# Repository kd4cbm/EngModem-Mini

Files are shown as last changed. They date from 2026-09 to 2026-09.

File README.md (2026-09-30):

# EngModem Mini

A retro dial-up-modem-styled ESP32-S3 board: RS-232 (true DCE levels via
MAX3237), a 24x2 character VFD status display, a microSD card slot, 8
status LEDs, and USB-C, built around the ESP32-S3-WROOM-1U module. Runs
[Zimodem](https://github.com/BoZimmerman/Zimodem) - Bo Zimmerman's Hayes
AT-command modem emulator/internet gateway - via the
[Zimodem-VFD](https://github.com/kd4cbm/Zimodem-VFD) fork, which adds the
VFD status display this board uses. The firmware qualified on this exact
hardware, further specialised for it, is included in [`firmware/`](firmware/).

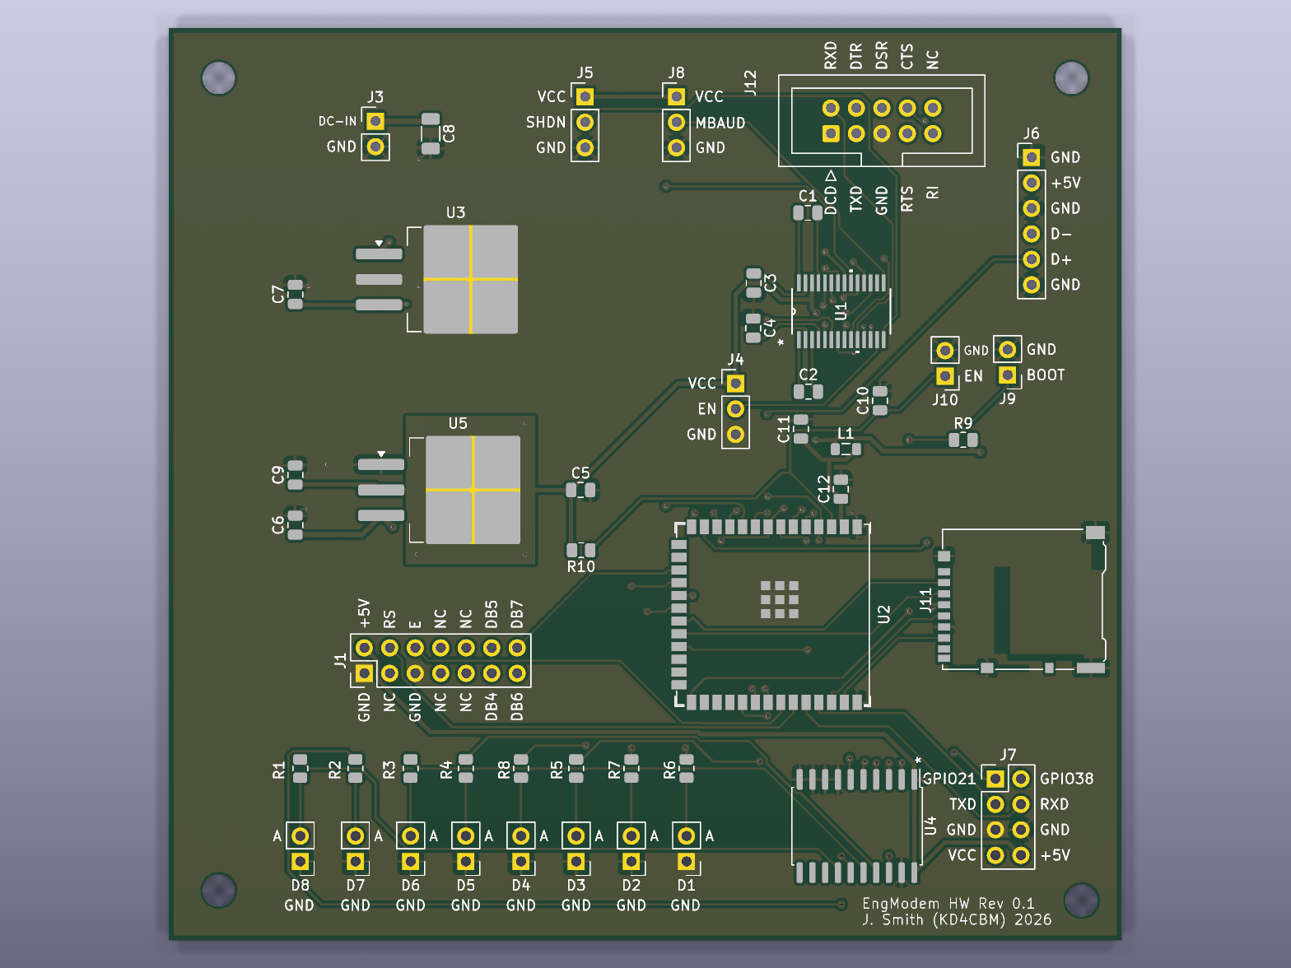
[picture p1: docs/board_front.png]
Front

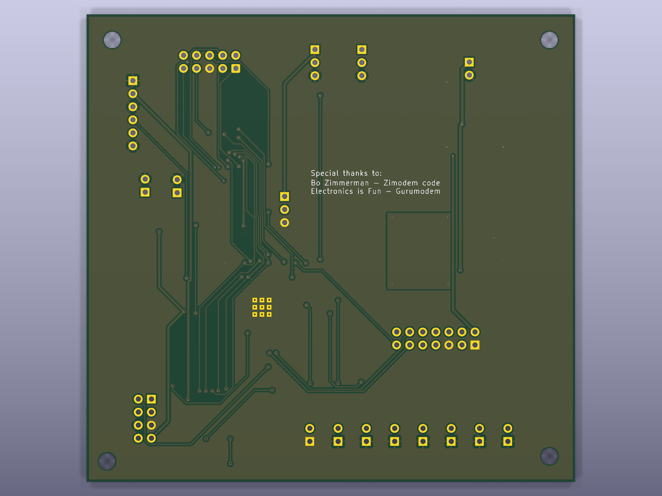
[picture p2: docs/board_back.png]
Back


## Status: Rev5 built and functionally qualified

One Rev5 board has been built, brought up and bench-qualified with the firmware
in [`firmware/`](firmware/) (revision `firmware-v7-rev1`), September 2026:
programming over USB, boot and debug UART, WiFi, microSD, the VFD, the status
LEDs, RS-232 at every rate from 300 to 921600 baud, RTS/CTS flow control, DTR,
DCD and RI, and byte-exact data integrity through TCP connections. The full
results - and, just as importantly, **what was not tested** (no rail-voltage or
signal-level measurements, single unit, no long soak, no ESD/EMC) - are in
[`docs/QUALIFICATION.md`](docs/QUALIFICATION.md).

Bring-up turned up a few things worth knowing **before you build one**:

- **J12's pin order does not match most ready-made header-to-DE-9 cables** and
  the board will appear dead with one - see [`docs/J12_CABLE_GUIDE.md`](docs/J12_CABLE_GUIDE.md).
- **Three MAX3237 jumpers (J4/J5/J8) must be fitted** - see the jumper table in
  [`docs/BRING_UP.md`](docs/BRING_UP.md#3-set-the-jumpers).
- U3/U5 are hand-soldered and U5 was substituted - see [`docs/ERRATA.md`](docs/ERRATA.md).
- **Most front-panel LEDs read inverted on boards with the original U4.** MR, TR, SD, RD and CD go
  through U4, originally a non-inverting buffer, from active-low signals, so they were lit when they
  should be dark. The firmware corrects OH, AA and HS; replacing U4 with a pin-compatible inverting
  part (a TI CD74HCT640M) fixes the rest and has been **built and verified on hardware** -
  see [`docs/ERRATA.md`](docs/ERRATA.md#e11-most-front-panel-leds-read-inverted).
  Also **check the LED order at assembly** (two LEDs were swapped on the tested unit).
- The design-stage "all pins match the firmware" check missed signal direction and LED
  polarity; nine firmware and design issues were found and eight fixed in firmware during
  qualification (the LED inversion of five LEDs needs a hardware change) - see
  [`docs/ERRATA.md`](docs/ERRATA.md#e3-earlier-pin-cross-check-missed-signal-direction) and
  [`docs/QUALIFICATION.md`](docs/QUALIFICATION.md).
- **Use RTS/CTS for long transfers.** With flow control off, a long full-speed two-way stream
  can still lose data (the receive-buffer bug behind most of that is fixed in firmware v6b) -
  see [`docs/ERRATA.md`](docs/ERRATA.md#e12-serial-receive-buffer-was-256-bytes-not-4096-fixed-in-firmware-v6b).

This is a functional qualification of a single unit, not a compliance test.
Expect further revisions.

## Special thanks

This board exists to run [Bo Zimmerman](http://www.zimmers.net)'s
[Zimodem](https://github.com/BoZimmerman/Zimodem) - the Hayes AT-command
modem emulator this whole project is built around. None of this would
have a reason to exist without that project. Thank you, Bo.

## Board overview

- ESP32-S3-WROOM-1U (external U.FL antenna), 16MB flash / 8MB octal PSRAM
- MAX3237-based RS-232 level shifting, wired as **DCE** (straight-through
  DE-9 cable to a PC/terminal) - full modem control set: TXD, RXD, RTS,
  CTS, DTR, DSR, DCD, RI
- Noritake CU24025ECPB-W1J 24x2 character VFD, direct 4-bit parallel
  drive (no I2C bridge)
- microSD card slot (Hirose DM3AT-SF-PEJM5), dedicated SPI pins
- 8 status LEDs, including 3 direct-GPIO-driven (AA/HS/OH)
- USB-C (native USB-Serial-JTAG)
- 2-layer PCB, routed with [Freerouting](https://github.com/freerouting/freerouting) 2.3.0

## Verification

**Design checks** - every revision was checked with KiCad's own tools before
being carried forward:

- **ERC**: 32/32 clean (no unsuppressed errors/warnings)
- **DRC**: 1 finding, a pre-existing benign silkscreen-overlap warning on
  U1; 0 unconnected nets
- **Footprint/schematic sync**: clean
- **Firmware/hardware cross-check (design stage)**: every GPIO the firmware
  references was traced against the schematic netlist pin-by-pin - 18/18
  matched **by GPIO number and net name**. That check did not compare signal
  *direction* and so missed a reversed RTS/CTS assignment, found later on the
  real board and fixed in the firmware; see
  [`docs/ERRATA.md`](docs/ERRATA.md#e3-earlier-pin-cross-check-missed-signal-direction).

**Hardware qualification** - a real Rev5 board, tested on the bench with the
included firmware: [`docs/QUALIFICATION.md`](docs/QUALIFICATION.md).

## Prerequisite libraries

This project uses two public third-party KiCad libraries that aren't
bundled here - install both via KiCad's **Plugin and Content Manager**
before opening the project:

- **Espressif KiCad libraries** (`com_github_espressif_kicad-libraries`) -
  ESP32-S3-WROOM-1U symbol/footprint
- **MAX3237** - U1's symbol/footprint

The project's one genuinely custom dependency, a small `RetroWiFiModem`
library providing the SOIC-20W bus-transceiver symbol/footprint used at U4
(both the original 74HCT245 and the CD74HCT640M it was replaced with share
the symbol's underlying pinout), is bundled under
[`hardware/kicad/libraries/`](hardware/kicad/libraries/) and wired up via
the project-local `sym-lib-table`/`fp-lib-table`, so it
resolves automatically - no separate install needed for that one.

## RS-232 (J12) - DE-9 female, DCE pinout

DCE pinout in the **AT/Everex header order** (header pin *n* = DE-9 pin *n*) -
wire straight-through to a DTE (PC/terminal). **Many ready-made header-to-DE-9
cables use a different (DTK/Intel) order and will not work** - read
[`docs/J12_CABLE_GUIDE.md`](docs/J12_CABLE_GUIDE.md):

| Pin | 1 | 2 | 3 | 4 | 5 | 6 | 7 | 8 | 9 |
|---|---|---|---|---|---|---|---|---|---|
| Signal | DCD | RXD | TXD | DTR | GND | DSR | RTS | CTS | RI |

Full connector/power-regulation detail (including the U3/U5 substitution
below) is in [`PIN_MAP.md`](PIN_MAP.md); a running changelog is in
[`CHANGES.md`](CHANGES.md).

## Files

- [`firmware/`](firmware/) - the qualified firmware: source, prebuilt
  binaries with checksums, and the hardware QA test scripts (start with its
  [README](firmware/README.md))
- [`docs/`](docs/) - [`BRING_UP.md`](docs/BRING_UP.md) (builder's guide:
  jumpers, first power, flashing, troubleshooting),
  [`QUALIFICATION.md`](docs/QUALIFICATION.md) (test report),
  [`ERRATA.md`](docs/ERRATA.md) (known issues),
  [`J12_CABLE_GUIDE.md`](docs/J12_CABLE_GUIDE.md) (cabling)
- [`hardware/kicad/`](hardware/kicad/) - full KiCad 10 project (schematic
  + PCB), current as of **Rev5**
- [`hardware/kicad/libraries/`](hardware/kicad/libraries/) - bundled
  custom library (see [Prerequisite libraries](#prerequisite-libraries))
- [`enclosure/`](enclosure/) - Hammond 1455U2201BK panel drill/router jigs
  (front: VFD window, LEDs, mounting holes; rear: DB9, USB-C, power
  jack/switch, boot/reset, external antenna) - see its own
  [README](enclosure/README.md) for the preliminary-hardware disclaimer
  and usage instructions
- [`manufacturing/Gerbers_EngModem-Mini_Rev5.zip`](manufacturing/Gerbers_EngModem-Mini_Rev5.zip) -
  Gerber + Excellon drill files, ready to upload to a fab
- [`manufacturing/BOM_PCBA_JLCPCB.csv`](manufacturing/BOM_PCBA_JLCPCB.csv) -
  bill of materials for the SMD parts JLCPCB will assemble, with LCSC part
  numbers verified against LCSC's own listings where a specific
  manufacturer part is called for. Common passives (resistors, most
  capacitors) intentionally list full specs with no pinned LCSC number -
  JLCPCB's basic-parts catalog is a live, dynamic search that isn't
  reliably scriptable, and these are common enough values that matching
  one at checkout takes seconds. **U3, U4 and U5 are intentionally excluded**
  - see below.
- [`manufacturing/BOM_full.csv`](manufacturing/BOM_full.csv) - every part
  on the board, including the through-hole connectors, headers, LED
  positions, and U3/U5, for your own hand-assembly shopping list
- [`manufacturing/CPL_SMD.csv`](manufacturing/CPL_SMD.csv) - placement
  (component position) file for the JLCPCB-assembled SMD parts, in
  JLCPCB's expected column format (`Designator, Mid X, Mid Y, Layer,
  Rotation`), generated directly from the PCB's real component
  coordinates. U3, U4 and U5 excluded, same as the PCBA BOM.

Gerbers + BOM_PCBA_JLCPCB + CPL_SMD together are what JLCPCB's PCBA
(assembly) order flow asks for. **Before ordering, check every SMD part's
orientation and position in JLCPCB's assembly preview tool** - their
preview renders whichever specific LCSC library part it matched to each
BOM row, using that part's own reference point, which doesn't always
agree with KiCad's footprint origin (for angle *or* position). Their
preview UI lets you nudge/rotate a part and save the correction directly,
no file regeneration needed - do that check first, especially for U1
(MAX3237EIPWR) and U2 (the ESP32 module).

### U3 and U5 - excluded from PCBA, hand-solder these

JLCPCB's placement preview surfaced a real footprint mismatch on both
regulators: the originally spec'd parts (HGSEMI LM7805S2/TR for U3, ST
LD1086D2T33TR for U5) don't reliably match this board's 3-lead D2PAK/
TO-263-3 footprint - LCSC's own listings show both as 2-lead packages
(and JLCPCB's 3D model for U3 shows "TO263-5" case marking), while ST's
LD1086 datasheet itself defines two different D²PAK mechanical variants
under one ambiguous order code. Rather than risk a bad PCBA placement,
both are DNP for JLCPCB assembly - `BOM_full.csv` lists verified
replacement parts to hand-solder instead, sourced from Mouser/DigiKey:

- **U3**: onsemi **MC7805CD2TR4G** (D2PAK-3, CASE 936) - confirmed via
  onsemi's own MC7800 datasheet: Pin 1=Input, Pin 2=Ground=Tab, Pin
  3=Output, an exact match to this footprint and the schematic.
- **U5**: TI **LM1086CSX-3.3/NOPB** (DDPAK/TO-263, package KTT; the
  qualified board uses the in-stock **LM1086IS-3.3/NOPB**, same package and
  pinout, industrial temp grade) -
  confirmed via TI's own datasheet: Pin 1=ADJ/GND, Pin 2+Tab=Output, Pin
  3=Input, an exact match to this footprint and the schematic (tab wired
  to Output by design).

### U4 - excluded from PCBA, hand-solder this

Unlike U3/U5, this wasn't a footprint mismatch - the schematic's generic 74HCT245 (non-inverting)
placed and worked fine, but reads five front-panel LEDs inverted (see
[`docs/ERRATA.md`](docs/ERRATA.md#e11-most-front-panel-leds-read-inverted)). The fix is a
pin/package-compatible **inverting** part, TI **CD74HCT640M** (SOIC-20-300mil, same footprint) - hand-swapped
on the qualified unit and verified correct (2026-09-29; a pad was pulled during desoldering and needed a
trace/pad-level repair, worth planning for). LCSC **C1548168** - 0 units in LCSC's own direct stock at
last check, ~3,000 available through LCSC's Other Suppliers channel at a 9-18 business day lead time
(checked 2026-09-29, re-verify before ordering) - excluded here pending confirmed assembly-line stock.
Must be the **HCT** variant, not HC (HC doesn't meet the 3.3V input threshold at 5V).

## Revision history

| Rev | Notes |
|---|---|
| 0-1 | Original modular layout and placement baseline |
| 2 | SD card socket swapped from a pin header to the real microSD socket (Hirose DM3AT-SF-PEJM5); full reroute |
| 3 | Second SD placement experiment; full reroute; 69 net-derived pin-function silkscreen labels added across every header/LED footprint |
| 4 | Dedicated 0.5mm net class for `/DC-IN`; solid (non-thermal-relief) zone connections on regulator/shield GND tabs; local `/VCC` copper pour + thermal vias around U5; ESP32 power-filter components (L1/C11/C12) relocated for shorter real routed-copper paths to U2 |
| 5 | **Current** - via stitching added under U2's ground-pad cluster (9 vias, exposed copper + matching pads mirrored onto the bottom layer) for bottom-side hand-soldering access; keepout zone added around that cluster, full rip/reroute; U3/U5 excluded from PCBA per the footprint mismatch below |

## License

Hardware design files (schematic, PCB) are released under
[CERN-OHL-S v2](https://cern-ohl.web.cern.ch/) - a strongly-reciprocal
open hardware license: modifications to these design files must be
released under the same license if you distribute hardware built from
them. See [LICENSE](LICENSE).

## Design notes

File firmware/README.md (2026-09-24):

# EngModem Mini firmware (Zimodem-VFD, `ENGMODEM_MINI_BOARD`)

This folder is the firmware that was qualified on the real EngModem Mini
hardware - see [`../docs/QUALIFICATION.md`](../docs/QUALIFICATION.md) for what
was tested and how. It is a fork of Bo Zimmerman's
[Zimodem](https://github.com/BoZimmerman/Zimodem) (Hayes AT-command modem
emulator / internet gateway), via the
[Zimodem-VFD](https://github.com/kd4cbm/Zimodem-VFD) fork that adds the 24x2 VFD
status display, further specialised for this board with the
`ENGMODEM_MINI_BOARD` build flag (already `#define`d near the top of
`zimodem/zimodem.ino`).

**Revision:** `firmware-v7-rev1` - Zimodem 4.0.3 base, sdk v5.5.5,
ESP32 Arduino core 3.3.11. Every change from upstream is listed in
[`CHANGES.md`](CHANGES.md); the numbered fix rounds (v1 to v7) are listed
there too. Apache-2.0, see [`LICENSE`](LICENSE) and [`NOTICE`](NOTICE) (the
*hardware* in the rest of this repo is CERN-OHL-S v2).

| Folder / file | What it is |
|---|---|
| [`zimodem/`](zimodem/) | Arduino sketch source (`zimodem.ino` + tabs, bundled `src/libssh2`) |
| [`bin/`](bin/) | The exact binaries flashed and qualified on the board (v7-rev1), with `SHA256SUMS.txt` |
| [`tests/`](tests/) | The Python hardware QA scripts used for qualification |
| [`PIN_MAP.md`](PIN_MAP.md) | ESP32-S3 GPIO to signal mapping this firmware expects |
| [`CHANGES.md`](CHANGES.md) | Full change list vs. upstream, with the reason for each |

## Quick start: flash the prebuilt firmware

You need Python and [esptool](https://github.com/espressif/esptool)
(`pip install esptool`; the commands below are esptool 5.x syntax - with 4.x
use `write_flash` instead of `write-flash`).

1. **Jumpers first** - the board will not talk RS-232 without them. See
   [`../docs/BRING_UP.md`](../docs/BRING_UP.md#3-set-the-jumpers). In short:
   **J9 (BOOT) must be OFF** to run the firmware, J4 = 2-3, J5 = 1-2,
   J8 = 1-2.
2. Connect USB (header **J6**) and find the port (Windows: Device Manager >
   Ports; Linux: `/dev/ttyACM0`).
3. Flash the four images. Run from inside `firmware/bin/`:

```bash
python -m esptool --chip esp32s3 -p COM7 -b 460800 \
  --before default-reset --after hard-reset \
  write-flash --flash-mode dio --flash-freq 80m --flash-size 16MB \
  0x0     zimodem.ino.bootloader.bin \
  0x8000  zimodem.ino.partitions.bin \
  0xe000  boot_app0.bin \
  0x10000 zimodem.ino.bin
```

Replace `COM7` with your port. The chip resets itself into the bootloader over
native USB, so no button presses were needed on the tested board. If it does
not enter the bootloader, fit the **J9 BOOT** jumper, briefly short **J10 (EN)**
or power-cycle, flash, then **remove J9 again** and reset.

A single merged 16 MB image (`zimodem.ino.merged.bin`, flash at `0x0`) is
attached to the matching GitHub Release. Its layout was checked byte-for-byte
against the four images above; the four-image command is what was run on the
tested hardware.

Verify what you flashed against [`bin/SHA256SUMS.txt`](bin/SHA256SUMS.txt)
(`sha256sum -c SHA256SUMS.txt` in `bin/`).

## Debug output (important)

Boot messages, the `AT&O88` signal log and the
`Flow control pins: CTS(in)=17 RTS(out)=18` line are printed on the
**debug UART - header J7** (pin 3 = board TX, pin 4 = board RX, pins 5/6 =
GND; 3.3 V logic, 115200 8N1), **not** over USB. A 3.3 V USB-serial adapter
on J7 is all you need. (Earlier text in the upstream fork's README, saying
USB-CDC is the debug path, is wrong for this code.)

A healthy boot on the QA'd board shows, among other lines:
`External SD card initialized.`, `Connected to <ssid> with IP <ip>.` and
`Flow control pins: CTS(in)=17 RTS(out)=18`.

## First use

- Factory default is **1200 baud, 8N1, flow control off**. The unit that was
  qualified was configured to 115200 (`ATB115200`, reconnect the terminal at
  115200, then `AT&W` to save).
- `AT+CONFIG` walks you through WiFi (2.4 GHz only) and other settings.
- `ATI` shows version, chip and current IP.
- `AT&K3` enables RTS/CTS flow control, `AT&K0` disables it. Flow control was
  **left off** in qualification except during the flow-control tests.
- `ATS63=2` makes the modem hang up when the host drops DTR (verified on this
  board with firmware v3 and later; not possible before).
- The VFD shows WiFi/IP, TX/RX activity, baud rate and flow-control mode.
  `AT$VFDB=0..4` sets brightness (0 = off, 4 = 100 %).
- Full command reference: upstream Zimodem's documentation, plus the
  `AT+SHELL` SD-card shell (`?` lists its commands).

## Building from source

Tested with `arduino-cli` 1.5.2 and the `esp32:esp32` core **3.3.11**. No extra
libraries are needed (libssh2 is bundled under `zimodem/src`).

```bash
arduino-cli compile \
  --fqbn esp32:esp32:esp32s3:FlashSize=16M,PSRAM=opi,PartitionScheme=default_8MB,CDCOnBoot=cdc \
  --build-path build zimodem
```

That produces the four images above under `build/` (39 % of program storage,
17 % of RAM). A different core version may change behaviour: the v4 serial-to-TCP
fix exists because of how core 3.x's socket write retries behave, and the v6b
receive-buffer fix because core 3.x only accepts `setRxBufferSize()` before
`begin()` (see [`CHANGES.md`](CHANGES.md)). Rebuilding will not reproduce the released
binaries bit-for-bit (timestamps are embedded), which is why the exact
released binaries and their checksums are included.

## Known limits of this revision

- **Recommended baud rate: 230400 if your UART can do it, otherwise 115200.** 115200 is the rate any
  UART supports, including plain onboard PC ports (the native 16550 COM port used in qualification
  topped out there). 230400 is the fastest rate we can guarantee, and only on UARTs that accept custom
  rates above 115200 (typically USB-serial adapters); not every such adapter supports 460800 or
  921600. Going faster buys little: connected-mode throughput is flat at ~17.3-17.9 KB/s from 230400
  through 921600 (WiFi/CPU-bound, not line-bound), and one-way transfers plateau near 30.8 KB/s from
  460800 up. If your UART accepts custom rates you can likely exceed 230400 by a decent margin, but
  that is not guaranteed on all hardware. The modem itself ran byte-exact at 460800 and 921600 on the
  USB-FTDI adapter used in qualification.
- **Flow control off has a ceiling.** With RTS/CTS off and data flowing in *both* directions
  at full 115200 line rate for a long time (tested with a PC echo server), the modem forwards slightly
  slower than a full-speed sender can push, so a very long stream can still lose data. Measured on the
  qualified unit: echo streams up to 40 KB were clean in all 20 runs, sustained ~60 KB lost data in one
  of two runs; one-way transfers (PC sending, network receiving) were lossless up to 100 KB. **Use
  RTS/CTS (`AT&K3`) for long transfers** - it was byte-exact in every test, including 100 KB streams at
  230400, 460800 and 921600 baud. An occasional "1 byte short on the echo return" seen in flow-off echo
  runs also appears in earlier revisions; its cause is unknown.
- Serial-to-TCP data is buffered for up to 10 ms (2 ms after the last byte) to avoid the stall
  described in `CHANGES.md`. Keystroke round-trip through a TCP echo on a home network measured a median
  of 45-61 ms; the 365-430 ms worst-case tail is ESP32 WiFi power-save.
- In *command mode* the modem processes roughly 4.6 KB/s regardless of line speed; flow control keeps
  data intact above that, but it is a ceiling. In connected (stream) mode throughput measured
  ~11 KB/s at 115200 and ~17.5 KB/s at 230400-921600 (WiFi/CPU-bound, not line-bound).
- The VFD init is now self-repairing (resync at boot, re-sent about once a second during the 7 s
  splash window). If the display is blank, check the J1 wiring first, then reset.
- **LED behaviour:** AA, HS and OH are corrected in firmware (they light when active). MR, TR, SD, RD
  and CD are driven through U4 in hardware and read *inverted* on Rev5 as built - see
  [`../docs/ERRATA.md`](../docs/ERRATA.md#e11-most-front-panel-leds-read-inverted).
- The `tests/` scripts have bench-specific COM ports and IP addresses hard-coded at the top (or take
  `QA_PORT`); edit them before use (see [`tests/README.md`](tests/README.md)).

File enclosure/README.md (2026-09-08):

# Enclosure Panel Jigs

## ⚠️ Preliminary - not yet used on real hardware

**These jigs have not been printed, fitted, or test-drilled on a real
Hammond enclosure panel yet.** All positions are derived from real
sourced data (the actual Noritake VFD mechanical drawing, the real
Hammond 1455U2201BK STEP-derived geometry, a standard reference
drawing for the DB9 cutout), not guesses - but "derived from real
data" is not the same as "verified against physical hardware." In
particular, **the DB9 cutout profile involved one genuine interpretive
call** reconciling two sub-dimensions on the reference drawing that
didn't cleanly agree pixel-for-pixel (see below) - test-fit it against
the actual motherboard DB9 shell before committing to final material.
Treat everything here as a first-pass draft.

## Enclosure

**Hammond 1455U2201BK** - extruded aluminum, card-slot mount, black
finish. 220 x 191 x 66mm overall, max PC board size 220 x 186.48mm.
Real geometry (`1455U2201_REAL_end_panel.stl`, `1455U2201_REAL_bezel.stl`,
included here) was extracted directly from Hammond's own factory STEP
file, not estimated from the dimensioned PDF drawing alone.

## Tool spec

**1/8" (3.175mm) bit for both drilling and routing** - the same
physical bit does both jobs. The router bit has **no bearing**: the
non-cutting shaft rides the template edge directly, shaft diameter
equals cutting diameter, so template openings are cut to the *exact*
final dimensions with no offset compensation.

**Workflow, in order:**
1. Register the jig on the panel using the wrap-around registration
   pocket (sized to the panel's real outer edge, ~0.15mm clearance for
   a snug slip-fit).
2. Drill all guide holes in "jig 1" (main pass).
3. Swap to "jig 2" (same registration, offset holes) and drill those
   too - the two passes interleave to roughly half the effective hole
   spacing, so adjacent holes overlap and the perimeter should
   mostly punch free by hand with minimal filing.
4. Punch/break out the remaining thin webs between holes by hand.
5. Swap to the router template jig. With the panel still registered
   in the same pocket, run the router bit's shaft along the template's
   inner edge to smooth the already-open edge to the final line.
   **This is a light finishing pass on already-open material, not a
   through-cut** - the two-step drill-then-route sequence exists
   specifically so the router bit is never cutting through solid
   material while its shaft rides directly against the printed jig,
   which could otherwise generate enough friction heat to soften the
   jig itself.

## Print settings

Geometry settings below apply regardless of material. Material-specific
temperature/cooling/retraction profiles for PrusaSlicer follow after.

- **40-50% infill**, gyroid or cubic pattern.
- **4+ perimeter walls, 3+ solid top/bottom layers** - more important
  than infill % here. The thin webs between adjacent drill-guide holes
  (as tight as ~1.5-2mm at this spacing) are almost entirely perimeter
  shell, not infill lattice, and the top plate needs to stay flat and
  accurate under repeated drill pressure.
- **Material**: PLA (or PLA Pro+/PLA+) is fine for the drill guides -
  no heat exposure there. **Use PETG for the router template
  specifically** - cheap insurance given the tool-shaft friction-heat
  concern above; PETG's heat-deflection temp (~70-80°C) is meaningfully
  higher than standard PLA's (~50-55°C) or PLA Pro+/PLA+'s (~55-60°C).
  A single PLA Pro+ spool for all six jigs is a reasonable simplification
  if you'd rather not swap filament, given its HDT edge over plain PLA -
  PETG is still the safer choice for the router template alone.

### Dimensional accuracy - read this before printing either material

The offset drill guides have very little built-in clearance between the
guide hole and the actual bit/hardware (down to ~0.05mm radial on some
holes), and FDM printers reliably print round holes **undersized** -
typically 0.1-0.3mm on a 0.4mm nozzle, from melt-flow rounding at the
perimeter/infill transition. Left uncorrected, the bit may not seat in
the guide holes at all.

- **PrusaSlicer -> Print Settings -> Advanced -> Slicing -> XY size
  compensation**: leave *Contour* at 0 (don't touch it, or the
  registration-pocket fit against the panel edge gets loose); set
  **Hole compensation to +0.10 to +0.15mm** for PETG, **+0.08 to
  +0.12mm** for PLA/PLA Pro+ (PLA holds circular holes slightly truer
  than PETG at the same nozzle temp).
- **Elephant's foot compensation**: 0.15-0.2mm for PETG, 0.10-0.15mm
  for PLA Pro+ - PETG's first layer squishes more, which shows up as
  undersized short features like the LED pilot holes.
- **Print a small test coupon first** - a plate with a few holes at the
  actual nominal diameters used here (2.50mm, 3.175mm, 3.275mm) -
  before committing to a full jig print. Test-fit the real bit/hardware
  and adjust the hole-compensation number from that measurement rather
  than trusting the figures above blindly; every printer/filament
  combo shifts this slightly.

### PETG (PrusaSlicer)

- **Nozzle**: 235°C first layer, 230°C other layers (typical generic
  PETG range 230-245°C - start at 230 and only raise it if layers
  aren't bonding; higher temps string more).
- **Bed**: 80-85°C first layer, 80°C other layers.
- **Cooling**: 0% fan for layers 1-2, ramp to 30-40% by layer 4-5, cap
  around 40-50% max - PETG wants less aggressive cooling than PLA.
  Min layer time 15-20s.
- **Retraction**: direct drive 0.8-1.2mm @ 25-35mm/s; Bowden 4-6.5mm @
  25-40mm/s. Enable "wipe while retracting" if available - PETG
  strings badly if this is loose.
- **Speed**: perimeters 40mm/s, external perimeters 25-30mm/s, infill
  50-60mm/s, first layer 20mm/s.
- **Bed adhesion**: PETG bonds aggressively to bare PEI - use a thin
  glue-stick layer or you risk peeling the sheet coating on removal.
  5mm brim recommended on the router template and larger drill guides.
- **Dry the filament first** if it's been open/humid - 55-65°C for
  4-6 hrs. PETG is hygroscopic; moisture shows up as weak layers,
  worst place to have it is the router template.

### PLA Pro+ / PLA+ (PrusaSlicer)

- **Nozzle**: 215-220°C first layer, 210-215°C other layers (generic
  "Pro"/"+" PLA blends run ~10-15°C hotter than plain PLA for their
  improved toughness/HDT - check your specific spool's TDS if you have
  one, but this range covers most eSUN PLA+/Polymaker PolyLite PLA
  Pro/Overture PLA+ style filaments).
- **Bed**: 60°C first layer, 55-60°C other layers.
- **Cooling**: 100% fan from layer 2 onward (drop to ~60% only if you
  see poor interlayer bonding) - PLA-family filaments want aggressive
  cooling, the opposite of PETG.
- **Retraction**: direct drive 0.6-0.8mm @ 35-45mm/s; Bowden 3-5mm @
  40-60mm/s - PLA strings much less than PETG, so this is more
  forgiving to tune.
- **Speed**: perimeters 45-55mm/s, external perimeters 30-35mm/s,
  infill 60-80mm/s, first layer 20mm/s.
- **Bed adhesion**: less aggressive to PEI than PETG - plain glue
  stick or even bare textured PEI is usually fine. 5mm brim still
  recommended on the larger flat jigs for warp resistance.
- **Note**: PLA Pro+'s ~55-60°C HDT is still well below PETG's
  ~70-80°C - fine for the drill guides (no heat exposure), but PETG
  remains the better choice specifically for the router template given
  the friction-heat concern in the workflow above.

## Jigs

### Front panel (VFD + LEDs + mounting holes)
- `jigs/front_panel_drill_guide.stl` - 46 holes: 34 around the VFD
  viewing window perimeter, 8 LED center-pilots, 4 VFD mounting-hole
  pilots.
- `jigs/front_panel_drill_guide_2_offset.stl` - 34 offset holes,
  VFD window perimeter only (no LEDs), for the interleave pass.
- `jigs/front_panel_router_template_vfd.stl` - exact 82.80 x 11.50mm
  window opening (verified against Noritake's real CU24025ECPB-W1J
  mechanical drawing, DOC NO. 37813 - not the datasheet text, the
  actual dimensioned drawing).

VFD mounting holes: 4x ⌀2.50mm, 113.00mm horizontal x 31.00mm vertical
spacing (center-to-center), each hole 2.50mm inset from its nearest
edge of the VFD's 125x36mm envelope. Cross-checked against a direct
caliper measurement on the physical unit during development - vertical
spacing matched exactly; horizontal spacing required correcting an
initial misreading of the drawing (see PROJECT_HANDOFF.md in the main
repo for the full trace of that correction) before it matched too.

**Mounting hole diameter - unresolved discrepancy, verify before ordering
hardware**: three different figures have turned up across sources - 2.50mm
(the doc-37813 mechanical drawing used for the jig above), "3.5mm dia"
(a text note on an older Noritake datasheet PDF for the same part), and
2.25mm (an earlier direct caliper measurement on the physical unit).
Re-check with calipers on the real hole before buying standoffs/screws.

**Standoff length: 7.74mm.** Found on that same older datasheet (not on
the doc-37813 drawing, which doesn't dimension module depth at all) - a
side cross-section shows 1.6mm PCB thickness, then 7.74mm from the PCB's
top surface up to the bottom of the display housing's own internal
support legs, then the housing block itself above that (13.0mm total,
PCB back to housing front face). The 7.74mm figure is the one that
matters for an external standoff: since the front-view drawing shows the
4 corner mounting holes on the same outline as the housing/bezel frame
(not a separate smaller PCB shape), the screw most likely runs through
the PCB from behind with the housing's front bezel referencing the panel
directly - meaning the standoff just needs to reproduce the gap the
module's own legs already dictate. 7.74mm isn't a stock standoff length
(common metric standoffs run 5/6/8/10mm) - either use an 8mm standoff
plus a ~0.25mm shim, or 3D-print a custom 7.74mm spacer.

LEDs: pilot-center only (not full perimeter) - 3mm THT LEDs with 5mm
panel-mount snap-in clips, drilled to full size afterward at the
marked centers. See [`LED_LABELS.md`](LED_LABELS.md) for the 8 LED
functions, their real left-to-right order, and the CNC-engraving plan
(F-Engrave settings, V-bit choice, per-label coordinates) for the 2-letter
labels under each one.

### Rear panel (DB9, USB-C, power, switches, antenna)
- `jigs/rear_panel_drill_guide.stl` - DB9 + USB-C perimeters, plus
  pilot-center holes for boot, reset, power switch, power jack, and the
  external antenna connector.
- `jigs/rear_panel_drill_guide_2_offset.stl` - offset interleave pass
  for the DB9/USB-C perimeters.
- `jigs/rear_panel_router_template.stl` - both non-round openings (DB9
  window, USB-C window) in one template, single registration.

Layout (see `renders/rear_panel_layout.png` for the full dimensioned
diagram), left to right:

| Feature | Size | X position (mm, panel-local) |
|---|---|---|
| USB-C (TC005 panel-mount jack) | 10.5 x 5.2mm opening, 2x⌀2.0mm mount holes @14.5mm spacing | 30.0 |
| Reset | pilot, finish to ⌀7mm | 52.0 |
| Boot | pilot, finish to ⌀7mm | 68.0 |
| DB9 | standard DE-9 cutout | 95.5 (centered) |
| Power switch | pilot, finish to ⌀6mm | 134.0 |
| Power jack | pilot, finish to ⌀11mm | 155.0 |
| SMA/RP-SMA antenna | pilot, finish to ⌀9.5mm (3/8") | 175.0 |

All items sit on the panel's shared Y=33mm centerline. Checked against
the enclosure's real internal floor rail (a 152.4 x 4.29mm structural
rail extracted from Hammond's own STEP file, sitting along the very
bottom edge of the panel) - everything above is 27mm+ clear of it
vertically, which is what actually matters here (the rail only occupies
the bottom 4.29mm of the panel's 66mm height, so X-position relative to
it is not the real constraint). Corner mounting-screw-boss positions
were not independently extracted from the STEP file - generous edge
margins (9mm+ between adjacent features, 20mm+ at the outer edges) are
used as a conservative stand-in.

**USB-C, Boot, and Power switch/jack are grouped deliberately, not just
for space**: USB-C sits with Reset/Boot as a "programming cluster" since
flashing an ESP32 means holding BOOT, tapping RESET, and having USB
connected all at once - keeping them adjacent mirrors common dev-board
layout. The power switch/jack form their own cluster on the opposite
side. SMA sits outboard of the power cluster, isolated with its own
clearance - **U2 (the ESP32-S3 module, carrying the U.FL antenna feed)
sits ~48mm away on the opposite, front-panel-facing edge of the PCB**,
confirmed via a direct pcbnew position query - so the U.FL pigtail runs
most of the board's length regardless of exactly where on the rear panel
the antenna connector sits; this board's linear (not switching)
regulators mean there's no significant local EMI source near the power
jack to steer away from either.

DB9 cutout profile sourced from Winford Engineering's "Recommended D-Sub
Connector Panel Cutouts" reference drawing (standard generic DE-9,
matching a standard motherboard DB9 connector) - a compound shape, not
a plain rectangle: a rounded-rect main body (20.574 x 11.43mm, corner
radius 3.81mm) with two small jackscrew-clearance lobes (3.175mm dia)
merged onto its sides, positioned so their outer edge reaches the
drawing's explicit 24.892mm mounting-hole span.

**The interpretive call**: two of the reference drawing's sub-dimensions
(0.81in body width, 0.51in a secondary width) didn't cleanly reconcile
with the visible lobe geometry when read pixel-for-pixel off the
rendered PDF. The lobe placement used here reconciles them by anchoring
the lobes' *outer* edge to the drawing's unambiguous 0.98in mounting-hole
span - a reasonable, documented reconstruction, but not verified against
a real DB9 shell the way the VFD dimensions were against the real
Noritake drawing and a physical caliper check. **Test-fit before
cutting final material.**

**Also flagged**: the same reference notes 0.062in (1.57mm) max panel
thickness for standard-length jackscrews. This panel (~1.7mm) is at or
slightly past that - extra-long jackscrews (the reference calls out
Winford's own DJSK-35.0-A) may be needed instead of whatever ships
with the connector.

**USB-C is a TC005**, a generic panel-mount USB-C connector
("TYPE-C-16P" marking, 16-pin/full-data variant of this shell; the same
TC005 body is also sold with 2-pin power-only and 5-pin data-only
contact boards, panel footprint identical across all of them). Confirmed
via two independent images - an initial low-resolution supplier photo,
then a full multi-view dimensioned factory drawing (portrait-oriented,
same numbers, axes swapped) that matched every number exactly. The
opening's corner radius (flat sides, eased corners only - not the oval
shape of a bare USB-C connector tongue) is a visual estimate, not an
explicit drawing dimension - verify against the real part before
routing final material.

**SMA/RP-SMA note**: RP-SMA (reverse-polarity, the far more common type
on consumer WiFi antennas/pigtails due to FCC Part 15 rules) uses the
identical mechanical bulkhead shell and 3/8"-32 UNEF thread as standard
SMA - the "reverse polarity" only swaps which side carries the male/
female center pin. Same 9.5mm panel hole either way; just confirm the
pigtail you order is genuinely RP-SMA to mate with your antenna.

## Renders

- `renders/rear_panel_layout.png` / `renders/front_panel_layout.png` -
  dimensioned 2D layout diagrams for each panel, used to verify hole
  positions and clearances before generating the jig STLs above.
- `renders/led_label_layout.png` - placement check for the 8 two-letter
  LED labels (see [`LED_LABELS.md`](LED_LABELS.md)) - centered under
  each LED hole, ready to reference in F-Engrave.
- `renders/vfd_jig1_layout.png` / `renders/vfd_interleave.png` /
  `renders/db9_shape.png` / `renders/db9_layout.png` - earlier
  schematic hole-position layouts from initial jig development.

None of the above are photos of a printed/fitted jig.

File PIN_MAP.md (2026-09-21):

# EngModem Mini - Hardware Pin Map

This file covers the board's **external connectors** - what plugs into it
and how those pins map to real-world signals. For the internal ESP32-S3
GPIO-to-signal mapping (which pin drives what inside the firmware), see
the firmware's own
[`PIN_MAP.md`](firmware/PIN_MAP.md) -
duplicating that table here would just drift out of sync over time, so
this file stays scoped to the board's edge connectors and power system.

## RS-232 (J12) - DE-9 female, DCE pinout

Verified pin-by-pin against the schematic netlist, not assumed from
convention. The header pin number equals the DE-9 pin number (the
**AT/Everex** header order), so wiring J12 1:1 to a DE-9 gives the standard
DCE pinout and a normal straight-through PC serial cable works (no null-modem).
**But many ready-made 2x5-header-to-DE-9 cables use a different (DTK/Intel)
order and will not work** - see [`docs/J12_CABLE_GUIDE.md`](docs/J12_CABLE_GUIDE.md).

| Pin | Signal | Full name | Direction (modem/DCE POV) |
|---|---|---|---|
| 1 | DCD | Data Carrier Detect | Output (modem asserts) |
| 2 | RXD | Received Data | Output (modem transmits here - host receives) |
| 3 | TXD | Transmitted Data | Input (host transmits here - modem receives) |
| 4 | DTR | Data Terminal Ready | Input (host asserts) |
| 5 | GND | Signal Ground | - |
| 6 | DSR | Data Set Ready | Output (modem asserts) |
| 7 | RTS | Request To Send | Input (host asserts) |
| 8 | CTS | Clear To Send | Output (modem asserts) |
| 9 | RI | Ring Indicator | Output (modem asserts) |

Pins 2/3 are named from the DTE's (host's) point of view, so the modem's
own UART TX actually drives pin 2 and its RX reads pin 3 - the opposite
of what the names alone suggest.

**RTS/CTS direction (verified on hardware):** on this board the PC's RTS
arrives on ESP32 GPIO17 (an *input*, the firmware's CTS) and the ESP32 drives
the PC's CTS from GPIO18 (an *output*, the firmware's RTS) - the reverse of
the DevKitC-1 assignment. `firmware-v2` and later handle this.

The connector's footprint (`IDC-Header_2x05_P2.54mm_Vertical`) has a 10th
pad beyond the standard 9 signal pins (`unconnected-(J12-Pin_10-Pad10)`
in the netlist) - a mechanical/shield tab on the specific part, not a
signal. Nothing to wire there.

## Jumpers, USB and debug headers

| Ref | Function | Tested setting |
|---|---|---|
| J4 | MAX3237 `EN` (pin 1 VCC, 2 signal, 3 GND) | 2-3 |
| J5 | MAX3237 `SHDN` | 1-2 |
| J8 | MAX3237 `MBAUD` (1-2 = MegaBaud up to ~1 Mbps) | 1-2 |
| J9 | ESP32 `BOOT` (GPIO0 to GND) | **off** to run the firmware |
| J10 | ESP32 `EN` (short to GND to reset) | open |
| J3 | DC in: 1 = `/DC-IN`, 2 = GND | - |
| J6 | USB-C signal breakout: 1 GND, 2 +5 V net, 3 GND, 4 D-, 5 D+, 6 GND | - |
| J7 | 2x4 expansion + **debug UART**: 1 GPIO21, 2 GPIO38, **3 TX (GPIO43)**, **4 RX (GPIO44)**, 5-6 GND, 7 3.3 V, 8 +5 V | - |

Details, and why J4/J5/J8 must be fitted, are in
[`docs/BRING_UP.md`](docs/BRING_UP.md#3-set-the-jumpers).

## VFD (J1) - 14-pin header

Drives a Noritake CU24025ECPB-W1J 24x2 character VFD directly over its
4-bit parallel bus (RS, E, DB4-7) - no I2C bridge, no second
microcontroller. R/W is hardwired to GND on the VFD module itself. See
the firmware repo's `PIN_MAP.md` for which GPIO drives which line.

## microSD (J11)

Hirose DM3AT-SF-PEJM5 push-push socket, fully SMD, on the ESP32-S3's
non-default SPI pins (CS/MOSI/MISO/SCK) - requires an explicit `SPIClass`
instance in firmware rather than the default `SD.begin(cs)`. See the
firmware repo's `PIN_MAP.md` for the exact GPIO assignment.

## Power regulation - U3, U5

Two D2PAK/TO-263-3 linear regulators supply the board's rails: **U3**
(5V) and **U5** (3.3V). Neither is GPIO-mapped.

**Both originally spec'd parts don't reliably match this board's 3-lead
footprint** - a real, datasheet-confirmed mismatch, not a JLCPCB-preview
quirk. Verified replacements (pin/tab-matched to the existing footprint,
confirmed against each manufacturer's own datasheet):

| Ref | Rail | Originally spec'd | Verified replacement | Package |
|---|---|---|---|---|
| U3 | 5V | HGSEMI LM7805S2/TR | onsemi **MC7805CD2TR4G** | D2PAK-3, CASE 936 |
| U5 | 3.3V | ST LD1086D2T33TR | TI **LM1086CSX-3.3/NOPB** (qualified board: **LM1086IS-3.3/NOPB**, same package/pinout, in stock when CSX was not) | DDPAK/TO-263, package KTT |

- **U3** (onsemi MC7800 datasheet): Pin 1=Input, Pin 2=Ground=Tab, Pin
  3=Output.
- **U5** (TI LM1086 datasheet): Pin 1=ADJ/GND, Pin 2+Tab=Output, Pin
  3=Input - matches this board's design intent, which wires the tab pad
  to Output rather than the more common Ground.

Full sourcing detail (why the originals were excluded, JLCPCB PCBA
status) is in [`manufacturing/BOM_full.csv`](manufacturing/BOM_full.csv)
and the README's [manufacturing section](README.md#files).

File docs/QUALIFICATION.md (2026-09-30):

# EngModem Mini Rev5 - hardware qualification report

**Status: one Rev5 board was built, brought up and functionally qualified,
19-22 September 2026.** Sections 1-3 record the first pass (firmware v1 to v4,
`firmware-v4-rev1`); firmware-v6b-rev1 re-qualification is in
[section 5](#5-re-qualification-on-firmware-v6b-rev1); the firmware in this
repository, `firmware-v7-rev1`, is in [section 6](#6-re-qualification-on-firmware-v7-rev1).
Everything here was run on real hardware. This is a *functional bench qualification of a single
unit*, not a compliance or environmental test - see
[What was not tested](#what-was-not-tested) before relying on the board for
anything beyond that.

Related documents: [`BRING_UP.md`](BRING_UP.md) (how to build one),
[`ERRATA.md`](ERRATA.md) (known issues), [`J12_CABLE_GUIDE.md`](J12_CABLE_GUIDE.md),
[`../firmware/`](../firmware/) (firmware, binaries and the test scripts).

## 1. Unit and setup

| Item | Detail |
|---|---|
| Design tested | Rev5. The PCB, schematic and Gerbers in this repo are byte-identical to the project owner's local Rev5 files that the board was ordered from. |
| Assembly | SMD parts as per the JLCPCB PCBA files in `manufacturing/`; **U3 and U5 and the through-hole parts hand-soldered.** U3 = onsemi MC7805CD2TR4G, U5 = TI LM1086IS-3.3/NOPB. |
| Module | ESP32-S3-WROOM-1U, identified over USB as ESP32-S3 (QFN56), 8 MB PSRAM, 16 MB flash. |
| Jumpers | J4 = 2-3, J5 = 1-2, J8 = 1-2 (MegaBaud), J9 (BOOT) off. |
| Firmware | Zimodem 4.0.3 fork, sdk v5.5.5, ESP32 Arduino core 3.3.11; final = `firmware-v4-rev1` (SHA-256s in [`../firmware/bin/SHA256SUMS.txt`](../firmware/bin/SHA256SUMS.txt)). |
| Host | Windows 11 PC, Python 3 + pyserial; modem port = J12 wired 1:1 to a DE-9 breakout ([cable guide](J12_CABLE_GUIDE.md)); separate 3.3 V USB-serial adapter on J7 for the debug UART; USB (J6) for flashing. |
| Network | Board on a home 2.4 GHz WiFi network; PC on the same LAN subnet running a TCP echo/sink server for the connection tests. |
| Modem settings | 115200 8N1 (saved configuration). Flow control **off** except where a test says otherwise. Nothing changed by the tests was saved. |

## 2. Results

"Fw" is the firmware revision the test was passed on (the fix history is in
section 3). Counts are the automated checks in `firmware/tests/`.

### Board functions

| Function | Result | Fw | Basis |
|---|---|---|---|
| Programming over USB | Pass | v1-v4 | esptool over native USB, auto-reset, each image hash-verified after write |
| Boots, debug UART | Pass | v1-v4 | Boot log on J7 at 115200 (SD init, WiFi join, pin assignment line); nothing on USB (by design) |
| WiFi | Pass | v1-v4 | Joined the network, got an IP address |
| microSD | Pass | v1-v4 | "External SD card initialized." at boot; SD shell worked (owner-verified) |
| 24x2 VFD | Pass | v1-v4 | Working after a loose wire was corrected (owner-verified); J1 verified pin-for-pin against the VFD datasheet |
| Status LEDs | Working, but **most read inverted** (see [ERRATA E11](ERRATA.md#e11-most-front-panel-leds-read-inverted)) | v1-v6b | Owner-reported working at first; polarity was checked later. Physical left-to-right order verified with a blink test on the unit |
| Regulators U3 / U5 | Functional | - | Board runs with both fitted; **voltages were not recorded** (see below) |

### RS-232 and modem-control lines

| Test | Result | Fw |
|---|---|---|
| Serial through J12/DE-9 (AT/OK, banner) | Pass, **only with 1:1 wiring** - a DTK/Intel cable failed (see [errata E1](ERRATA.md#e1-j12-pin-order-differs-from-common-bracket-cables)) | v1-v4 |
| Baud sweep 300, 1200, 2400, 9600, 19200, 38400, 57600, 115200, 230400, 460800, 921600 (AT answers, RTS holds/releases output at each rate) | **50/50** | v3, v4 |
| Hardware RTS/CTS suite (idle levels; output held while PC RTS low, released when high; modem drops CTS when its RX buffer fills; recovers) | **14/14** | v2, v3, v4 (v1: **fail** - CTS did not respond) |
| PC-side CTS stays asserted across `AT&K3`/`AT&K0` cycles | **13/13** | v3, v4 (v2: fail) |
| DTR read path (firmware sees PC DTR drop/return, 3 cycles) | Pass | v3, v4 (v2: fail) |
| Hang up on DTR drop (`ATS63=2`), twice, plus `ATS63=0` control | **18/18** | v4 |
| DCD: asserted on connect, released on hang-up (PC line on v3 and v4; the firmware's own signal log was also checked, on v3) | Pass | v3, v4 |
| RI / incoming call: RING text, RI pulsing on the ~3 s ring cadence, `ATA` answer, DCD on, data both ways, RI clears, hang-up | **20/20** | v4 |
| Command-mode echo integrity under RTS/CTS: 12.6 KB at 9600, 157.5 KB at 115200, 378 KB at 921600 | Byte-exact, all three | v3, v4 |
| TCP connection stream (PC echo server, RTS/CTS on): 3 KB at 9600, 30 KB at 57600, **200 KB at 115200** (~10.5 KB/s), 100 KB at 921600; also 3.6 KB with flow control off | Byte-exact, all | v4 (v3: **fail** - stalls, see below) |
| `+++` escape and `ATH` from a connection | Pass | v4 |
| Keystroke round-trip via TCP echo | median 45.7 / 61.3 ms; worst ~430-460 ms (WiFi power-save) | v3, v4 |

### Modem-control signal map, as verified

PC RTS -> ESP32 GPIO17 (input) and ESP32 GPIO18 (output) -> PC CTS; PC DTR ->
GPIO4 (input); GPIO5 -> DCD, GPIO6 -> RI, GPIO7 -> DSR. The firmware reports
these levels itself (`AT&O88`, prints `DCRSTOI` bits on the debug UART) and the
PC-side line states were compared against it.

## 3. Defects found during qualification (all firmware; no board change needed)

Full detail and code references are in [`../firmware/CHANGES.md`](../firmware/CHANGES.md).

| # | Defect | Effect | Fixed in |
|---|---|---|---|
| 1 | RTS/CTS pin roles were backwards for this PCB's DCE wiring | Hardware flow control (`AT&K3`) could not work | v2 |
| 2 | A saved (`AT&W`) config from older firmware restored the wrong RTS/CTS pins and survives reflashing | Stale config silently re-broke flow control | v2 |
| 3 | DTR input (GPIO4) never configured on this board | PC DTR invisible to the firmware; `ATS63=2` hang-up-on-DTR impossible | v3 |
| 4 | RTS pin left deasserted after switching flow control off | PC's CTS line stuck low after `AT&K3` -> `AT&K0` | v3 |
| 5 | Serial-to-TCP data sent one byte per TCP segment | Bursts (3.6 KB at 115200) delivered ~500 B, then one byte per 10 s; only < ~300 B/s was clean. Inherited from upstream Zimodem, not a hardware issue | v4 |

Found later (details in section 5 and the errata):

| # | Defect | Effect | Fixed in |
|---|---|---|---|
| 6 | VFD init sent once and fragile across ESP32 resets | Display scrambled or blank after about half of warm resets ([E8](ERRATA.md#e8-vfd-could-come-up-scrambled-after-a-reset-fixed-in-firmware-v5)) | v5 |
| 7 | AA / HS / OH LEDs driven active-low, but wired to light when high | Those three LEDs inverted | v5 (firmware) |
| 8 | MR / TR / SD / RD / CD read inverted through U4 (non-inverting buffer, active-low signals) | Five LEDs inverted | **fixed** - U4 hand-swapped to an inverting CD74HCT640M, verified 2026-09-29 ([E11](ERRATA.md#e11-most-front-panel-leds-read-inverted)) |
| 9 | Modem UART receive buffer never applied (set after `begin()`), so 256 bytes | Flow-off two-way traffic lost data from about 8 KB ([E12](ERRATA.md#e12-serial-receive-buffer-was-256-bytes-not-4096-fixed-in-firmware-v6b)) | v6b |

Defect 1 also exposed a **gap in the earlier design verification** (the "18/18
GPIO cross-check" compared GPIO numbers and net names, not signal direction) -
see [ERRATA E3](ERRATA.md#e3-earlier-pin-cross-check-missed-signal-direction).

## What was not tested

Be aware of these before treating the board as a finished product:

- **No instrument measurements.** RS-232 output levels at the DE-9, the 5 V and
  3.3 V rail voltages, ripple, and the regulators' temperature under load were
  **not measured or recorded**. Everything was judged through the PC's UART
  status lines and the firmware's own pin readings. Measure the rails when you
  first power a new board.
- **Supply input range** at J3 (only that a working supply was used).
- **MBAUD low (J8 2-3, 250 kbps mode)** and other jumper combinations. The
  board was qualified only in the J4 2-3 / J5 1-2 / J8 1-2 configuration.
- **Long-duration soak.** The longest single transfer was 200 KB (about 19 s)
  and the longest bulk run about 83 s. No multi-hour or thermal soak.
- **ESD/EMC, environmental, and mains/power-fault behaviour.**
- **More than one unit**, more than one host PC/USB-serial adapter, and real
  terminal programs (the tests drive the port from Python). Real-world use
  with a retro computer was not part of this report.
- **Firmware features other than those listed**: SSH/FTP/IRC/printing, XON/XOFF
  flow control, PPP/SLIP, the factory-reset button behaviour.
- **The enclosure and panel jigs** (see `enclosure/`, which keeps its own
  disclaimer).

## 4. Reproducing the tests

The scripts, their bench-specific settings, and what each one covers are in
[`../firmware/tests/README.md`](../firmware/tests/README.md). They need Python 3
and pyserial, a serial adapter on J12 (modem port), and for the signal-log
and TCP tests a debug-UART adapter on J7 and a PC on the modem's LAN.

## 5. Re-qualification on firmware v6b-rev1

`firmware-v6b-rev1` (the firmware in [`../firmware/`](../firmware/)) adds to v4: the VFD init fix, the
AA/HS/OH LED polarity, and the receive-buffer fix (E8, E11, E12). It was flashed to the same unit and the
whole suite re-run; the modem cable was on the USB adapter (COM15) unless noted, at 115200 baud unless noted.

| Test | Result |
|---|---|
| RTS/CTS suite | **14/14** |
| Baud sweep 300 to 921600 (USB adapter) | **50/50** |
| PC-side CTS across `AT&K3`/`AT&K0` | **13/13** |
| Hang up on DTR drop | **18/18** |
| Incoming call and RI | **20/20** |
| DTR/RTS signal log | tracks correctly |
| Flow-controlled streams: 3 KB at 9600, 30 KB at 57600, 200 KB at 115200, 100 KB at 230400 / 460800 / 921600 | byte-exact; 115200 at ~11 KB/s (17.6 to 19.4 s for 200 KB), 230400-921600 at ~17.3 to 17.8 KB/s |
| Bulk command-mode integrity 9600 / 115200 / 921600 | byte-exact |
| VFD across warm resets (a temporary build restarting the ESP32 every ~9 s) | **0 scrambled in about 40 resets** (v4-style init: roughly half) |
| Flow **off**, two-way (echo) streams 3.6 KB to 40 KB | **clean in all 20 runs** (v5-rev1: lost data from 8 KB; 30 and 40 KB clean 0 of 6) |
| Flow **off**, sustained ~60 KB two-way | one of two runs clean; the other lost 2,709 bytes - a real limit, **use RTS/CTS for long transfers** |
| Flow off, one-way (PC sends, network receives) 20 KB and 100 KB | lossless |
| Front-panel LEDs | idle panel as predicted after the firmware fix: OH off, AA off, HS on; a dynamic pass (TR dark with DTR asserted, OH on during a connection, HS off at 9600 baud, AA on with a listener) looked right but was many changes at once and is not a rigorous check |

### Native serial port versus the USB adapter
The same firmware was also tested with the modem on the PC's motherboard serial port (a standard 16550 UART,
`COM1`) and on the USB adapter (an FTDI FT232R). Every functional test was identical, and throughput and
keystroke latency (median about 51 to 61 ms, WiFi dominated) were the same within run-to-run variation.
The only difference is that the native port accepts nothing above 115200 baud, so 230400 to 921600 could be
tested only through the adapter.

### Still not verified
- The v6b test run on the native port was cut short when the cable was moved; the same tests were run in full
  on the USB adapter.
- All items in "What was not tested" above still apply (no voltage or signal-level measurements, single unit,
  no long soak, no ESD/EMC).

## 6. Re-qualification on firmware v7-rev1

`firmware-v7-rev1` adds one fix to v6b-rev1: SSH sessions now send the configured `AT&S41` term type
to the host instead of always sending the literal string `"vanilla"` (see `CHANGES.md`). Confirmed
with a local test SSH server logging the pty-req TERM value it received: before the fix, always
`vanilla`; after, matches `AT&S41` (tested with `vt100`). Telnet's own TERMTYPE negotiation was
already correct and unaffected.

The full `firmware/tests/` suite was re-run on the same unit; every check passed.

| Test | Result |
|---|---|
| RTS/CTS suite, baud sweep, PC-side CTS across `AT&K3`/`AT&K0`, hang up on DTR, incoming call/RI, flow-controlled streams, bulk command-mode integrity | Same results as [section 5](#5-re-qualification-on-firmware-v6b-rev1) |
| SSH pty-req TERM value matches `AT&S41` | Pass (new test this round) |

### Still not verified (v7-rev1, in addition to section 5's list)
- All items in section 5's "Still not verified" list still apply.

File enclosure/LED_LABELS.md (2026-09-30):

# Front panel LED labels - CNC engraving plan (draft)

> **Note on what the labels mean electrically (added after bring-up):** every LED lights when its drive
> signal is HIGH, and five of them (MR, TR, SD, RD, CD) go through a buffer (U4) from active-low signals.
> On boards with the originally-fitted non-inverting 74HCT245 these five read inverted (for example CD lit
> when there is *no* carrier); with U4 hand-swapped to the inverting TI CD74HCT640M (verified 2026-09-29,
> see [`../docs/ERRATA.md`](../docs/ERRATA.md#e11-most-front-panel-leds-read-inverted)), they read
> correctly. The labels below name the *function*, which is unaffected either way. The left-to-right
> order was confirmed on the built unit.

**Preliminary - not yet cut.** Positions are derived directly from the
front panel drill guide's own geometry (`build_jig1_vfd_drill.py`), not
re-estimated separately. Text height/V-bit choice are sizing/tooling
recommendations, not yet verified by a physical test cut.

## The 8 labels

The 3mm THT LEDs sit at a fixed 15.625mm pitch (125mm VFD width / 8),
evenly spaced under the VFD window. Only 3 of the 8 LEDs had a documented
function before this (`LED-AA`, `LED-HS`, `LED-OH` net labels in the
schematic) - the other 5 route through U4 (a bus buffer/transceiver) from real
RS-232/TTL signals with no descriptive net name of their own. Traced via
`pcbnew` (each LED's anode -> series resistor -> either a named net or a
U4 output pin -> matched to U4's real input pin on the same physical
channel) rather than assumed from the generic historical Hayes-modem LED
set - it happens to match that set exactly, which is a good independent
confirmation the trace is right, not the reason it was chosen.

| Position (L->R) | Label | Real signal | Driven via |
|---|---|---|---|
| 1 | **MR** | DSR (Modem Ready) | U4 (CD74HCT640M) |
| 2 | **TR** | DTR (Terminal Ready) | U4 (CD74HCT640M) |
| 3 | **SD** | TXD (Send Data) | U4 (CD74HCT640M) |
| 4 | **RD** | RXD (Receive Data) | U4 (CD74HCT640M) |
| 5 | **OH** | Off-Hook | direct GPIO (GPIO12) |
| 6 | **CD** | DCD (Carrier Detect) | U4 (CD74HCT640M) |
| 7 | **AA** | Auto-Answer | direct GPIO (GPIO10) |
| 8 | **HS** | High-Speed | direct GPIO (GPIO11) |

## Text sizing

LED pitch is 15.625mm center-to-center. Reserving a 3mm gutter between
adjacent labels leaves ~12.6mm usable width per 2-character label.
For a monospace single-stroke engraving font, 2-character width is
roughly 1.5x the text height (0.6-0.7x height per character + inter-
character gap) - so ~8.4mm is the geometric ceiling at full width.

**Recommended: 5-6mm text height** - well inside that ceiling, leaves
real margin between labels, reads as a properly proportioned indicator
label rather than one straining to fill its slot. Verify the actual
character width for your specific .cxf font in F-Engrave's own live
preview before cutting - exact metrics vary by font file.

## Per-label placement (F-Engrave)

Coordinates below use the same design convention as the drill-guide jig
scripts: **X=0 at the panel's left edge, Y=0 at the panel's TOP edge,
increasing downward.** Most CNC controllers zero at the bottom-left with
Y increasing upward instead - flip with `Y_machine = 66 - Y_design` if
that's your setup, or you'll get the label row mirrored top-to-bottom.

In F-Engrave, set the **Justify/origin anchor** to a **center column**
(Top-Center, Middle-Center, or Bottom-Center) before entering X - by
default the anchor is left-aligned, so the X value means "left edge of
text" instead of "center," which is the main way this goes wrong.

| Label | X-Origin (mm) | Y-Origin, design conv. (mm) | Y-Origin, machine conv. (mm) |
|---|---|---|---|
| MR | 40.8125 | 56.75 | 9.25 |
| TR | 56.4375 | 56.75 | 9.25 |
| SD | 72.0625 | 56.75 | 9.25 |
| RD | 87.6875 | 56.75 | 9.25 |
| OH | 103.3125 | 56.75 | 9.25 |
| CD | 118.9375 | 56.75 | 9.25 |
| AA | 134.5625 | 56.75 | 9.25 |
| HS | 150.1875 | 56.75 | 9.25 |

(Y-Origin above assumes a center-anchor and 6mm text height, labels sitting
below the LED row with a 1mm gap off the hole edge - recompute if you pick
a different text height or anchor point.)

F-Engrave generates one G-code file per text block - run this once per
label (8 times total), then queue/concatenate the resulting files. Use
the same CNC work-zero (registered to the same panel reference the
drill/router jigs use) for all 8 so these coordinates line up physically.

See `renders/led_label_layout.png` for a visual placement check of all
8 labels under their LEDs before cutting.

## V-bit

Panel is anodized aluminum, not wood/acrylic - filter for bits explicitly
rated for metal. **Recommended: 20-30 degree carbide V-bit, 0.1-0.2mm tip,
shank to match your CNC's collet (1/8"/3.175mm or 1/4"):**

- EnPoint 20 deg, 0.2mm tip, 1/8" shank - aluminum-rated, pack of 5. One
  real reported data point: successfully engraved anodized aluminum at
  16,000 RPM / 25 in/min / 0.003" depth of cut per pass.
- EnPoint 30 deg, 0.1mm tip, 1/8" shank - finer tip, more fragile in metal;
  use the 20 deg/0.2mm option if this is a first aluminum-engraving run.
- SpeTool 20 deg, ~0.13mm tip, 1/4" shank, TAC-coated - more durable for
  repeated small-batch jobs if your collet takes 1/4" shanks.

A narrower angle (20-30 deg vs the common 60-90 deg signmaking bits) is
the right call at this text height - it reaches the fine stroke widths
2-letter labels at 5-6mm need without requiring near-impossible depth
precision. Enter the *exact* angle and tip diameter of whichever bit you
actually buy into F-Engrave's tool settings - it uses those two numbers
directly to compute plunge depth for the target line width.

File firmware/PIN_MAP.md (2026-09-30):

# ESP32-S3-16R8 Pin Map (DevKitC-1 v1.1 / EngModem Mini)

Target board: originally ESP32-S3-DevKitC-1 v1.1 (ESP32-S3-WROOM-1-N16R8 module,
16MB flash, 8MB octal PSRAM) for breadboard prototyping. Verified against
Espressif's official J1/J3 header tables and GPIO reference docs. This firmware
fork (`ENGMODEM_MINI_BOARD` in `zimodem.ino`) targets the EngModem Mini custom
PCB, which deliberately reuses this exact GPIO layout - so the table below still
applies pin-for-pin - but is a different physical board: no onboard RGB LED (see
GPIO38 below), and it adds 3 direct-drive status LEDs the dev board never had
(see GPIO10/11/12 below).

**A note on the `J1-N`/`J3-N` notation below:** that's the row-position number from
Espressif's own header table (1-22 per header, matching their schematic) - it is
**not** what's printed on the physical board. The silkscreen next to each pin shows
the bare GPIO number only. So `J1-12` in this doc means "GPIO8, the 12th row down on
the left header" - when wiring, go by the GPIO number, not the position count.
Orientation: with both USB connectors facing you at the bottom and the WROOM module
at the top, **J1 is the left-side header, J3 is the right-side header**.

## Hard constraints (confirmed from Espressif documentation)

| Pins | Reason | Treatment |
|---|---|---|
| GPIO0, 3, 45, 46 | Strapping pins (boot mode, JTAG source, VDD_SPI voltage) | Never used |
| GPIO26-37 | Flash + octal PSRAM (26-32 shared flash/PSRAM, 33-37 octal-PSRAM-specific data/DQS lines) | Never used, even where physically broken out on the header |
| GPIO43, 44 | Fixed UART0 (TX/RX) - used by the onboard USB-serial bridge for flashing/monitor on the dev board. **On the EngModem Mini** they are the firmware's debug UART, brought out on header J7 (pin 3 = TXD, pin 4 = RXD, pins 5/6 = GND), 115200 8N1 | Reserved, not used for peripherals |
| GPIO19, 20 | USB D-/D+ | Reserved, not used for peripherals |
| GPIO47, 48 | SUBSPI differential clock pair (SPICLK_P/SPICLK_N) used to reach the in-package flash/octal PSRAM at its 1.8V domain on N16R8 modules. Espressif docs say "strongly not recommended to reconfigure." | Never used |
| GPIO38 | On the DevKitC-1 dev board: onboard addressable RGB LED (Espressif J3 header docs), cleared to off at boot. **On EngModem Mini: no RGB LED exists here** - `ENGMODEM_MINI_BOARD` skips that boot-time write (see `CHANGES.md`), and this pin is instead broken out as a general-purpose expansion header pin. | Dev board: never used for peripherals. Mini board: available (wired to the expansion header) |

## Pin assignments

| J-header position | GPIO | Signal | Notes |
|---|---|---|---|
| J1-4 | GPIO4 | DTR | |
| J1-5 | GPIO5 | DCD | |
| J1-6 | GPIO6 | RI | |
| J1-7 | GPIO7 | DSR | |
| J1-8 | GPIO15 | RXD | |
| J1-9 | GPIO16 | TXD | |
| J1-10 | GPIO17 | **CTS (firmware input)** | On the EngModem Mini this net (`/TTL-RTS`) is the MAX3237 ROUT2 output carrying the *PC's* RTS. Firmware v2 uses it as the UART CTS input. |
| J1-11 | GPIO18 | **RTS (firmware output)** | On the EngModem Mini this net (`/TTL-CTS`) drives MAX3237 DIN3, out to the *PC's* CTS. Firmware v2 uses it as the UART RTS output. |
| J1-12 | GPIO8 | VFD DB6 | |
| *(J1-13/14 = GPIO3, 46 - strapping pins, skipped)* | | | |
| J1-15 | GPIO9 | VFD DB7 | |
| J1-16 | GPIO10 | LED AA (auto-answer) | direct-drive, EngModem Mini only; spare on the bare dev board |
| J1-17 | GPIO11 | LED HS (high-speed) | direct-drive, EngModem Mini only; spare on the bare dev board |
| J1-18 | GPIO12 | LED OH (off-hook) | direct-drive, EngModem Mini only - lit while any connection (telnet/SSH/FTP/IRC/print) is open, driven from `checkOpenConnections()`, protocol-agnostic - see `CHANGES.md` |
| J1-19 | GPIO13 | SD CS | |
| J1-20 | GPIO14 | SD MOSI | |
| J3-4 | GPIO1 | SD MISO | spillover onto J3 |
| J3-5 | GPIO2 | SD SCK | spillover onto J3 |
| J3-6 | GPIO42 | VFD RS | direct parallel drive |
| J3-7 | GPIO41 | VFD E | |
| J3-8 | GPIO40 | VFD DB4 | |
| J3-9 | GPIO39 | VFD DB5 | |
| J3-18 | GPIO21 | *(spare)* | last spare GPIO on the board |

## Front-panel LEDs (order and polarity)

Left to right: **MR, TR, SD, RD, OH, CD, AA, HS** (PCB designators D8 to D1; confirmed by a blink test on the
built unit). Every LED is wired anode -> resistor -> drive signal, cathode -> GND, so it **lights when its
drive signal is HIGH**.

| LED | Signal | How driven | Note |
|---|---|---|---|
| MR | `/TTL-DSR` (GPIO7, output) | via U4 (CD74HCT640M, inverting) | DSR is asserted LOW; U4 inverts, so MR is lit when ready |
| TR | `/TTL-DTR` (GPIO4, **input** from the MAX3237) | via U4 | never drive this pin |
| SD | `/TTL-TXD` (GPIO16) | via U4 | UART idles HIGH; U4 inverts, so SD is dark at idle |
| RD | `/TTL-RXD` (GPIO15, **input** from the MAX3237) | via U4 | never drive this pin |
| OH | GPIO12 | direct | firmware drives it active-HIGH (v5+) |
| CD | `/TTL-DCD` (GPIO5) | via U4 | DCD is asserted LOW; U4 inverts, so CD is dark when there is no carrier |
| AA | GPIO10 | direct | firmware drives it active-HIGH (v5+) |
| HS | GPIO11 | direct | firmware drives it active-HIGH (v5+) |

The five LEDs through U4 now read correctly (U4 was hand-swapped from the originally-fitted
non-inverting 74HCT245 to a pin-compatible inverting CD74HCT640M, verified on hardware 2026-09-29).
See [`../docs/ERRATA.md`](../docs/ERRATA.md#e11-most-front-panel-leds-read-inverted).

## Power regulation - not GPIO-mapped

The board's 5V and 3.3V rails come from two D2PAK/TO-263-3 linear
regulators (U3, U5) - neither is wired to any ESP32-S3 GPIO, so they
don't appear in the pin table above. Worth flagging here anyway since a
builder sourcing parts from this doc should know: the originally spec'd
parts for both don't reliably match the board's 3-lead footprint (a real
footprint mismatch, confirmed against the manufacturers' own datasheets,
not just a JLCPCB-preview quirk). Verified replacements: onsemi
**MC7805CD2TR4G** (U3, 5V) and TI **LM1086CSX-3.3/NOPB** (U5, 3.3V) - see
`CHANGES.md` and the hardware repo's `manufacturing/BOM_full.csv` for the
full pin/tab verification.

## VFD - direct parallel drive, no I2C bridge

The ESP32-S3 drives the VFD's 4-bit parallel bus directly (RS, E, DB4-7). R/W is
hardwired to GND on the VFD board itself, so it's not an MCU pin. This avoids needing
a separate bridge microcontroller, its own firmware/power/wiring, and a failure point.

## SD card - non-default SPI pins, requires an explicit SPIClass

The SD card's MOSI/MISO/SCK are **not** on the ESP32-S3 Arduino core's default SPI
bus pins, so `SD.begin(cs)` alone is not sufficient - it needs an explicitly
configured `SPIClass` instance:

```cpp
SPIClass sdSPI(FSPI);
sdSPI.begin(SD_SCK, SD_MISO, SD_MOSI, SD_CS);
SD.begin(SD_CS, sdSPI);
```

This is already handled in `zbrowser.ino`'s `initSDShell()`.

## Why SD and VFD both spill onto J3

Modem control (8 signals) + SD (4: CS/MOSI/MISO/SCK) + VFD (6: RS/E/DB4-7) = 18
signals. The two clean contiguous safe runs on J1 (positions 4-12 and 15-20) hold 15.
SD's MISO and SCK land on J3's first two safe pins (GPIO1/2), physically the very top
of that header, right next to TX/RX. VFD's RS/E/DB4/DB5 land on J3's next free run
(positions 6-9, four consecutive pins).

VFD's other two lines, DB6/DB7, do **not** follow onto J3 - the two pins that would
have continued that run (GPIO47/48) are the module's reserved SUBSPI clock pair (see
Hard constraints above). They land instead on J1-12/J1-15 (GPIO8/9). This splits the
VFD's six signal lines across two headers (RS/E/DB4/DB5 on J3, DB6/DB7 on J1).

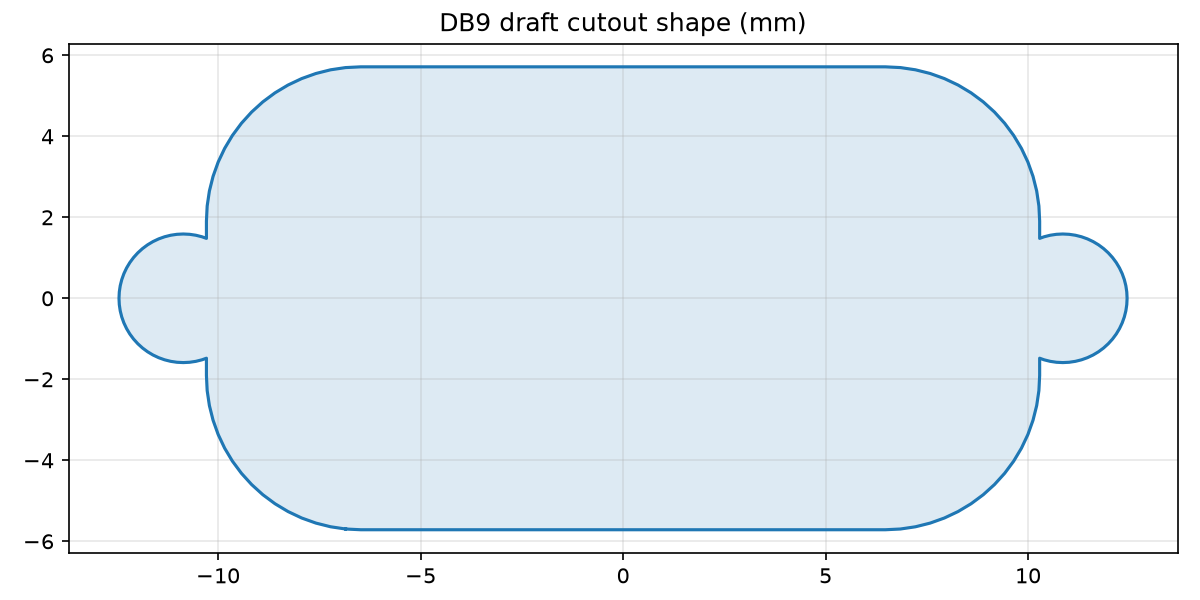
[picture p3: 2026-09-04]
enclosure/renders/db9_shape.png

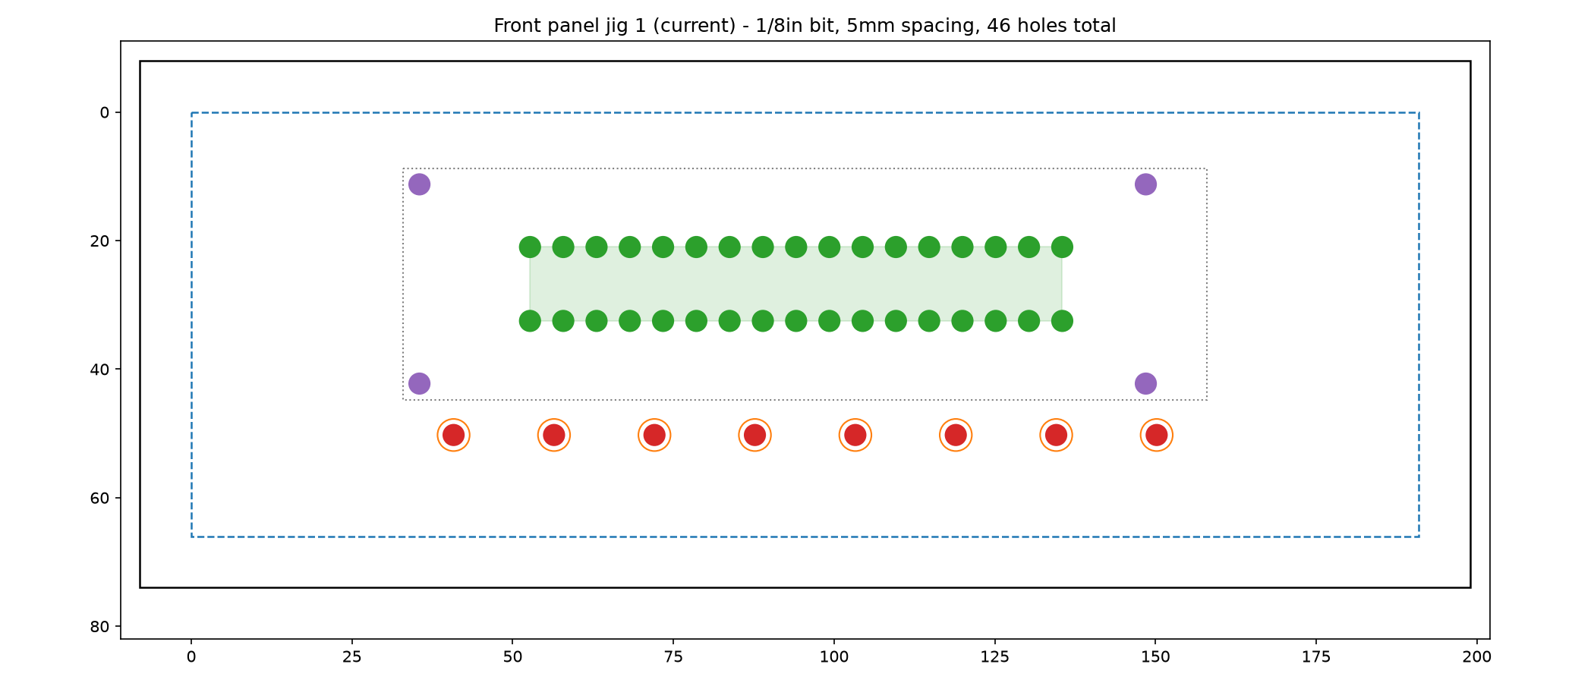
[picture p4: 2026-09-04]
enclosure/renders/vfd_jig1_layout.png

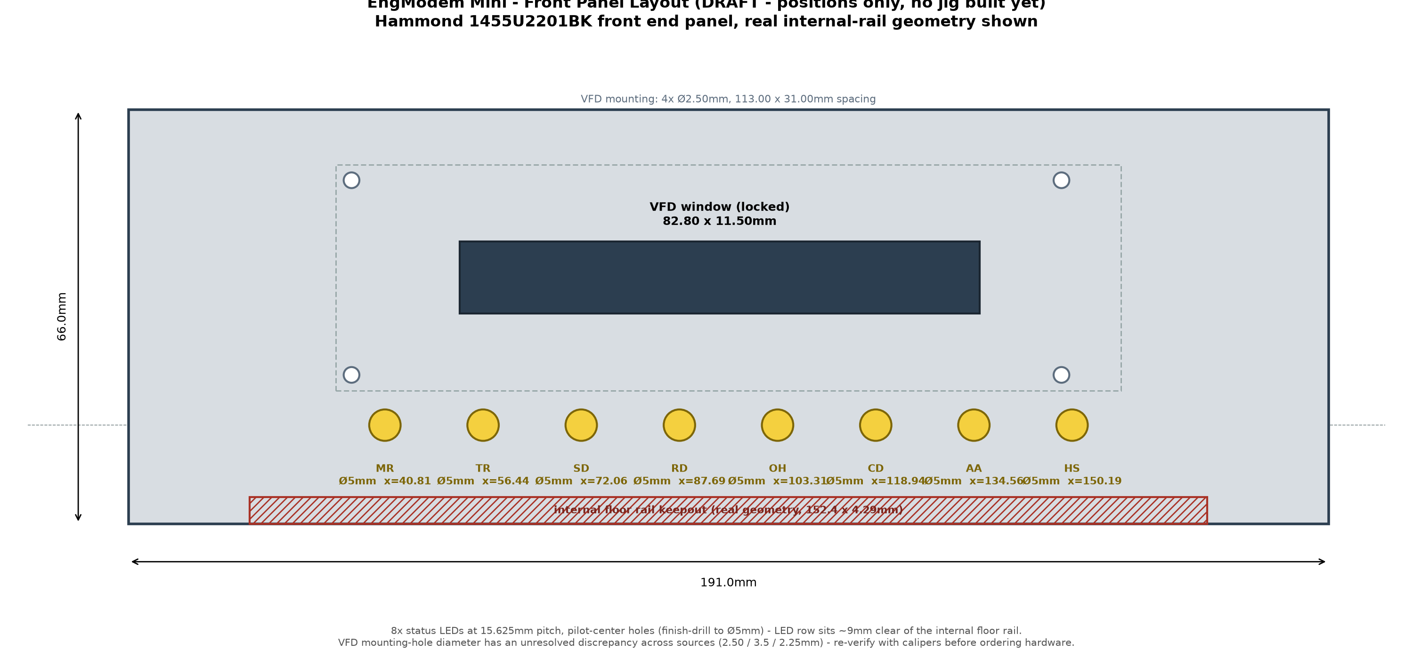
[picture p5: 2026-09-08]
enclosure/renders/front_panel_layout.png

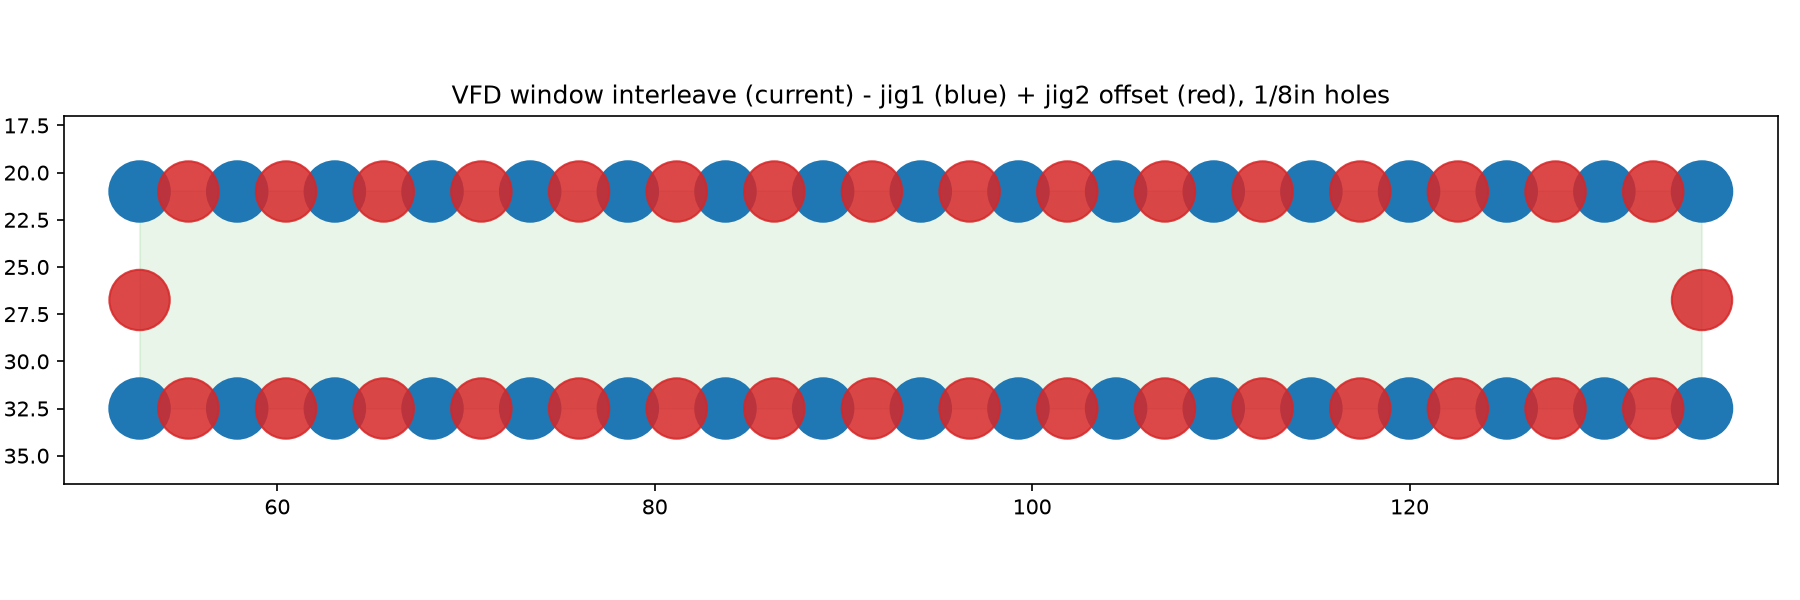
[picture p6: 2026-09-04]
enclosure/renders/vfd_interleave.png

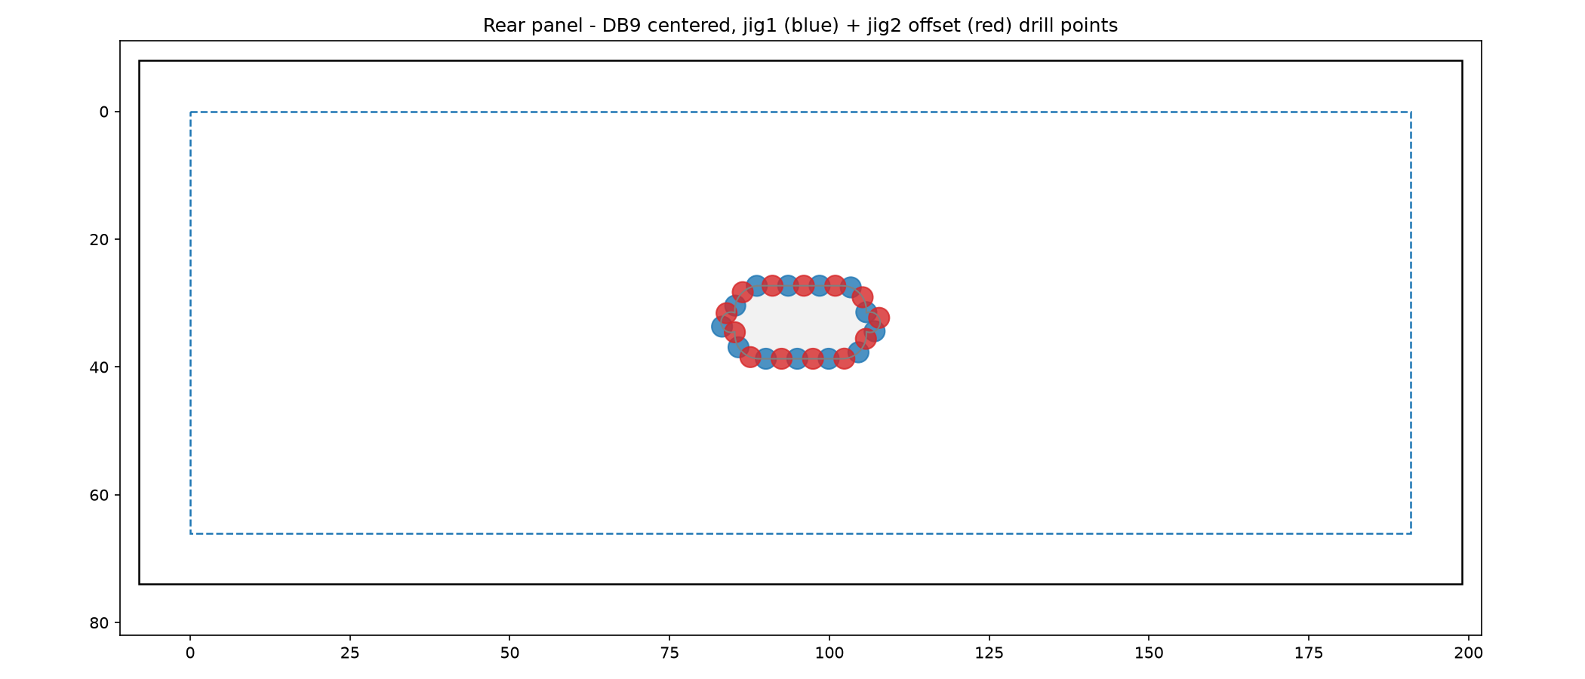
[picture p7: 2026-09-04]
enclosure/renders/db9_layout.png

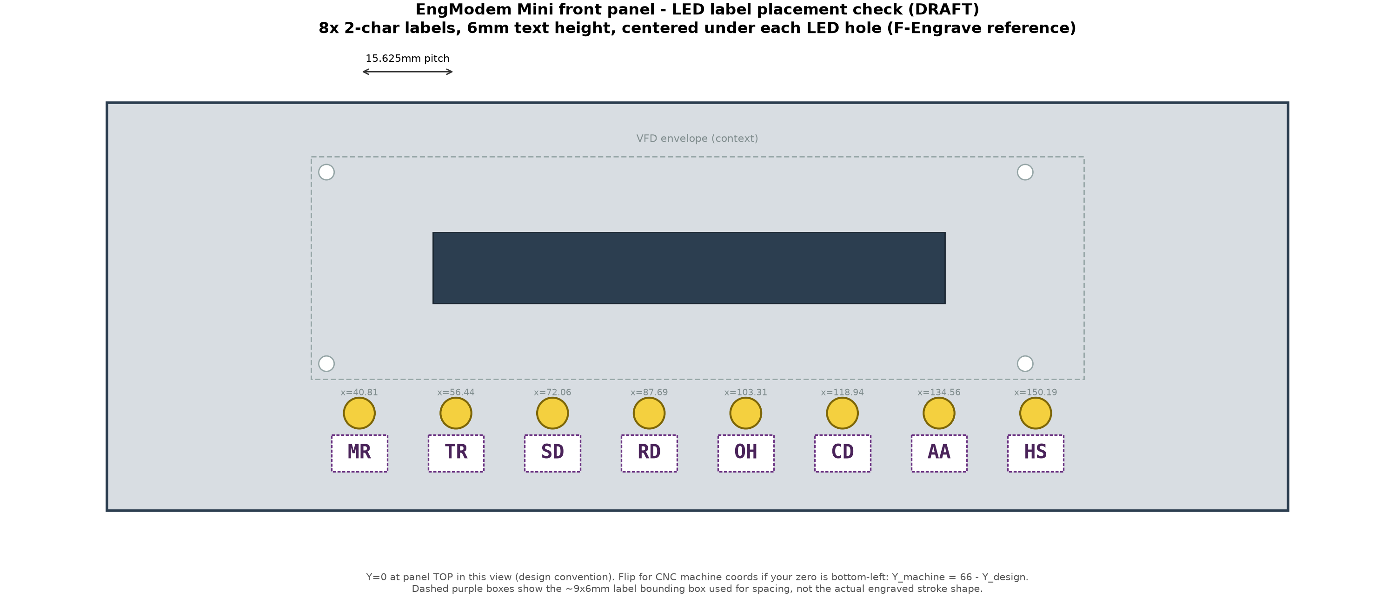
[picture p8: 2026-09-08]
enclosure/renders/led_label_layout.png

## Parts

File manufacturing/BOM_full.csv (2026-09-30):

Designator | Value | Footprint | Assembly | Notes
C1 | 0.22uF | C_0805_2012Metric | PCBA (SMD) | See BOM_PCBA_JLCPCB.csv
C2 | 0.22uF | C_0805_2012Metric | PCBA (SMD) | See BOM_PCBA_JLCPCB.csv
C3 | 0.22uF | C_0805_2012Metric | PCBA (SMD) | See BOM_PCBA_JLCPCB.csv
C4 | 0.22uF | C_0805_2012Metric | PCBA (SMD) | See BOM_PCBA_JLCPCB.csv
C5 | 0.1uF | C_0805_2012Metric | PCBA (SMD) | See BOM_PCBA_JLCPCB.csv
C6 | 0.33uF | C_0805_2012Metric | PCBA (SMD) | See BOM_PCBA_JLCPCB.csv
C7 | 0.1uF | C_0805_2012Metric | PCBA (SMD) | See BOM_PCBA_JLCPCB.csv
C8 | 10uF | C_1206_3216Metric | PCBA (SMD) | See BOM_PCBA_JLCPCB.csv
C9 | 10uF | C_0805_2012Metric | PCBA (SMD) | See BOM_PCBA_JLCPCB.csv
C10 | 1uF | C_0805_2012Metric | PCBA (SMD) | See BOM_PCBA_JLCPCB.csv
C12 | 1uF | C_0805_2012Metric | PCBA (SMD) | See BOM_PCBA_JLCPCB.csv
C11 | 10uF | C_0805_2012Metric | PCBA (SMD) | See BOM_PCBA_JLCPCB.csv
D1 | LED | PinHeader_1x02_P2.54mm_Vertical | Hand-solder (THT) | 3mm THT LED with a 5mm panel-mount snap-in clip/bezel (front-panel mounted, wired back to this 2-pin header - see the front-panel drill guide jigs, Enclosure_Prototype/front_panel_drill_guide.stl, for the 5mm hole positions). Series resistors already sized for AA/HS/OH (R6-R8, 330R) and the other 5 (R1-R5, 750R) - factor your chosen LED color/forward voltage in if you deviate from a typical red/green/yellow LED.
D2 | LED | PinHeader_1x02_P2.54mm_Vertical | Hand-solder (THT) | 3mm THT LED with a 5mm panel-mount snap-in clip/bezel (front-panel mounted, wired back to this 2-pin header - see the front-panel drill guide jigs, Enclosure_Prototype/front_panel_drill_guide.stl, for the 5mm hole positions). Series resistors already sized for AA/HS/OH (R6-R8, 330R) and the other 5 (R1-R5, 750R) - factor your chosen LED color/forward voltage in if you deviate from a typical red/green/yellow LED.
D3 | LED | PinHeader_1x02_P2.54mm_Vertical | Hand-solder (THT) | 3mm THT LED with a 5mm panel-mount snap-in clip/bezel (front-panel mounted, wired back to this 2-pin header - see the front-panel drill guide jigs, Enclosure_Prototype/front_panel_drill_guide.stl, for the 5mm hole positions). Series resistors already sized for AA/HS/OH (R6-R8, 330R) and the other 5 (R1-R5, 750R) - factor your chosen LED color/forward voltage in if you deviate from a typical red/green/yellow LED.
D4 | LED | PinHeader_1x02_P2.54mm_Vertical | Hand-solder (THT) | 3mm THT LED with a 5mm panel-mount snap-in clip/bezel (front-panel mounted, wired back to this 2-pin header - see the front-panel drill guide jigs, Enclosure_Prototype/front_panel_drill_guide.stl, for the 5mm hole positions). Series resistors already sized for AA/HS/OH (R6-R8, 330R) and the other 5 (R1-R5, 750R) - factor your chosen LED color/forward voltage in if you deviate from a typical red/green/yellow LED.
D5 | LED | PinHeader_1x02_P2.54mm_Vertical | Hand-solder (THT) | 3mm THT LED with a 5mm panel-mount snap-in clip/bezel (front-panel mounted, wired back to this 2-pin header - see the front-panel drill guide jigs, Enclosure_Prototype/front_panel_drill_guide.stl, for the 5mm hole positions). Series resistors already sized for AA/HS/OH (R6-R8, 330R) and the other 5 (R1-R5, 750R) - factor your chosen LED color/forward voltage in if you deviate from a typical red/green/yellow LED.
D6 | LED | PinHeader_1x02_P2.54mm_Vertical | Hand-solder (THT) | 3mm THT LED with a 5mm panel-mount snap-in clip/bezel (front-panel mounted, wired back to this 2-pin header - see the front-panel drill guide jigs, Enclosure_Prototype/front_panel_drill_guide.stl, for the 5mm hole positions). Series resistors already sized for AA/HS/OH (R6-R8, 330R) and the other 5 (R1-R5, 750R) - factor your chosen LED color/forward voltage in if you deviate from a typical red/green/yellow LED.
D7 | LED | PinHeader_1x02_P2.54mm_Vertical | Hand-solder (THT) | 3mm THT LED with a 5mm panel-mount snap-in clip/bezel (front-panel mounted, wired back to this 2-pin header - see the front-panel drill guide jigs, Enclosure_Prototype/front_panel_drill_guide.stl, for the 5mm hole positions). Series resistors already sized for AA/HS/OH (R6-R8, 330R) and the other 5 (R1-R5, 750R) - factor your chosen LED color/forward voltage in if you deviate from a typical red/green/yellow LED.
D8 | LED | PinHeader_1x02_P2.54mm_Vertical | Hand-solder (THT) | 3mm THT LED with a 5mm panel-mount snap-in clip/bezel (front-panel mounted, wired back to this 2-pin header - see the front-panel drill guide jigs, Enclosure_Prototype/front_panel_drill_guide.stl, for the 5mm hole positions). Series resistors already sized for AA/HS/OH (R6-R8, 330R) and the other 5 (R1-R5, 750R) - factor your chosen LED color/forward voltage in if you deviate from a typical red/green/yellow LED.
J1 | VFD | PinHeader_2x07_P2.54mm_Vertical | Hand-solder (THT) | 14-pin header to the Noritake CU24025ECPB-W1J VFD module
J3 | DC_PWR_HEADER | PinHeader_1x02_P2.54mm_Vertical | Hand-solder (THT) | DC input
J4 | MAX-ENCFG | PinHeader_1x03_P2.54mm_Vertical | Hand-solder (THT) | MAX3237 receiver-enable jumper
J5 | MAX-SHDN | PinHeader_1x03_P2.54mm_Vertical | Hand-solder (THT) | MAX3237 shutdown jumper
J6 | USB | PinHeader_1x06_P2.54mm_Vertical | Hand-solder (THT) | USB-C signal breakout header
J7 | EXP | PinHeader_2x04_P2.54mm_Vertical | Hand-solder (THT) | Expansion header (GPIO21/38/TXD/RXD)
J8 | MAX-MBAUD | PinHeader_1x03_P2.54mm_Vertical | Hand-solder (THT) | MAX3237 megabaud-select jumper
J9 | ESP-BOOT | PinHeader_1x02_P2.54mm_Vertical | Hand-solder (THT) | ESP32-S3 BOOT jumper
J10 | ESP-ENABLE | PinHeader_1x02_P2.54mm_Vertical | Hand-solder (THT) | ESP32-S3 EN jumper
J11 | Micro_SD_Card | microSD_HC_Hirose_DM3AT-SF-PEJM5 | PCBA (SMD) | See BOM_PCBA_JLCPCB.csv
J12 | DB9 | IDC-Header_2x05_P2.54mm_Vertical | Hand-solder (THT) | RS-232 DE-9 (DCE pinout) - 2x5 0.1in IDC-style header. Pin order is the AT/Everex flavor: header pins 1-10 = DCD, RXD, TXD, DTR, GND, DSR, RTS, CTS, RI, NC (header pin n = DE-9 pin n). It is NOT the DTK/Intel flavor that many header-to-DB9 bracket cables use (DCD, DSR, RXD, RTS, TXD, CTS, DTR, RI, GND): one of those on this header swaps RXD/TXD/GND and nothing connects. Confirmed on hardware 2026-09-19 - a DTK/Intel cable (IDC pin 3 -> DB9 pin 2) gave no serial; wiring J12 pin n straight to DB9 pin n gave the Zimodem banner. Use an AT/Everex-wired cable or 1:1 wiring. Not sourced against a specific manufacturer part.
L1 | DFE201210U-2R2M=P2 (2.2uH, 1.2A, 228mOhm) | L_0805_2012Metric | PCBA (SMD) | See BOM_PCBA_JLCPCB.csv
R1 | 750R | R_0805_2012Metric | PCBA (SMD) | See BOM_PCBA_JLCPCB.csv
R2 | 750R | R_0805_2012Metric | PCBA (SMD) | See BOM_PCBA_JLCPCB.csv
R3 | 750R | R_0805_2012Metric | PCBA (SMD) | See BOM_PCBA_JLCPCB.csv
R4 | 750R | R_0805_2012Metric | PCBA (SMD) | See BOM_PCBA_JLCPCB.csv
R5 | 750R | R_0805_2012Metric | PCBA (SMD) | See BOM_PCBA_JLCPCB.csv
R6 | 330R | R_0805_2012Metric | PCBA (SMD) | See BOM_PCBA_JLCPCB.csv
R7 | 330R | R_0805_2012Metric | PCBA (SMD) | See BOM_PCBA_JLCPCB.csv
R8 | 330R | R_0805_2012Metric | PCBA (SMD) | See BOM_PCBA_JLCPCB.csv
R9 | 10K | R_0805_2012Metric | PCBA (SMD) | See BOM_PCBA_JLCPCB.csv
R10 | 10K | R_0805_2012Metric | PCBA (SMD) | See BOM_PCBA_JLCPCB.csv
U1 | MAX3237EIPWR | MAX3237:PW28 | PCBA (SMD) | See BOM_PCBA_JLCPCB.csv
U2 | ESP32-S3-WROOM-1U | PCM_Espressif:ESP32-S3-WROOM-1U | PCBA (SMD) | See BOM_PCBA_JLCPCB.csv
U3 | MC7805CD2TR4G | TO-263-3_TabPin2 | Hand-solder (SMD, excluded from PCBA) | Originally spec'd as HGSEMI LM7805S2/TR (C2902505); excluded from PCBA after JLCPCB's placement preview showed a footprint mismatch (LCSC lists that part as TO-263-2, JLCPCB's 3D model shows TO263-5 case marking - neither is the 3-lead D2PAK this footprint expects). Replaced with onsemi MC7805CD2TR4G (D2PAK-3, CASE 936, Tape&Reel), verified against onsemi's own MC7800 datasheet: Pin1=Input, Pin2=Ground=Tab, Pin3=Output - exact match to this footprint and the schematic's pin assignment. Order from Mouser/DigiKey.
U4 | CD74HCT640M | RetroWiFiModem:SOIC-20W_7.5x12.8mm_P1.27mm | Hand-solder (SMD, excluded from PCBA) | Originally spec'd/placed via PCBA as a generic 74HCT245 (non-inverting); found post-fab that this reads five front-panel LEDs inverted (ERRATA E11). Hand-swapped on the qualified unit to TI CD74HCT640M (inverting, pin/package-compatible - same SOIC-20-300mil footprint) and verified correct on hardware (2026-09-29); a pad was pulled during desoldering and needed a trace/pad-level repair. LCSC C1548168 - 0 units in LCSC's own direct stock at last check, ~3,000 available via LCSC's Other Suppliers channel at a 9-18 business day lead time (checked 2026-09-29, re-verify before ordering); excluded from PCBA here pending confirmed assembly-line stock. Must be the HCT variant, not HC (HC does not meet the 3.3V input threshold at 5V).
U5 | LM1086IS-3.3/NOPB | TO-263-3_TabPin2 | Hand-solder (SMD, excluded from PCBA) | Originally spec'd as STMicroelectronics LD1086D2T33TR (C7915); excluded from PCBA after JLCPCB's placement preview showed a footprint mismatch (ST's own datasheet defines two different D2PAK mechanical variants - 2-lead and 3-lead - under one ambiguous order code, and LCSC/JLCPCB list this exact part as TO-263-2). Replaced with TI LM1086CSX-3.3/NOPB (DDPAK/TO-263, package KTT, Tape&Reel), verified against TI's own datasheet: Pin1=ADJ/GND, Pin2+Tab=Output, Pin3=Input - exact match to this footprint and the schematic's pin assignment (tab wired to Output). CSX variant went out of stock at Mouser (2026-09-16); substituted LM1086IS-3.3/NOPB - confirmed via TI's own Package Option Addendum to be the identical DDPAK/TO-263 (KTT), 3-pin package and pinout, differing only in temp grade (I: -40 to 125C vs C: 0 to 125C, a strict superset) and ship format (45-unit tube vs 500-unit reel). Order from Mouser/DigiKey.

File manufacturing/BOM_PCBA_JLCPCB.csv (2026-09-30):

Designator | Value | Package | Manufacturer | MPN | LCSC Part # | Notes
C1 | 0.22uF | 0805 |  |  |  | X7R ceramic, >=16V. Common value - match at JLCPCB checkout against their basic-parts catalog.
C2 | 0.22uF | 0805 |  |  |  | X7R ceramic, >=16V. Common value - match at JLCPCB checkout against their basic-parts catalog.
C3 | 0.22uF | 0805 |  |  |  | X7R ceramic, >=16V. Common value - match at JLCPCB checkout against their basic-parts catalog.
C4 | 0.22uF | 0805 |  |  |  | X7R ceramic, >=16V. Common value - match at JLCPCB checkout against their basic-parts catalog.
C5 | 0.1uF | 0805 |  |  |  | X7R ceramic, >=16V. VCC bypass. Common value - match at checkout.
C6 | 0.33uF | 0805 |  |  |  | X7R ceramic, >=16V. Common value - match at checkout.
C7 | 0.1uF | 0805 |  |  |  | X7R ceramic, >=16V. Common value - match at checkout.
C8 | 10uF | 1206 |  |  |  | X5R/X7R ceramic, >=16V. Common value - match at checkout.
C9 | 10uF | 0805 |  |  |  | X5R/X7R ceramic, >=16V. Common value - match at checkout.
C10 | 1uF | 0805 |  |  |  | X7R ceramic, >=16V. Common value - match at checkout.
C12 | 1uF | 0805 |  |  |  | X7R ceramic, >=16V. Common value - match at checkout.
C11 | 10uF | 0805 |  |  |  | X5R/X7R ceramic, >=16V. Common value - match at checkout.
L1 | 2.2uH, 1.2A, 228mOhm, shielded | 0805 | Murata | DFE201210U-2R2M=P2 | C2049745 | Verified exact MPN match, in stock (checked 2026-09-03).
R1 | 750R | 0805 |  |  |  | 1%. Common value - match at checkout.
R2 | 750R | 0805 |  |  |  | 1%. Common value - match at checkout.
R3 | 750R | 0805 |  |  |  | 1%. Common value - match at checkout.
R4 | 750R | 0805 |  |  |  | 1%. Common value - match at checkout.
R5 | 750R | 0805 |  |  |  | 1%. Common value - match at checkout.
R6 | 330R | 0805 |  |  |  | 1%. Common value - match at checkout.
R7 | 330R | 0805 |  |  |  | 1%. Common value - match at checkout.
R8 | 330R | 0805 |  |  |  | 1%. Common value - match at checkout.
R9 | 10K | 0805 |  |  |  | 1%. Common value - match at checkout.
R10 | 10K | 0805 |  |  |  | 1%. Common value - match at checkout.
U1 | MAX3237EIPWR | TSSOP-28 | Texas Instruments | MAX3237EIPWR | C2671155 | Verified exact MPN match, in stock (checked 2026-09-03).
U2 | ESP32-S3-WROOM-1U-N16R8 | SMD 18x19.2mm module | Espressif | ESP32-S3-WROOM-1U-N16R8 | C3013946 | Verified exact MPN match, in stock (checked 2026-09-03).
J11 | Micro SD card socket | SMD push-push | Hirose | DM3AT-SF-PEJM5 | C114218 | Verified exact MPN match, in stock (checked 2026-09-03). Suffix-specific reel variants also exist on LCSC (e.g. (11)/(21)/(40)/(41)) - electrically identical, differ only in packaging/reel.

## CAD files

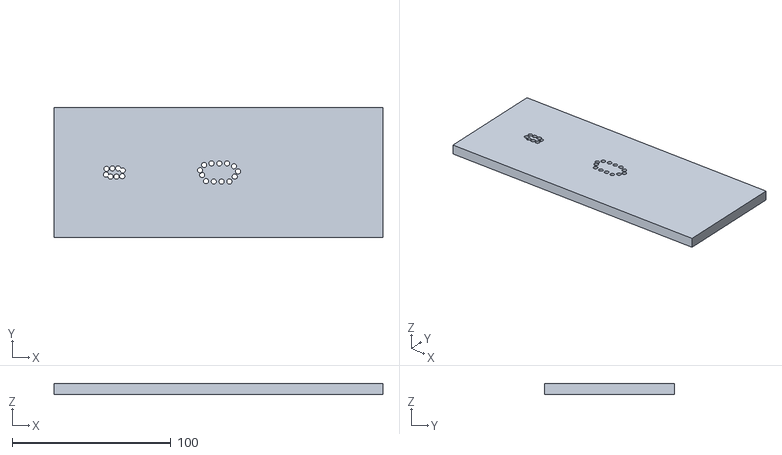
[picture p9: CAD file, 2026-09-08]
enclosure/jigs/rear_panel_drill_guide_2_offset.stl
207.0 x 82.0 x 7.00

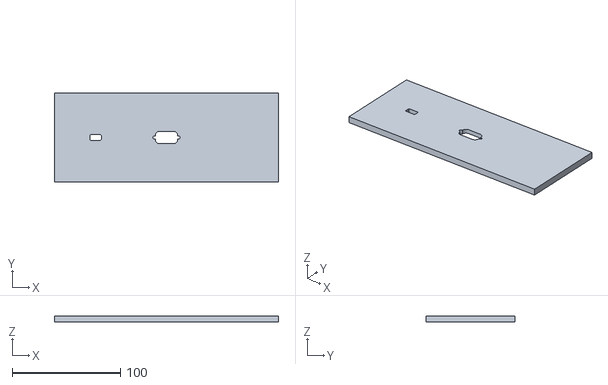
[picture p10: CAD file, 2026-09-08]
enclosure/jigs/rear_panel_router_template.stl
207.0 x 82.0 x 6.00

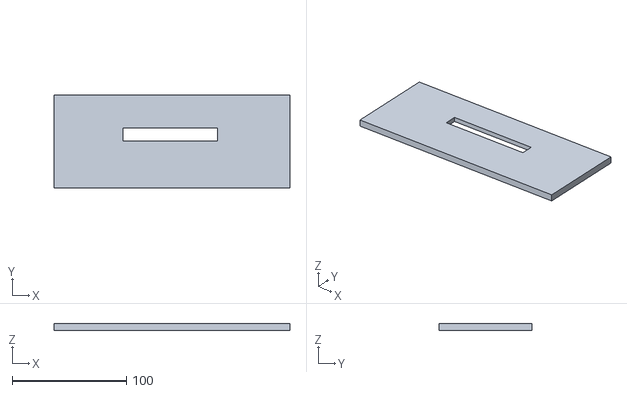
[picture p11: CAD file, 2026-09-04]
enclosure/jigs/front_panel_router_template_vfd.stl
207.0 x 82.0 x 6.00

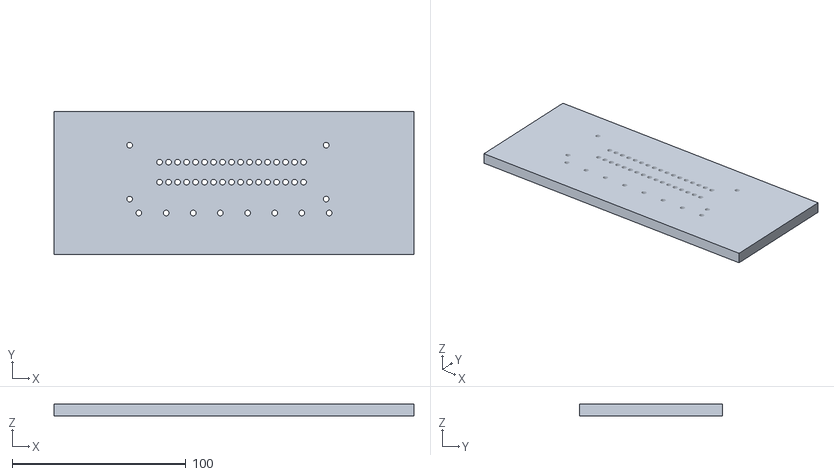
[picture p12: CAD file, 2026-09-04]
enclosure/jigs/front_panel_drill_guide.stl
207.0 x 82.0 x 7.00

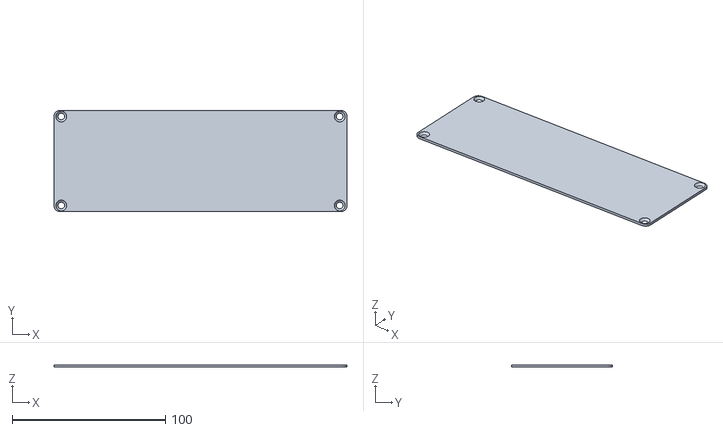
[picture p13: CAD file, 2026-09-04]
enclosure/1455U2201_REAL_end_panel.stl
191.0 x 66.0 x 1.63

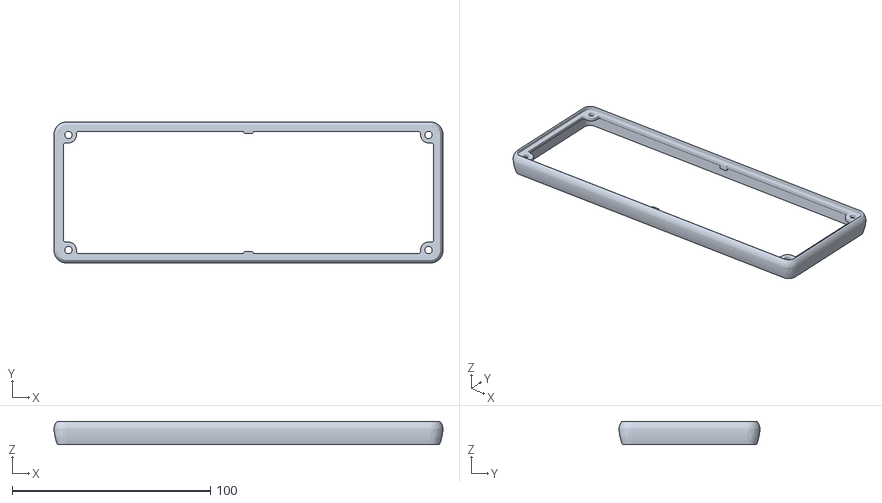
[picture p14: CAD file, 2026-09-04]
enclosure/1455U2201_REAL_bezel.stl
196.1 x 71.1 x 11.6

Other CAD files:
enclosure/jigs/rear_panel_drill_guide.stl
enclosure/jigs/front_panel_drill_guide_2_offset.stl

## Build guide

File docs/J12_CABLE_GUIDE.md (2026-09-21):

# J12 to DE-9: getting the cable right

**Short version: most ready-made "2x5 header to DE-9" cables will NOT work on
J12.** They use a different pin order. On the tested board a common
header-to-DE-9 bracket cable gave *no serial output at all* - it looked
exactly like dead firmware until the cable was ruled out.

J12 is a 2x5, 0.1" (2.54 mm) header. The board is wired as a **DCE** (a
modem), so a straight-through cable to a PC's COM port is correct - no
null-modem.

## The two header pin orders in the wild

Serial-port bracket cables for PC motherboards come in two flavours. J12 uses
the first.

| Header pin | **AT / Everex order - J12 (this board)** | DTK / Intel order (very common cable) |
|---|---|---|
| 1 | DCD | DCD |
| 2 | RXD | DSR |
| 3 | TXD | RXD |
| 4 | DTR | RTS |
| 5 | GND | TXD |
| 6 | DSR | CTS |
| 7 | RTS | DTR |
| 8 | CTS | RI |
| 9 | RI | GND |
| 10 | NC | NC |

On J12 the header pin number equals the DE-9 pin number for pins 1-9. That is
why the design *looks* standard - but a DTK/Intel cable plugged onto it swaps
RXD, TXD and GND and nothing connects.

The J12 silkscreen labels were checked pad-by-pad against the PCB and are
correct. This is a property of the design (a mismatch with the cable you own),
not a board defect. A future revision could adopt whichever order the cables in
common use have; it is listed in [`ERRATA.md`](ERRATA.md#e1-j12-pin-order-differs-from-common-bracket-cables).

## Which cable do I have?

With the cable unplugged, use a multimeter in continuity mode between the
**header socket** pin positions and the **DE-9 plug** pins:

| Header position 3 reaches DE-9 pin... | Cable type | Works on J12? |
|---|---|---|
| **3** | AT / Everex | Yes |
| **2** | DTK / Intel | **No** |

(Find header position 1 by continuity or by the marked/square end of the
connector; pins 1,3,5,7,9 are one row and 2,4,6,8,10 the other.)

## Option A (tested): wire J12 1:1 to a DE-9 yourself

Connect each J12 pin to the same-numbered DE-9 pin using a female DE-9
(so a normal straight cable runs to the PC). This is what was used to qualify
the board - first with a DE-9 breakout board fed from Dupont leads, then with
the wiring confirmed by continuity checks.

| J12 pin | Signal | DE-9 pin | Direction (modem is DCE) |
|---|---|---|---|
| 1 | DCD | 1 | modem out |
| 2 | RXD | 2 | modem out (PC receives) |
| 3 | TXD | 3 | modem in (PC transmits) |
| 4 | DTR | 4 | modem in |
| 5 | GND | 5 | - |
| 6 | DSR | 6 | modem out |
| 7 | RTS | 7 | modem in |
| 8 | CTS | 8 | modem out |
| 9 | RI | 9 | modem out |
| 10 | NC | - | leave unconnected |

For a plain terminal without flow control you only need **RXD (2), TXD (3) and
GND (5)**; the others are for DCD/DTR/DSR/RI signalling and RTS/CTS flow
control.

## Option B (derived, NOT tested): adapt a DTK/Intel cable

If you already own a DTK/Intel cable, put a small remapping adapter between
J12 and the cable's header socket. For each cable-socket pin (left) take the
signal from the J12 pin (right):

| DTK/Intel cable socket pin | carries | connect to J12 pin |
|---|---|---|
| 1 | DCD | 1 |
| 2 | DSR | 6 |
| 3 | RXD | 2 |
| 4 | RTS | 7 |
| 5 | TXD | 3 |
| 6 | CTS | 8 |
| 7 | DTR | 4 |
| 8 | RI | 9 |
| 9 | GND | 5 |

This table is derived from the two published pin orders above; it has **not**
been built or tested. It is not a simple reversal, so re-crimping a DTK/Intel
cable's connector "the other way round" does not fix it - the pins must be
individually remapped.

## Check it works

1. Terminal at 1200 baud 8N1 (factory default), no flow control.
2. Power the board, wait for the VFD to show it is ready, type `AT` + Enter.
3. `OK` = cable good. Nothing = check jumpers J4/J5/J8
   ([`BRING_UP.md`](BRING_UP.md#3-set-the-jumpers)) *and* this cable.

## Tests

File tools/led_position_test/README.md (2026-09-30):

# LED polarity/position test

A small sketch that lights each front-panel LED in turn, steadily, for 3 seconds while the VFD names it
and shows its position and PCB designator, so you can confirm the LEDs sit in the right order (left to
right: **MR, TR, SD, RD, OH, CD, AA, HS** / designators **D8** to **D1**) and light with the correct
polarity after the U4 replacement (see [`../../docs/ERRATA.md`](../../docs/ERRATA.md#e11-most-front-panel-leds-read-inverted)).

**It replaces the modem firmware while it runs.** When you are done, re-flash the firmware from
[`../../firmware/bin/`](../../firmware/bin/). If you compile it with the same board options as the
firmware, the partition table is identical, so the modem's saved settings (baud rate, WiFi) survive.

```bash
arduino-cli compile --fqbn esp32:esp32:esp32s3:FlashSize=16M,PSRAM=opi,PartitionScheme=default_8MB,CDCOnBoot=cdc led_position_test
```

Flash the resulting application image at `0x10000` (see the firmware README for the esptool command).

## What you will see
Each slot shows `Pos N/8 D<n>` and ON/OFF (or the live pin level, for the two slots below) on the top
row, and the LED's label and function on the bottom row.

- **MR, SD, OH, CD, AA, HS** are driven by the ESP32, so exactly one of them lights in its slot, steadily,
  for 3 seconds. If the wrong LED lights, the LEDs are in the wrong physical order.
- **TR (position 2, D7) and RD (position 4, D5)** are driven by the MAX3237, not the ESP32 - forcing them
  would fight the transceiver - so they are **not driven**. They just stay lit or dark during the test and
  the display shows the live pin level. To identify them: open a terminal on the modem serial port
  (your PC asserts DTR - **TR goes dark**) and hold a break on the transmit line (**RD goes dark**).

## Polarity

`U4_INVERTING` (near the top of the sketch) is set to `1`: U4 has been replaced with an inverting
CD74HCT640, so MR, SD and CD light when the ESP32 pin is driven LOW, and the sketch accounts for that.
This is the first hardware confirmation run of that swap - if MR/SD/CD light in the wrong sense here (or
stay dark when the position is "ON"), the swap did not behave as predicted from the datasheet alone (see
ERRATA E11) and needs a closer look before trusting the front panel.

The sketch touches only GPIO and the VFD: no WiFi, no saved settings.

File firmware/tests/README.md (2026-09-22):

# Hardware QA scripts

These are the scripts used to qualify the EngModem Mini Rev5 board
([`../../docs/QUALIFICATION.md`](../../docs/QUALIFICATION.md)). They drive the
board from a PC over its real serial port; there is no mocking. They are
shipped as they were run, so **bench-specific values are hard-coded** and you
must edit them for your setup:

| What | Where | As run |
|---|---|---|
| Modem serial port (J12 / DE-9) | `QA_PORT` environment variable (default in `qa_common.py`) | `COM15` (also run on the motherboard's native `COM1`) |
| Debug UART port (J7) | `serial.Serial("COM5", ...)` in `qa_dtr2.py`, `qa_dcd.py` | `COM5` |
| PC's LAN address (TCP tests, modem dials the PC) | `PC_IP` in `qa_dcd.py`, `qa_dtrhangup.py`, `qa_latency.py`, `qa_pace_noecho.py`, `qa_stream2.py` (`qa_losscurve.py` runs `qa_stream2.py`) | `192.168.1.140` |
| Modem's LAN address (incoming-call test) | `MODEM_IP` in `qa_ri.py` | `192.168.1.149` |
| TCP test port | `PORT_TCP` | `2323` |

Requirements: Python 3, `pip install pyserial`. The modem must be configured
for **115200 baud** at the DE-9 (the scripts start there and put it back), be
on the same LAN as the PC for the TCP tests, and have flow control **off**
(`AT&K0`) at the start. Tests that need a listening PC socket open one
themselves; allow it through the PC's firewall if the modem cannot connect.
Close any terminal program first - the scripts need exclusive use of the port.

| Script | Covers | Checks |
|---|---|---|
| `rtscts_verify.py` | Idle line levels; modem holds output while PC RTS is low and releases it; modem drops CTS when its RX buffer fills and recovers | 14 |
| `qa_sweep.py` | Baud sweep 300-921600: AT answers, RTS holds/releases output at each rate. Rates the PC port rejects (a native 16550 tops out at 115200) are skipped and listed, so the modem is never switched to a speed the PC cannot follow | 50 (38 on a 115200-limited port) |
| `qa_ctsoff.py` | PC-side CTS stays asserted across `AT&K3`/`AT&K0` cycles | 13 |
| `qa_dtr2.py` | DTR and RTS input paths, read from the firmware's own `AT&O88` signal log on the debug UART | prints the `DCRSTOI` bits |
| `qa_dtrhangup.py` | `ATS63=2` hang-up on DTR drop, twice, with an `ATS63=0` control | 18 |
| `qa_bulk.py` | Command-mode echo integrity under RTS/CTS at 9600/115200/921600. Its DTR/RTS section at the top reads the signal log from the *modem* port, but the log is printed on the *debug* port, so those 3 checks always fail - use `qa_dtr2.py` for them | 12 (+3 known-bad) |
| `qa_dcd.py` | Outbound call: DCD at the PC and in the firmware log, data, `+++`, `ATH`. Run on v3, where its 3600-byte stream section failed because of the serial-to-TCP stall that v4 fixes (that section also leaves the signal log running and flow control off, so it is a harsh test); use `qa_stream2.py` for stream integrity | - |
| `qa_stream2.py` | TCP stream integrity: `python qa_stream2.py flow` or `noflow`, then `BYTES` and optional `BAUD`, byte-exact echo, `+++`, `ATH`, DCD | ~10 |
| `qa_ri.py` | Incoming call: RING text, RI pulsing, `ATA`, DCD, data, hang-up. Uses runtime-only `ATS0=0` and `ATA2323`, reverted with `ATN` / `ATS0=1` | 20 |
| `qa_latency.py` | Keystroke round-trip time through a TCP echo | prints statistics |
| `qa_losscurve.py` | Data loss vs stream size with flow control OFF, full-duplex through a PC echo server: `python qa_losscurve.py LABEL 8000:4 20000:3 ...` (size:repeats). This is the test that exposed the receive-buffer bug fixed in v6b | prints lost bytes per run |
| `qa_pace_noecho.py` | One-way upload: PC sends, the PC-side server only counts: `python qa_pace_noecho.py CHUNK GAP_S TOTAL` | prints bytes received |
| `qa_common.py` | Shared helpers (`M` class: open the modem port, `send`, `sync`, `modem_baud`, `check`, `summary`) | - |

Notes:

- If a TCP test stalls the modem (the firmware v3 behaviour that v4 fixes), the
  modem can be left holding a dead connection with a large input backlog;
  reset the board (`J10` EN, or `esptool ... run`) rather than waiting.
- None of the scripts run `AT&W`; settings they change are runtime-only. Each
  script tries to leave the modem at 115200 with flow control off.

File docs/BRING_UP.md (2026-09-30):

# EngModem Mini - builder's bring-up guide (Rev5)

Everything here was learned bringing up a real, assembled Rev5 board in
September 2026. Where something was *measured or observed* it says so; where
it is inferred from the schematic/datasheets it says that instead. The test
evidence is in [`QUALIFICATION.md`](QUALIFICATION.md); known problems are in
[`ERRATA.md`](ERRATA.md).

**Read section 3 (jumpers) before applying power.** Three of the boards'
jumpers have no pull resistors behind them; leaving them off gives a board
that boots but has dead RS-232, which looks exactly like a software problem.

## 1. What you need

| Item | Notes |
|---|---|
| Assembled Rev5 board | [`manufacturing/`](../manufacturing/) has Gerbers, BOM, CPL. SMD parts were JLCPCB-assembled on the tested board. |
| **U3 and U5 hand-soldered** | Excluded from PCBA on purpose - see [ERRATA](ERRATA.md#e2-u3-and-u5-are-hand-soldered-and-u5-was-substituted). Tested: U3 onsemi MC7805CD2TR4G, U5 TI LM1086IS-3.3/NOPB. |
| DC supply | Into **J3** (pin 1 = DC-IN, pin 2 = GND). U3 is a 7805-type linear regulator, so it needs enough headroom above 5 V (see its datasheet). The qualification did **not** characterise the supply range or record rail voltages. |
| USB-C via header **J6** (the USB-C signal breakout header - wire a USB-C breakout or panel jack to it) | For flashing. Pin 4 = D-, pin 5 = D+, pins 1/3/6 = GND. Pin 2 is the board's +5 V rail net (`/VFD-+5V`): **check the schematic before connecting a host's VBUS to it** while the board is powered from J3. |
| 3.3 V USB-serial adapter | For the debug UART on **J7** (see 5). Optional but very useful. |
| Serial cable / adapter from **J12** to a DE-9 | **Read [`J12_CABLE_GUIDE.md`](J12_CABLE_GUIDE.md) first** - most off-the-shelf header-to-DE-9 cables will not work. |
| 24x2 Noritake CU24025ECPB-W1J VFD | On header **J1** (14-pin). |
| microSD card | Optional; enables the `AT+SHELL` SD shell. |
| PC with a terminal program | ZOC, Tera Term, PuTTY, minicom... |

## 2. Inspect before power

1. Check for solder bridges on U1 (MAX3237, TSSOP) and the U2 module pads.
2. Confirm U3 and U5 orientation and that the **tabs are soldered**. On this
   board the U5 tab is wired to the *output* (3.3 V), not ground; U3's tab is
   ground. Mixing the two regulators up shorts a rail.
3. Fit the VFD only after the rails check out (see section 4).

## 3. Set the jumpers

Pin 1 is the pin marked/square on each header; on the three MAX3237 jumpers
**pin 1 = VCC (3.3 V), pin 2 = the signal, pin 3 = GND**.

| Ref | Function | Set to | Why |
|---|---|---|---|
| **J4** | MAX3237 `EN` (receiver enable, active low) | **2-3** (to GND) | Receivers on. Not fitted = floating input, RS-232 receive is unreliable/dead. |
| **J5** | MAX3237 `SHDN` (active low) | **1-2** (to VCC) | Device on. Not fitted or 2-3 = MAX3237 shut down. |
| **J8** | MAX3237 `MBAUD` | **1-2** (to VCC) | MegaBaud mode, up to ~1 Mbps. 2-3 = normal mode (250 kbps max). |
| **J9** | ESP32 `BOOT` (GPIO0) | **OFF** to run | GPIO0 low at reset = ROM download mode (the board will not run the firmware). Fit it only to force flashing. Held for >5 s *while running* it triggers a factory reset that **erases saved settings** (see [ERRATA E10](ERRATA.md#e10-saved-configuration-survives-reflashing)). |
| **J10** | ESP32 `EN` | open | Short briefly to GND to reset the module. |

The tested configuration was **J4 2-3, J5 1-2, J8 1-2**. J8 in 2-3
(normal mode) was **not** tested, so the 115200-and-below behaviour there is
inferred from the MAX3237 datasheet, not measured. The three MAX3237 lines
have no pull resistors on the board - they must be fitted.

Other headers, for reference (from the Rev5 netlist):

| Ref | Pins |
|---|---|
| **J3** DC in | 1 = `/DC-IN`, 2 = GND |
| **J6** USB | 1 GND, 2 +5 V net, 3 GND, 4 D-, 5 D+, 6 GND |
| **J7** expansion + debug UART (2x4) | 1 GPIO21, 2 GPIO38, **3 DEBUG-TXD (GPIO43)**, **4 DEBUG-RXD (GPIO44)**, 5 GND, 6 GND, 7 3.3 V, 8 +5 V |
| **J12** RS-232 (2x5) | 1 DCD, 2 RXD, 3 TXD, 4 DTR, 5 GND, 6 DSR, 7 RTS, 8 CTS, 9 RI, 10 NC |

## 4. First power (no VFD, no cables)

With J9 **off**, apply power to J3 and measure:

- 5 V at U3's output and 3.3 V at U5's output, before plugging in anything
  else. (The qualification did not record these voltages - measuring them is
  the first thing a new builder should do.)
- Supply current with only the ESP32 running should be modest; the VFD adds a
  noticeable load (its supply current increase is how the tested unit's
  builder first confirmed the VFD had power).

## 5. Flash the firmware

Follow [`../firmware/README.md`](../firmware/README.md#quick-start-flash-the-prebuilt-firmware).
Chip identified on the tested board: ESP32-S3 (QFN56), 8 MB PSRAM, 16 MB flash.

Connect the 3.3 V USB-serial adapter to **J7** (adapter RX to J7 pin 3, adapter
TX to J7 pin 4, GND to pin 5 or 6), 115200 8N1, to watch boot. Boot output is
**not** on USB.

Expected boot lines on the tested board:

```
External SD card initialized.
Connected to <your ssid> with IP <address>.
Flow control pins: CTS(in)=17 RTS(out)=18
```

(the last one confirms you are running v2-or-later firmware with the correct
RTS/CTS pin roles for this board).

## 6. Connect the VFD, LEDs, SD

- **VFD (J1)**: check every wire before power - the one failure seen during
  bring-up was a **loose VFD wire**: the display stayed blank although the
  supply current showed it had power. J1 was verified pin-for-pin against the
  VFD datasheet. The firmware sends the display's init sequence once, ~0.25 s
  after boot; if it is ever missed the display stays blank until the next reset.
- **LEDs**: left to right on the front panel MR, TR, SD, RD, OH, CD, AA, HS -
  see [`enclosure/LED_LABELS.md`](../enclosure/LED_LABELS.md) for what each
  one is wired to. Five are driven by RS-232/TTL signals through U4 (a
  CD74HCT640M as of 2026-09-29; originally a 74HCT245 - see ERRATA E11);
  OH, AA and HS are direct GPIOs (12, 10, 11). **Check the order at
  assembly** with [`tools/led_position_test/`](../tools/led_position_test/): on the
  tested unit two LEDs had been fitted swapped. **Expect an inverted-looking panel
  on Rev5 as built** - MR, TR, SD, RD and CD go through U4 from active-low signals
  and read inverted; OH, AA and HS are corrected in firmware v5+. At idle you should
  see MR off, TR on, SD on, RD on, OH off, CD on, AA off, HS on. Details and the
  planned fix (an inverting U4) are in [ERRATA E11](ERRATA.md#e11-most-front-panel-leds-read-inverted).
- **SD**: any microSD card in the Hirose socket; the tested board initialised
  it at boot and the SD shell worked.

## 7. Connect the serial cable and talk to it

1. Wire J12 to a DE-9 as described in [`J12_CABLE_GUIDE.md`](J12_CABLE_GUIDE.md).
   The board is wired as a **DCE** (a modem), so use a straight-through cable
   to a PC's COM port - not a null-modem.
2. Terminal at **1200 baud 8N1, no flow control** (the factory default).
3. Type `AT` then Enter: you should see `OK`. `ATI` prints version and
   network status. `AT+CONFIG` sets up WiFi (2.4 GHz only).
4. To run faster: `ATB115200`, reconnect the terminal at 115200, then `AT&W`
   to save. The board was qualified at every rate from 300 to 921600 baud.
   For rates above 250 kbps, **J8 must be 1-2** (MegaBaud).
5. Optional: `AT&K3` enables RTS/CTS flow control - both the terminal and the
   cable (DE-9 pins 7 and 8) must support it.

## 8. Quick checks that cover the whole board

| Check | How | Pass if |
|---|---|---|
| Serial | `AT` | `OK` |
| WiFi | `ATI` after `AT+CONFIG` | shows an IP address |
| VFD | look at it | shows WiFi/IP status, baud, flow mode |
| SD | `AT+SHELL`, then `?` | shell prompt / command list |
| LEDs | idle, then make a connection (`ATD<host>:<port>`) and watch them | Rev5 as built: idle panel MR off, TR on, SD on, RD on, OH off, CD on, AA off, HS on. During a connection expect **OH to turn on and CD to go dark** (CD reads inverted); TR goes dark when a terminal asserts DTR (seen on the tested unit); HS is expected to be dark below 38400 baud. See [ERRATA E11](ERRATA.md#e11-most-front-panel-leds-read-inverted). |
| Modem lines | terminal's status display, or the [QA scripts](../firmware/tests/README.md) | DSR/CTS asserted at idle; DCD asserts on connect; RI pulses on an incoming call |

## 9. Troubleshooting

| Symptom | Likely cause |
|---|---|
| Nothing on the serial port at all | Jumpers **J4/J5/J8** not fitted as in section 3, or a **DTK/Intel-wired** header cable (see the cable guide), or terminal at the wrong baud (default 1200). |
| Garbage characters | Baud mismatch - the board defaults to 1200 unless you saved another rate. |
| Board seems dead, no boot log, USB shows a download-mode device | **J9 (BOOT) still fitted.** Remove it and reset. |
| No boot messages on USB | By design - they are on the **J7** debug UART, not USB. |
| VFD blank | Loose/incorrect J1 wire (the one real case seen); then power-cycle so the init sequence is re-sent. |
| Terminal hangs after enabling `AT&K3` | The PC/cable is not driving RTS or honouring CTS; use `AT&K0`, or check DE-9 pins 7/8. |
| No serial after `ATB<rate>` | The terminal must be changed to the new rate too (the `OK` is already sent at the new rate). |
| Cannot flash | Use a data-capable USB cable; fit J9, pulse J10 or power-cycle, flash, then remove J9. |
| Unexpected/inconsistent serial port behaviour that doesn't match any symptom above | Try a full device wipe (`esptool erase-flash`) and reflash before assuming a hardware fault - this has resolved otherwise-unexplained cases. |

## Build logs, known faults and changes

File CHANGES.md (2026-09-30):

# Changes

Hardware-side changelog for EngModem Mini. For firmware changes, see
[`firmware/CHANGES.md`](firmware/CHANGES.md).

## U4 hardware fix: inverting buffer confirmed (2026-09-29)

No PCB/schematic change (the fab files are unchanged; this is a field swap on the built unit). U4
(74HCT245, non-inverting) was replaced by hand with a TI **CD74HCT640M** (inverting, pin-compatible,
same SOIC-20-300mil footprint) on the qualified Rev5 unit. A pad was pulled during desoldering and
needed a trace/pad-level repair - worth planning for if you attempt this yourself. Verified afterward
with [`tools/led_position_test/`](tools/led_position_test/) (updated to drive TR/RD for real from the
PC side and confirm the corrected polarity): MR, SD and CD now light correctly. See
[`docs/ERRATA.md`](docs/ERRATA.md#e11-most-front-panel-leds-read-inverted) (now marked fixed) and
[`manufacturing/BOM_full.csv`](manufacturing/BOM_full.csv) (U4 updated to the new part).

## Firmware v6b-rev1 and LED documentation (2026-09)

No design change. Further bring-up on the same Rev5 unit found that most front-panel LEDs read inverted
and that the VFD and the serial receive path had firmware problems; see
[`docs/ERRATA.md`](docs/ERRATA.md) (E8, E11, E12) and [`docs/QUALIFICATION.md`](docs/QUALIFICATION.md#5-re-qualification-on-firmware-v6b-rev1).

- **Firmware updated to `firmware-v6b-rev1`:** VFD init that survives ESP32 resets, AA/HS/OH LED polarity
  corrected, modem UART receive buffer actually applied (it was always 256 bytes, in v4-rev1 too), and a
  per-pass cap in the stream loop. Binaries and checksums under [`firmware/bin/`](firmware/bin/).
- **Docs:** new errata E8 (rewritten), E11 (LED inversion, planned U4 fix - not yet built or verified), E12
  (receive buffer); qualification re-run on v6b-rev1; corrected LED guidance in the bring-up guide.
- **Added** [`tools/led_position_test/`](tools/led_position_test/): blink each LED in turn to confirm the
  front-panel order.
- **Firmware tests:** the QA scripts take a `QA_PORT` setting and gained loss-versus-size and one-way tools.
- **Hardware change proposed, not made:** replace U4 (74HCT245) with a pin-compatible inverting buffer
  (candidate 74HCT640) so all eight LEDs read correctly.

## Rev5 qualification and firmware (2026-09)

No design change - the Rev5 PCB, schematic and Gerbers are unchanged. A Rev5
board was built and qualified on the bench; see
[`docs/QUALIFICATION.md`](docs/QUALIFICATION.md).

- **Added** [`firmware/`](firmware/): the qualified firmware (first `firmware-v4-rev1`, now `firmware-v6b-rev1`) with
  source, binaries, checksums and the hardware QA scripts.
- **Added** [`docs/`](docs/): builder's bring-up guide, qualification report,
  errata, and a J12 cable guide.
- **BOM:** `BOM_full.csv` updated for the qualified U5 substitution
  (TI LM1086IS-3.3/NOPB) and a J12 note about its AT/Everex pin order.
- **README:** removed the "not fabricated or bench-tested" disclaimer; added a
  status section; corrected the design-stage "18/18" firmware cross-check
  claim (it did not check signal direction - see
  [`docs/ERRATA.md`](docs/ERRATA.md#e3-earlier-pin-cross-check-missed-signal-direction)).
- Firmware defects found and fixed during qualification (RTS/CTS roles, saved
  config, DTR input, RTS left deasserted, serial-to-TCP stall) are described in
  [`firmware/CHANGES.md`](firmware/CHANGES.md); none required a board change.

## Rev5: U2 ground-pad via stitching + enclosure jigs

**Hand-solder access for U2's ground pad.** The ESP32-S3-WROOM-1U's
ground/shield pad (a 3x3 cluster of small SMD pads under the module) had
no via or bottom-layer copper connecting it to the board's back side,
making it inaccessible for hot-air rework from below. Added 9 through
vias under the cluster, exposed copper (untented) on the back, and a
matching set of full-size pads mirrored onto the bottom layer so the
back has the same solderable footprint as the top - not just a bare
via, an actual usable pad for hand-soldering heat/solder access. A
keepout zone protects the cluster from future routing, and the board
was fully rerouted with it in place (a genuine Freerouting GUI crash
triggered by the board's existing copper pours, unrelated to the new
keepout, was root-caused and worked around along the way - routed with
the pours temporarily stripped from the DSN export, then refilled
after import).

**U3/U5 excluded from JLCPCB PCBA**, replacements verified against each
manufacturer's own datasheet - see [README.md](README.md#u3-and-u5---excluded-from-pcba-hand-solder-these)
for the full detail.

**Enclosure panel jigs added** (`enclosure/`) - 3D-printable drill and
router-template guides for the Hammond 1455U2201BK front and rear
panels (VFD window, LED holes, VFD mounting holes, and a draft DB9
cutout). See [`enclosure/README.md`](enclosure/README.md) for the full
writeup and its own preliminary-hardware disclaimer - these haven't
been printed or fitted to real hardware yet.

## Manufacturing outputs: U3/U5 regulator substitution

JLCPCB's PCBA placement preview surfaced a real footprint mismatch on
both of the board's D2PAK/TO-263-3 linear regulators - not a rotation or
rendering quirk, an actual lead-count/package mismatch:

- **U3** (5V rail): originally HGSEMI LM7805S2/TR (LCSC C2902505). LCSC's
  own listing shows this part as a 2-lead package, and JLCPCB's 3D model
  shows "TO263-5" case marking - neither matches the 3-lead footprint
  this board uses.
- **U5** (3.3V rail): originally STMicroelectronics LD1086D2T33TR (LCSC
  C7915). ST's own datasheet defines two different D²PAK mechanical
  variants (2-lead and 3-lead) under one ambiguous order code that
  doesn't disambiguate which ships; LCSC/JLCPCB both list this exact part
  as 2-lead.

Both were excluded from the JLCPCB PCBA order (`BOM_PCBA_JLCPCB.csv`,
`CPL_SMD.csv`) rather than risk a bad placement. Verified, datasheet-
confirmed replacements to hand-solder instead (sourced from Mouser/
DigiKey, not JLCPCB/LCSC):

- **U3 -> onsemi MC7805CD2TR4G** (D2PAK-3, CASE 936). Confirmed via
  onsemi's own MC7800 datasheet (the same one already cited in this
  schematic): Pin 1=Input, Pin 2=Ground=Tab, Pin 3=Output - an exact
  match to this footprint and the schematic's pin assignment.
- **U5 -> TI LM1086CSX-3.3/NOPB** (DDPAK/TO-263, package KTT). Confirmed
  via TI's own datasheet: Pin 1=ADJ/GND, Pin 2+Tab=Output, Pin 3=Input -
  an exact match, including the less-common tab-to-Output wiring this
  board's design already uses (verified correct independently, via ST's
  LD1086 datasheet, before the substitution was even needed).

Full detail in `manufacturing/BOM_full.csv` and
[`PIN_MAP.md`](PIN_MAP.md#power-regulation---u3-u5).

## Manufacturing outputs: Gerbers, BOM, CPL

Added for Rev4:

- Gerbers + Excellon drill files (`manufacturing/Gerbers_EngModem-Mini_Rev4.zip`)
- `BOM_PCBA_JLCPCB.csv` - SMD parts JLCPCB will assemble. Common passives
  list full specs with no pinned LCSC number (their basic-parts catalog
  isn't reliably scriptable); the ICs, module, inductor, and microSD
  socket carry LCSC part numbers verified individually against LCSC's own
  product pages, not just search results.
- `BOM_full.csv` - every part on the board, including through-hole
  connectors/headers/LED positions, for hand-assembly.
- `CPL_SMD.csv` - placement file for the JLCPCB-assembled SMD parts,
  generated from the PCB's real component coordinates.

Flagged in the README: JLCPCB's assembly preview renders whichever
specific LCSC library part it matches to a BOM row, using that part's own
reference point for both rotation and position - which doesn't always
agree with KiCad's footprint origin. Check their preview before ordering.

## Board renders

Replaced the initial flat F.Cu/B.Cu + silkscreen SVG plots with isometric
3D renders (`kicad-cli pcb render`, high quality) for the README.

## Revision history

| Rev | Notes |
|---|---|
| 0-1 | Original modular layout and placement baseline |
| 2 | SD card socket swapped from a pin header to the real microSD socket (Hirose DM3AT-SF-PEJM5); full reroute |
| 3 | Second SD placement experiment; full reroute; 69 net-derived pin-function silkscreen labels added across every header/LED footprint |
| 4 | **Current.** Dedicated 0.5mm net class for `/DC-IN`; solid (non-thermal-relief) zone connections on regulator/shield GND tabs; local `/VCC` copper pour + thermal vias around U5; ESP32 power-filter components (L1/C11/C12) relocated for shorter real routed-copper paths to U2 |

## Verification practice

Every revision was checked with KiCad's own tools before being carried
forward: ERC, DRC, footprint/schematic sync. Rev4 additionally got a full
pin-by-pin cross-check against the firmware's actual GPIO usage (18/18
matched). None of this substitutes for bringing up a real board - see the
disclaimer in the README. No physical unit has been built or tested.

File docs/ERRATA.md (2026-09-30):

# EngModem Mini Rev5 - errata and known issues

Things a builder will trip over, found while qualifying a real Rev5 board
(see [`QUALIFICATION.md`](QUALIFICATION.md)). None of them require a board
modification; the suggestions at the end are for a future revision and are
not commitments.

## Hardware and documentation

### E1. J12 pin order differs from common bracket cables

J12 uses the **AT/Everex** header order (pins 1-10 = DCD, RXD, TXD, DTR, GND,
DSR, RTS, CTS, RI, NC, so header pin *n* = DE-9 pin *n*). Many ready-made
2x5-header-to-DE-9 cables use the **DTK/Intel** order (DCD, DSR, RXD, RTS, TXD,
CTS, DTR, RI, GND). Plugging one of those in swaps RXD/TXD/GND and produces
no serial output at all. Confirmed on hardware: a DTK/Intel-wired cable gave no
response; the same header wired 1:1 to a DE-9 breakout gave the Zimodem banner.
The J12 silkscreen is correct - this is a mismatch between the design and the
cable you own.

**Workaround:** wire J12 1:1 to a DE-9, or use an adapter - see
[`J12_CABLE_GUIDE.md`](J12_CABLE_GUIDE.md).

### E2. U3 and U5 are hand-soldered, and U5 was substituted

Both linear regulators were excluded from the JLCPCB assembly (the
originally specified parts did not reliably match the 3-lead D2PAK footprint).
Qualified with:

- **U3 (5 V):** onsemi MC7805CD2TR4G
- **U5 (3.3 V):** TI **LM1086IS-3.3/NOPB** - substituted for the LM1086CSX-3.3/NOPB
  when that variant went out of stock at Mouser (2026-09-16). Per TI's own
  package addendum it is the same DDPAK/TO-263 (KTT) 3-pin package and pinout,
  in the industrial temperature grade (-40 to 125 C) instead of the commercial
  (0 to 125 C); it ships in tubes rather than reels.

`manufacturing/BOM_full.csv` now lists the LM1086IS-3.3/NOPB. The U5 tab is
wired to the *output* on this board (unlike U3, whose tab is ground). The
regulators' output voltages were not recorded during qualification - measure
them on first power.

### E3. Earlier pin cross-check missed signal direction

Earlier revisions of this README reported a firmware/hardware cross-check of
"18/18 GPIO pins matched". That audit compared GPIO **numbers and net names**
only. It did not compare signal **direction**, so it did not catch that the
firmware's default RTS/CTS roles were the reverse of this PCB's DCE wiring.
That is fixed in the firmware (v2 and later) and the claim has been removed
from the README. Treat the schematic-vs-firmware match as *names and numbers*,
verified; *directions*, verified on hardware only for the signals covered in
the qualification report.

### E4. The three MAX3237 jumpers have no pull resistors

J4 (`EN`), J5 (`SHDN`) and J8 (`MBAUD`) each connect a MAX3237 control pin to
VCC or GND **only through the jumper**. A board with them missing boots and
runs but has non-working RS-232, which looks like a firmware problem. Tested
settings: J4 2-3, J5 1-2, J8 1-2. See
[`BRING_UP.md`](BRING_UP.md#3-set-the-jumpers).

### E5. J9 (BOOT) left fitted stops the firmware running

GPIO0 low at reset selects ROM download mode. Fit J9 only to force flashing,
then remove it. (Held for more than 5 s while running it triggers the
firmware's factory reset.)

### E6. Debug output is on J7, not USB

Boot messages and the `AT&O88` signal log go to the UART0 debug port
(GPIO43/44) brought out on **J7 pins 3 (TX) and 4 (RX)**. Nothing is printed
over USB. Some earlier firmware text said otherwise; it was wrong for this
code and has been corrected in `firmware/CHANGES.md`.

### E7. Earlier README status was out of date

Earlier revisions of the README said the board had not been fabricated or
tested, and pointed at a separate `Zimodem-VFD-Mini` firmware repository that
does not exist. The README now describes the qualified status and the firmware
lives in [`../firmware/`](../firmware/).

## Firmware behaviour to know about

### E8. VFD could come up scrambled after a reset (fixed in firmware v5)

The VFD stays powered through an ESP32 reset, its optional `/Reset` pin (J1 pin 3) is not connected, and
the E and RS lines have no pull resistors. Firmware up to v4 sent the display's init once, about 0.25 s
after boot, and never re-checked it. On the tested unit that left the display **scrambled or blank after
about half of the ESP32 restarts** (a 15-boot rotation test: the old init scrambled roughly 7-8 boots;
plain software restarts scrambled about 4 in 22). Cold power-ups were always fine. It also occasionally
dropped the first character written after a cursor-position instruction (the old wait after each
instruction was 1 us).

Firmware v5 and later start with the standard resync (three 8-bit function-set nibbles, then 4-bit),
wait 50 us after every instruction, and re-run the init about once a second during the 7-second splash
window so a bad start repairs itself. Result on the tested unit: 0 scrambles in about 40 warm resets.
The exact mechanism is **not proven** - a theory that the old single-nibble init misaligns a controller
that is already in 4-bit mode was tested and did not reproduce - so the fix rests on the measured
before/after. If you build your own firmware from older sources, expect this behaviour. Suggested for a
future revision: pull-downs on E and RS, and optionally a wire to the module's `/Reset`.

### E9. Command-mode throughput ceiling

In command mode the modem processes roughly 4.6 KB/s regardless of line speed;
with RTS/CTS on, data stays intact above that rate, it is just limited. In
connected (stream) mode ~10.5 KB/s at 115200 was measured.

### E10. Saved configuration survives reflashing

Zimodem's `AT&W` settings live in SPIFFS and are not erased when you reflash
the application. On this board the RTS/CTS pin numbers in a saved config are
ignored (v2+), but other saved settings (baud rate, WiFi, phone book) persist.
To clear everything, use the firmware's factory reset: with the firmware
running, hold GPIO0 low (jumper **J9**) for more than 5 seconds. That erases the
saved configuration, phone book, listeners and WiFi settings and reformats
SPIFFS, so you will need to reconfigure baud rate and WiFi afterwards. Remove
J9 when done. (The factory-reset action itself was not exercised in
qualification.)

### E11. Most front-panel LEDs read inverted

All eight front-panel LEDs are wired anode -> resistor -> drive signal, cathode -> GND, so each lights
when its signal is **HIGH**. But DCD, DSR and DTR are asserted LOW and a serial line idles HIGH, so on
Rev5 **as originally built** (U4 = 74HCT245, non-inverting):

- **OH, AA, HS** (driven directly by GPIO) were inverted in the firmware too. **Fixed in firmware v5**:
  they now light when active.
- **MR, TR, SD, RD, CD** go through U4, a non-inverting 74HCT245, from those active-low signals, so they
  read inverted **in hardware**. Firmware cannot change this.

Idle at 115200, terminal not asserting DTR, no connection - what the panel showed with firmware v5 or
later, before the U4 swap below:

| MR | TR | SD | RD | OH | CD | AA | HS |
|---|---|---|---|---|---|---|---|
| off | on | on | on | off | on | off | on |

So MR was dark when the modem was ready, CD was lit when there was **no** carrier, and SD/RD were lit at
idle and went dark during data (the opposite of a classic modem panel).
The tested unit's panel was observed exactly like this before the firmware fix (OH on, AA on, HS off at
idle), which is how the problem was found. The design-stage checks verified which signal feeds each LED
but never its active level.

**Fix (done and verified on hardware, 2026-09-29):** U4 was replaced with a pin-compatible **inverting**
octal bus transceiver, the TI **CD74HCT640M** (SOIC-20-300mil / 7.5x12.8mm, same package and pinout; with
DIR tied high and OE low, as on this board, B = NOT A). It must be the **HCT** version (the HC version
does not meet the 3.3 V input threshold at 5 V). Sourced via LCSC, part **C1548168** - 0 units in LCSC's
own direct stock at last check, but ~3,000 available through LCSC's "Other Suppliers" channel at a 9-18
business day lead time (checked 2026-09-29; re-check before ordering). It is a single hand-soldered part
swap with no other change to the board - on the tested unit a pad was pulled during desoldering and
needed a trace/pad-level repair, worth planning for if you attempt this yourself.

Verified afterward with [`../tools/led_position_test/`](../tools/led_position_test/) (updated to drive TR
and RD for real from the PC side - DTR toggling and realistic bursty serial traffic - rather than only
showing their live pin level): **MR, SD and CD now light correctly** during their driven slot, matching
the datasheet prediction. At idle: MR on, HS on, everything else dark, with TR lighting when a terminal
asserts DTR, OH and CD on a connection, AA with a listener, and SD/RD flashing with data - the panel now
reads like a classic modem panel. The tested unit's LED **order** (below) was verified physically and is
unaffected by the U4 swap.

**Check LED order at assembly.** Left to right the panel should read MR, TR, SD, RD, OH, CD, AA, HS. On
the tested unit the LEDs at positions 3 and 4 had been fitted in swapped positions and had to be
corrected. **This is not a board design defect** - checked directly against the Rev5 KiCad PCB and
schematic, the eight LED footprints sit at a uniform 5.5 mm pitch in exact D8-to-D1 order left to right,
and each designator's net traces straight through to the signal its position implies, with no gaps or
reversals. The swap was an assembly-time mistake on this one hand-built unit (the wrong LED inserted
into the D5/D6 holes), not a fault in the layout. [`../tools/led_position_test/`](../tools/led_position_test/)
blinks each LED in turn while the display names it (read its note about polarity first). TR and RD are
driven by the MAX3237 and cannot be blinked from the ESP32; identify them by opening a terminal on the
modem port (DTR asserted: TR goes dark) and by holding a break on the transmit line (RD goes dark).

### E12. Serial receive buffer was 256 bytes, not 4096 (fixed in firmware v6b)

The firmware asks for a 4096-byte modem UART receive buffer, but called `setRxBufferSize()` **after**
`begin()`, and the ESP32 Arduino core (3.3.11) rejects that once the port is running. The buffer was
therefore always the 256-byte default - in the published `firmware-v4-rev1` too. With **flow control off**
and traffic in both directions at full 115200 line rate, the receive path then overflowed and lost data in
whole 129-byte chunks. On the tested unit (PC echo server, 115200): echo streams lost data from 8 KB up
(in most runs from 20 KB up), and 30 KB and 40 KB streams were never clean (0 of 6). One-way transfers (PC sending, the
network only receiving) were lossless up to 100 KB, and RTS/CTS on was lossless in every test.

Firmware v6b sets the buffer before `begin()` and limits how many bytes the stream loop handles per pass,
because the bigger buffer alone made flow-controlled two-way traffic 30-100% slower. Measured after the
fix: flow-off echo streams from 3.6 KB to 40 KB were clean in all 20 runs; flow-controlled 200 KB two-way
streams were byte-exact at the original speed; flow-controlled 100 KB streams at 230400, 460800 and
921600 baud were byte-exact at ~17.5 KB/s.

**What remains:** with flow control off, a *sustained* full-speed two-way stream of about 60 KB can still
lose data (one of two runs did), because the modem forwards slightly slower than a full-speed sender can
push in both directions at once - no buffer size fixes that. **Use RTS/CTS (`AT&K3`) for long transfers.**
An occasional "one byte short on the echo return" in flow-off echo runs was also seen before the fix and
has an unknown cause.

## Suggestions for a future revision (not commitments)

- Add pull resistors (or solder-jumper defaults) for J4/J5/J8 so a missing
  jumper cannot silently kill RS-232.
- Use the header pin order of the cables in common use (DTK/Intel), or add a
  solder-jumper to pick either order, or provide a DE-9 directly on the board.
- Add test points on the 5 V, 3.3 V and GND rails.
- Silkscreen J7 pins 3/4 as `DBG TX/RX`.
- Spec U4 as the inverting TI CD74HCT640M by default (confirmed fix, see E11 above), rather than the
  original 74HCT245, so a fresh build reads all eight LEDs correctly without a field hand-swap; and check
  active levels, not only connectivity, when auditing LED/signal paths.
- Pull-downs on the VFD's E and RS lines (see E8).

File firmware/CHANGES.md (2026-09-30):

# Changes from upstream Zimodem

This is a fork of Bo Zimmerman's [Zimodem](http://www.zimmers.net) (see `NOTICE`),
targeting the ESP32-S3-16R8 DevKitC-1 specifically, with a 24x2 character VFD status
display added. This document describes every functional change from upstream, based
on a direct diff against the upstream source tree.

This particular copy (`ENGMODEM_MINI_BOARD`) is further forked from the base
`Zimodem-VFD` to target the EngModem Mini custom PCB - see "EngModem Mini board
support" below for what's different from the base fork.

## EngModem Mini board support

Added after a systematic pin-by-pin cross-check between this firmware's
`#define`s and the actual EngModem Mini schematic/PCB (every modem-control,
SD, and VFD signal matched exactly - 18 for 18; these two gaps were the only
mismatches found - but see the v2 RTS/CTS entry below: that audit compared GPIO
numbers and net names, not signal direction, and missed a third problem). New `ENGMODEM_MINI_BOARD` flag in `zimodem.ino` gates both
fixes so the base `ARDUINO_ESP32S3_DEV` dev-board behavior is unchanged unless
this flag is defined.

- **GPIO38 boot-time write was firing on hardware that doesn't have the pin it
  was written for.** `setup()` unconditionally called `neopixelWrite(38, 0, 0,
  0)` on any `ARDUINO_ESP32S3_DEV` build, to clear the DevKitC-1 dev board's
  onboard addressable RGB LED. EngModem Mini has no such LED - that pin is
  wired out to the expansion header instead as a general-purpose GPIO - so the
  dev board's board-specific cleanup write was landing on Mini's expansion
  pin as a spurious WS2812 protocol pulse train on every boot. Now skipped
  entirely when `ENGMODEM_MINI_BOARD` is defined.

- **`SUPPORT_LED_PINS`'s 3 status-LED pins didn't match Mini's actual
  wiring, and the feature was disabled by default besides.** The existing
  AA/HS/WIFI pin block hardcoded GPIO35/34/26 - not just wrong for this
  board, but GPIO26 isn't even usable on this module (it's in the
  reserved flash/octal-PSRAM range per the Hard Constraints table in
  `PIN_MAP.md`). EngModem Mini's real wiring for its 3 direct-drive status
  LEDs is GPIO10/AA, GPIO11/HS, GPIO12/OH. Enabled `SUPPORT_LED_PINS` by
  default for this fork and added an `ENGMODEM_MINI_BOARD`-gated branch with
  the correct pins.

- **Board's third LED (silkscreened "OH") now shows genuine off-hook status,
  not WiFi association.** Previously reused `DEFAULT_PIN_WIFI`'s existing
  drive logic as-is (lit when `WiFi.status() == WL_CONNECTED`) - correct pin,
  wrong signal. Confirmed via a schematic trace that OH (GPIO12) and DCD
  (GPIO5) are separate, dedicated signals, not hardware-tied together, so
  this needed a real firmware fix rather than reusing DCD's existing pin
  write. Now driven from `checkOpenConnections()`, gated behind
  `ENGMODEM_MINI_BOARD`, based on `WiFiClientNode::getNumOpenWiFiConnections()`
  - the same protocol-agnostic connection count that already drives DCD.
  Every connection type in this codebase (telnet/`ATD`, SSH, FTP data
  channels, IRC, print) registers as a plain `WiFiClientNode` with no
  subclassing, so this one hook genuinely covers all of them: lit whenever
  at least one connection of any kind is open, off when none are. The two
  prior `DEFAULT_PIN_WIFI` writes driven by `WiFi.status()` (on Wi-Fi
  connect, and at boot) are now skipped for `ENGMODEM_MINI_BOARD` builds so
  they no longer fight the connection-status writes.

- **Hardware note (not a firmware change): U3/U5 regulator substitutions.**
  Not a code change - flagged here since anyone building this board from
  the firmware repo's docs should know about it. JLCPCB's PCBA placement
  preview surfaced a footprint mismatch on both of the board's D2PAK/
  TO-263-3 linear regulators: the originally spec'd parts (HGSEMI
  LM7805S2/TR for the 5V rail, ST LD1086D2T33TR for the 3.3V rail) don't
  reliably match the board's 3-lead footprint (confirmed against LCSC's
  own listings, and for the ST part, against ST's own datasheet, which
  defines two different D²PAK mechanical variants under one ambiguous
  order code). Verified, datasheet-confirmed replacements: onsemi
  **MC7805CD2TR4G** (5V) and TI **LM1086CSX-3.3/NOPB** (3.3V), both
  pin/tab-matched to the existing footprint. (The CSX variant later went out of
  stock; the board that was qualified uses TI **LM1086IS-3.3/NOPB**, the same
  DDPAK/TO-263 package and pinout in the industrial temperature grade.) Full detail in the hardware
  repo's `manufacturing/BOM_full.csv` and README.

- **Fixed: RTS/CTS pin roles were backwards for this PCB (v2).** The dev-board
  pin block assigns CTS=GPIO18 (input) and RTS=GPIO17 (output). On the
  EngModem Mini the MAX3237 is wired DCE-style: GPIO17 is fed by the
  receiver output ROUT2 (the PC's RTS from DB9 pin 7) and GPIO18 drives the
  transmitter input DIN3 (out to the PC's CTS on DB9 pin 8). With the
  dev-board assignment the firmware drove GPIO17 against ROUT2 whenever the
  PC's RTS was not asserted, and read GPIO18 as CTS while nothing drove it
  (the MAX3237's driver inputs have no pull-ups), so hardware RTS/CTS flow
  control (`AT&K3`) could not have worked. Earlier pin-map audits matched
  GPIO *numbers and net names* against the schematic, which is why this was
  not caught - signal *direction* was not compared. Under
  `ENGMODEM_MINI_BOARD` the assignments are now **CTS=GPIO17 (input)** and
  **RTS=GPIO18 (output)**.
- **Saved config can no longer move the RTS/CTS pins on this board (v2).**
  The config file written by `AT&W` stores the CTS/RTS pin numbers and
  re-applies them after the compiled-in defaults, and it survives a reflash.
  A config saved by v1 firmware would therefore silently restore the old,
  wrong assignment. On `ENGMODEM_MINI_BOARD` the saved CTS/RTS pin numbers
  are ignored (pin directions are still re-asserted). The `AT` commands that
  change pins at runtime are unaffected.
- **Boot diagnostic (v2).** The debug UART now prints
  `Flow control pins: CTS(in)=17 RTS(out)=18` after the saved config is
  applied, to confirm the effective assignment on hardware.
- **DTR input pin (GPIO4) is now configured (v3).** The ESP32-S3 `pinSupport[]`
  table (dev-board list: 1, 5-21, 36-38, 47, 48) omits GPIO4, and
  `pinMode(pinDTR, INPUT)` is only called for supported pins. On EngModem Mini
  DTR (MAX3237 ROUT3) lands on GPIO4, so the pin was never set up and DTR
  changes from the PC were not seen by the firmware. Found during QA: the
  `AT&O88` signal log showed no T-bit change while the PC toggled DTR. The
  firmware acts on DTR only when hang-up-on-DTR is enabled (`ATS63=2`); verified
  on hardware that dropping PC DTR then ends the call (`NO CARRIER`, DCD released)
  and that with `ATS63=0` (default) it does not. Before this fix `ATS63=2` could
  not have worked on this board.
- **RTS pin no longer left deasserted after leaving RTS/CTS mode (v3).** After
  `AT&K3` then `AT&K0` the UART peripheral kept owning the RTS pin and left it
  in the deasserted state, which on this board is the PC's CTS line - a PC that
  honours CTS would stall. Turning hardware flow control off now returns the pin
  to a plain GPIO output and asserts it, the same state as at boot.
- **Serial->TCP bytes are coalesced instead of sent one per segment (v4).**
  In stream (connected) mode every byte received from the PC was written to the
  socket on its own, and with `DEFAULT_NO_DELAY` each one became a separate TCP
  segment. Found in QA against a PC-hosted TCP server: a full-speed burst
  (3600 B at 115200) delivered only ~500 B, a sustained ~5 KB/s stream ~1000 B,
  after which the modem consumed roughly one serial byte every 10.0 s
  (the core's socket-write retry timeout) and dropped the rest; only streams
  slower than ~300 B/s were clean. This is inherited upstream behaviour, not
  something the EngModem Mini hardware causes. `ZStream::serialIncoming` now
  queues bytes (`txQueue`) and sends them as one write when 250 bytes are
  queued, when serial has been idle for 2 ms, or when the oldest queued byte is
  10 ms old (`txFlush`/`txFlushIfDue`). Added latency is at most 10 ms; byte
  order is preserved (the queue is flushed before any escape-sequence bytes
  and before leaving stream mode). Gated on `ENGMODEM_MINI_BOARD`; other
  builds keep the original per-byte path.
- **AA / HS / OH LEDs were inverted on this board (v5).** On the EngModem Mini these three
  LEDs are wired GPIO -> 330R -> LED anode, cathode -> GND, so they light when the pin is driven
  HIGH. The firmware's dev-board constants are active-LOW, so on the built board AA and OH were lit
  at idle and dark when "active", and HS was dark at 115200. Found when the owner compared the
  panel with the design: at idle the panel showed MR off, TR on, SD on, RD on, OH on, CD on, AA on,
  HS off. Under `ENGMODEM_MINI_BOARD` the AA/HS/OH active levels are now HIGH. All writes to these
  pins go through the `DEFAULT_*_ACTIVE/INACTIVE` constants, so every code path flips together.
  The other five LEDs (MR TR SD RD CD) are driven through U4 from active-LOW modem signals; their
  inversion was a hardware matter and not something firmware could change.
  **Update (2026-09-29):** U4 has since been hand-swapped from the original non-inverting 74HCT245 to
  a pin-compatible inverting TI CD74HCT640M and verified on hardware - see
  [`../docs/ERRATA.md`](../docs/ERRATA.md#e11-most-front-panel-leds-read-inverted).
- **VFD initialisation made robust against warm resets (v5).** On the real board the display came
  up scrambled after ESP32 resets (the VFD stays powered through them): in a rotation test the v4
  init scrambled roughly half of warm resets, while a resync-first init, a resync init re-sent once
  a second, and the old init with 50 us instruction waits were each clean (15 boots each). Three
  changes under `ENGMODEM_MINI_BOARD`, all in `vfd.ino`:
  - `vfdResyncInit()`: three 8-bit function-set nibbles (0x3) then 0x2, then the usual
    instructions. Works from any controller state; used at boot.
  - A 50 us wait after every instruction (was 1 us). This also addresses an occasionally
    dropped first character on a row seen right after a Set-DDRAM-Address instruction.
  - During the 7 s splash window `vfdResyncInit()` is re-run about once a second, so a display
    that came up wrong repairs itself instead of staying scrambled until the next reset.
  The theory that the old single-nibble init misaligned an already-4-bit controller was tested
  and did NOT reproduce (repeating the old init was harmless), so the exact mechanism is still
  unproven; the fix is justified by the measured before/after, not by a proven cause.
  A test-only macro `ENGMODEM_VFD_RESET_TEST` (never defined in release builds) restarts the ESP32
  every ~8.5 s so warm resets can be watched in a row.
- **Modem UART receive buffer was stuck at 256 bytes; now 4096 (v6b).** `setup()` called
  `HWSerial.setRxBufferSize(RX_BUFFER_SIZE)` AFTER `HWSerial.begin()`. The Arduino-ESP32 core rejects that
  once the port is running ("RX Buffer can't be resized when Serial is already running"), so the UART has
  always used the 256-byte default. With flow control OFF and traffic in both directions at full 115200
  line rate, the receive path overflowed and lost data in whole 129-byte chunks (UART FIFO overflow
  resets): on the built board, echo streams lost data from 8 KB up, in most runs from 20 KB up (30 KB: 0 of 3 clean,
  40 KB: 0 of 3 clean; 20 KB: about 13% lost in the worst run). RTS/CTS ON was always lossless, and one-way
  transfers (PC sending, network sinking) were lossless up to 100 KB even before this change. Under
  `ENGMODEM_MINI_BOARD` the size is now set before `begin()`.
- **Serial->socket loop handles at most 250 bytes per pass (v6b).** Enlarging the buffer alone (an interim
  build called v6) let `ZStream::serialIncoming()` drain up to 4096 bytes in one pass, starving the
  socket->serial direction: the flow-controlled 200 KB duplex stream slowed from ~18 s to 24-37 s and one
  run returned 199,999 of 200,000 bytes. `serialIncoming()` now handles at most `ZSTREAM_RX_PASS_MAX`
  (250, one TX-buffer's worth) bytes per pass, so both directions are serviced alternately. Measured on
  the built board (115200, COM1 and COM15): flow-controlled 200 KB duplex 17.6-19.4 s, byte-exact 5 of 5
  (v5-rev1: 18.1-18.9 s); flow-off echo 3.6-40 KB clean in all 20 runs (v5-rev1 lost data from 8 KB up);
  one-way 20 KB and 100 KB lossless; 100 KB flow-controlled streams at 230400/460800/921600 byte-exact at
  ~17.3-17.8 KB/s (unchanged). Flow-off, full-duplex, sustained streams of ~60 KB can still lose data
  (2 runs: one clean, one lost 2,709 bytes): the modem forwards slightly slower than a full-speed sender in
  both directions at once, so no buffer size makes that lossless - use RTS/CTS for long transfers.
  A "1 byte short on the echo return" also appears occasionally in flow-off echo runs; it was present in
  v5-rev1 baselines too and its cause is not known.

- **SSH sessions always requested a PTY with TERM="vanilla" (v7).** `AT&S41=<termtype>` sets a
  global (`termType`) that the Telnet path (`pet2asc.ino`) correctly sends in its TERMTYPE option
  negotiation, but `wifisshclient.ino`'s `libssh2_channel_request_pty()` call passed the literal
  string `"vanilla"` instead - a leftover placeholder with no meaning to libssh2 or the SSH protocol,
  so the configured term type never reached an SSH host. Found by inspection, confirmed with a local
  test SSH server that logs the pty-req TERM value it receives: before this fix every SSH session
  arrived as `vanilla` regardless of `AT&S41`; after, it matches. Telnet was unaffected either way.
  One-line fix: pass `termType.c_str()` instead of the literal.

## New: 24x2 character VFD status display

Entirely new files, `vfd.h` / `vfd.ino`. Drives a Noritake CU24025ECPB-W1J (24x2)
VFD directly over its 4-bit parallel bus - no I2C bridge, no second microcontroller.
See `PIN_MAP.md` for wiring.

- **Splash screen** on boot: "Zimodem", firmware version. Re-sent periodically for a
  short window after boot, since a VFD controller that isn't fully awake yet can lose
  a one-shot write.
- **Top row**: WiFi status ("No WiFi"), or IP address + "Ready" when idle, or the
  current/destination host address while connected - alternates between pages,
  scrolling if a hostname is too long to fit.
- **Bottom row**: `TX`/`RX` activity indicators (custom arrow glyphs, held briefly
  after each byte so brief activity is visible), an `Sd` indicator (2 columns,
  reserved whether or not shown) when the SD shell is available, the current baud
  rate (abbreviated above 9600, e.g. "115.2k"), and the current flow control mode
  ("RTS/CTS", "XON/XOFF", or "NONE"), right-aligned.
- **Brightness control**: `AT$VFDB=<0-4>` - 0 blanks the display (and powers down the
  VFD's internal converter, a real power saving, not just a dark screen), 1-4 select
  25/50/75/100% brightness. The hardware only has 4 real brightness levels, so this
  maps 1:1 rather than approximating a finer scale.

The flow control field required a genuine architectural fix, not just wiring up a
read: `ZSerial::flowControlType` was a plain per-instance member, but each mode
(`ZCommand`, `ZStream`, `ZConfigMode`, etc.) keeps its own separate `ZSerial`
instance. An AT command like `ATF0`/`AT&K3`, issued in command mode, updated
`ZCommand`'s own copy - but the display read `ZStream`'s copy (`streamMode`), which
is only otherwise touched on connect, from that connection's own remembered
preference. The physical UART itself was always being reconfigured correctly
(`uart_set_hw_flow_ctrl()` doesn't care which `ZSerial` instance calls it) - only the
display's copy of the setting was stale. Fixed by making `flowControlType` a `static`
member of `ZSerial`, shared across every instance, matching how `baudRate` already
works as a single global (`serout.h`, `serout.ino`).

The VFD status line only ever distinguished "RTS/CTS" from "NONE" at first - a
missing "XON/XOFF" label meant that mode silently displayed as "NONE" too. Added.

## Fixed: hardware RTS/CTS flow control silently hung TX

Two independent bugs in `zimodem.ino`, both required to reproduce: enabling hardware
RTS/CTS flow control (`AT&K3`/`ATF0`) caused all further serial output to be silently
and permanently withheld - the command's own echo transmitted, but its `OK` never
arrived, and every command after it was silent too, with no software recovery.

1. **`pinSupport[]` never marked the CTS pin as supported.** The setup loop that
   marks which GPIOs are registered had a gap between two disjoint ranges
   (`5..17` and `19..21`) that happened to exclude GPIO18 - this board's default CTS
   pin - for its entire life. `ZSerial::setFlowControlType()` gates the actual
   `uart_set_pin()` CTS registration behind this check, so the CTS pin was never
   wired into the UART peripheral at the driver level, even though hardware flow
   control was still unconditionally enabled with no valid CTS input. Fixed with a
   single contiguous range.

2. **Unclamped `dequeSize` made the TX throttle a silent no-op at common baud
   rates.** `dequeSize` controls how many bytes `serialOutDeque()` releases from the
   software output buffer into the hardware TX ring per pass. The formula
   (`1+(baud/380)`) isn't clamped against the hardware ring's actual size
   (`SER_BUFSIZE`, 127 usable bytes) - at 115200 baud it evaluates to 304, larger
   than the buffer could ever report as "used," making the throttle condition
   permanently false. Once bug #1 was fixed and flow control genuinely started
   applying backpressure, this became actively harmful rather than a no-op:
   `serialOutDeque()` would drain the entire pending output buffer in one pass the
   moment flow control released, rather than trickling it, producing jumbled,
   misaligned multi-response output. Fixed with `calcDequeSize()`, which clamps the
   formula's result to `SER_BUFSIZE-1`.

Verified against real hardware across the full baud range Zimodem offers (300 through
921600), both directions (ESP32-to-DTE via RTS, DTE-to-ESP32 via CTS backpressure).

## Fixed: SD shell status could be wrong if the card wasn't ready yet at cold boot

`initSDShell()` runs very early in `setup()`, before anything else gives a
cold-booted SD card time to settle on the SPI bus. Added up to 5 retries, 50ms apart.

## Fixed: a connection you `+++`'d away from could interrupt command mode

`ZCommand::sendNextPacket()`'s condition for announcing buffered incoming data from a
non-foreground connection didn't exclude the connection you're actively `+++`'d away
from (`current`) - now it stays silent until you explicitly `ATO` back to it or `ATH`
it, matching how a real Hayes dialup modem behaves: it doesn't announce data from a
call you've stepped away from, it just waits quietly. `NO CARRIER` still fires
normally if that connection drops while you're away from it.

## ESP32-S3-16R8 DevKitC-1 pin map

The upstream `ARDUINO_ESP32S3_DEV` pin block existed but needed real hardware
verification and several corrections for this specific module (N16R8, octal PSRAM).
See `PIN_MAP.md` for the full current pin table and rationale. Notable corrections
from the original block:

- `DSR` moved from GPIO9 to GPIO7, closing a gap in an otherwise-contiguous run.
- SD card moved off the ESP32-S3 core's *default* SPI pins onto dedicated ones
  (CS=GPIO13, MOSI=GPIO14, MISO=GPIO1, SCK=GPIO2), requiring an explicit `SPIClass`
  instance rather than the bare `SD.begin(cs)` call upstream used.
- The onboard addressable RGB LED (GPIO38) is explicitly cleared to off at boot -
  it holds whatever it last received indefinitely, it doesn't reset itself just
  because the pin goes idle otherwise.

## Minor

- A commented-out debug line was removed from `ZSerial::isSerialCancelled()`
  (`serout.ino`) - dead code, no behavior change.
- A `Serial.begin(115200)` call was added in `setup()` as a standing diagnostic hook.
  **Correction (2026-09-21, from bring-up on the real EngModem Mini):** the earlier
  text here said native USB-CDC `Serial` is the only debug path. That is wrong for
  this code: `debugPrintf` is `DBSerial` (UART0), and nothing prints to USB-CDC.
  On the EngModem Mini, UART0 (GPIO43/44) is brought out on header **J7** (pin 3 =
  `DEBUG-TXD`, pin 4 = `DEBUG-RXD`, pins 5/6 = GND) - connect a 3.3 V USB-serial
  adapter there at 115200 to see the boot log, `AT&O88` signal log, and the
  `Flow control pins:` line.

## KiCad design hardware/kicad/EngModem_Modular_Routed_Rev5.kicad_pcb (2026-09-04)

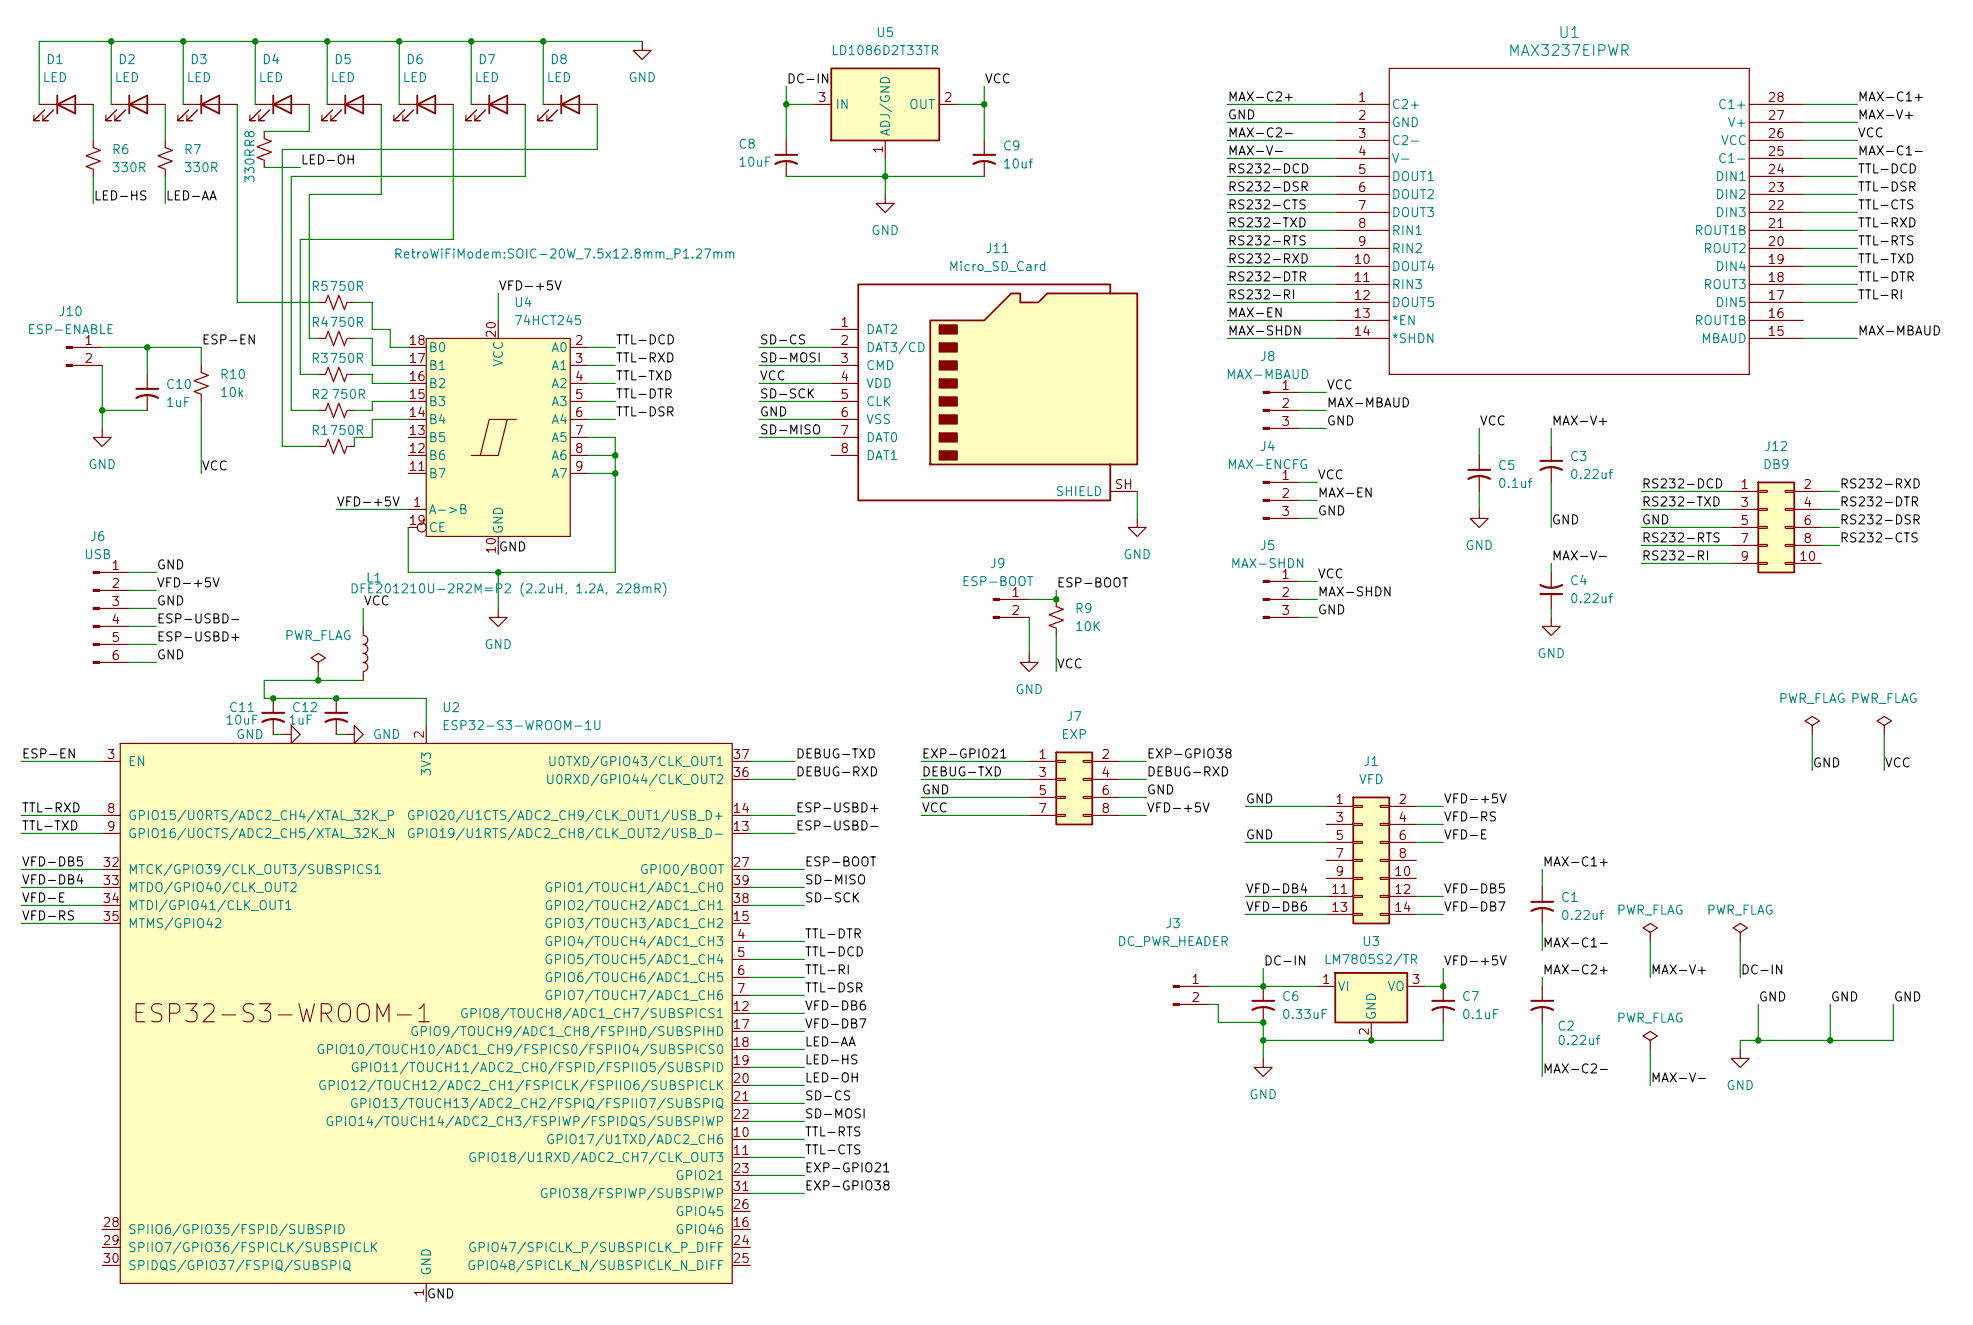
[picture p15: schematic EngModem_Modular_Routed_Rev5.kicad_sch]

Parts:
C1, C2, C3, C4: 0.22uf; C_0805_2012Metric
C5: 0.1uf; C_0805_2012Metric
C6: 0.33uF; C_0805_2012Metric
C7: 0.1uF; C_0805_2012Metric
C8: 10uF; C_1206_3216Metric
C9: 10uf; C_0805_2012Metric
C10, C12: 1uF; C_0805_2012Metric
C11: 10uF; C_0805_2012Metric
D1, D2, D3, D4, D5, D6, D7, D8: LED; PinHeader_1x02_P2.54mm_Vertical
J1: VFD; PinHeader_2x07_P2.54mm_Vertical
J3: DC_PWR_HEADER; PinHeader_1x02_P2.54mm_Vertical
J4: MAX-ENCFG; PinHeader_1x03_P2.54mm_Vertical
J5: MAX-SHDN; PinHeader_1x03_P2.54mm_Vertical
J6: USB; PinHeader_1x06_P2.54mm_Vertical
J7: EXP; PinHeader_2x04_P2.54mm_Vertical
J8: MAX-MBAUD; PinHeader_1x03_P2.54mm_Vertical
J9: ESP-BOOT; PinHeader_1x02_P2.54mm_Vertical
J10: ESP-ENABLE; PinHeader_1x02_P2.54mm_Vertical
J11: Micro_SD_Card; microSD_HC_Hirose_DM3AT-SF-PEJM5
J12: DB9; IDC-Header_2x05_P2.54mm_Vertical
L1: DFE201210U-2R2M=P2 (2.2uH, 1.2A, 228mR); L_0805_2012Metric
R1, R2, R3, R4, R5: 750R; R_0805_2012Metric
R6, R7, R8: 330R; R_0805_2012Metric
R9: 10K; R_0805_2012Metric
R10: 10k; R_0805_2012Metric
U1: MAX3237EIPWR; PW28
U2: ESP32-S3-WROOM-1U
U3: LM7805S2/TR; TO-263-3_TabPin2
U4: 74HCT245; SOIC-20W_7.5x12.8mm_P1.27mm
U5: LD1086D2T33TR; TO-263-3_TabPin2

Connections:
/DC-IN: C6.1, C8.1, J3.1, U3.1 (VI), U5.3 (IN)
/DEBUG-RXD: J7.4, U2.36 (U0RXD/GPIO44/CLK_OUT2)
/DEBUG-TXD: J7.3, U2.37 (U0TXD/GPIO43/CLK_OUT1)
/ESP-BOOT: J9.1, R9.1, U2.27 (GPIO0/BOOT)
/ESP-EN: C10.1, J10.1, R10.1, U2.3 (EN)
/ESP-USBD+: J6.5, U2.14 (GPIO20/U1CTS/ADC2_CH9/CLK_OUT1/USB_D+)
/ESP-USBD-: J6.4, U2.13 (GPIO19/U1RTS/ADC2_CH8/CLK_OUT2/USB_D-)
/EXP-GPIO21: J7.1, U2.23 (GPIO21)
/EXP-GPIO38: J7.2, U2.31 (GPIO38/FSPIWP/SUBSPIWP)
/LED-AA: R7.2, U2.18 (GPIO10/TOUCH10/ADC1_CH9/FSPICS0/FSPIIO4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)
/LED-HS: R6.2, U2.19 (GPIO11/TOUCH11/ADC2_CH0/FSPID/FSPIIO5/S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)
/LED-OH: R8.2, U2.20 (GPIO12/TOUCH12/ADC2_CH1/FSPICLK/FSPIIO6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)
/MAX-C1+: C1.1, U1.28 (C1+)
/MAX-C1-: C1.2, U1.25 (C1-)
/MAX-C2+: C2.1, U1.1 (C2+)
/MAX-C2-: C2.2, U1.3 (C2-)
/MAX-EN: J4.2, U1.13 (*EN)
/MAX-MBAUD: J8.2, U1.15 (MBAUD)
/MAX-SHDN: J5.2, U1.14 (*SHDN)
/MAX-V+: C3.1, U1.27 (V+)
/MAX-V-: C4.2, U1.4 (V-)
/RS232-CTS: J12.8, U1.7 (DOUT3)
/RS232-DCD: J12.1, U1.5 (DOUT1)
/RS232-DSR: J12.6, U1.6 (DOUT2)
/RS232-DTR: J12.4, U1.11 (RIN3)
/RS232-RI: J12.9, U1.12 (DOUT5)
/RS232-RTS: J12.7, U1.9 (RIN2)
/RS232-RXD: J12.2, U1.10 (DOUT4)
/RS232-TXD: J12.3, U1.8 (RIN1)
/SD-CS: J11.2 (DAT3/CD), U2.21 (GPIO13/TOUCH13/ADC2_CH2/FSPIQ/FSPIIO7/S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)
/SD-MISO: J11.7 (DAT0), U2.39 (GPIO1/TOUCH1/ADC1_CH0)
/SD-MOSI: J11.3 (CMD), U2.22 (GPIO14/TOUCH14/ADC2_CH3/FSPIWP/FSPIDQS/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)
/SD-SCK: J11.5 (CLK), U2.38 (GPIO2/TOUCH2/ADC1_CH1)
/TTL-CTS: U1.22 (DIN3), U2.11 (GPIO18/U1RXD/ADC2_CH7/CLK_OUT3)
/TTL-DCD: U1.24 (DIN1), U2.5 (GPIO5/TOUCH5/ADC1_CH4), U4.2 (A0)
/TTL-DSR: U1.23 (DIN2), U2.7 (GPIO7/TOUCH7/ADC1_CH6), U4.6 (A4)
/TTL-DTR: U1.18 (ROUT3), U2.4 (GPIO4/TOUCH4/ADC1_CH3), U4.5 (A3)
/TTL-RI: U1.17 (DIN5), U2.6 (GPIO6/TOUCH6/ADC1_CH5)
/TTL-RTS: U1.20 (ROUT2), U2.10 (GPIO17/U1TXD/ADC2_CH6)
/TTL-RXD: U1.21 (ROUT1B), U2.8 (GPIO15/U0RTS/ADC2_CH4/XTAL_32K_P), U4.3 (A1)
/TTL-TXD: U1.19 (DIN4), U2.9 (GPIO16/U0CTS/ADC2_CH5/XTAL_32K_N), U4.4 (A2)
/VCC: C5.1, C9.1, J4.1, J5.1, J7.7, J8.1, J11.4 (VDD), L1.1, R9.2, R10.2, U1.26 (VCC), U5.2 (OUT)
/VFD-+5V: C7.1, J1.2, J6.2, J7.8, U3.3 (VO), U4.1 (A->B), U4.20 (VCC)
/VFD-DB4: J1.11, U2.33 (MTDO/GPIO40/CLK_OUT2)
/VFD-DB5: J1.12, U2.32 (MTCK/GPIO39/CLK_OUT3/SUBSPICS1)
/VFD-DB6: J1.13, U2.12 (GPIO8/TOUCH8/ADC1_CH7/SUBSPICS1)
/VFD-DB7: J1.14, U2.17 (GPIO9/TOUCH9/ADC1_CH8/FSPIHD/SUBSPIHD)
/VFD-E: J1.6, U2.34 (MTDI/GPIO41/CLK_OUT1)
/VFD-RS: J1.4, U2.35 (MTMS/GPIO42)
GND: C3.2, C4.1, C5.2, C6.2, C7.2, C8.2, C9.2, C10.2, C11.2, C12.2, D1.1 (K), D2.1 (K), D3.1 (K), D4.1 (K), D5.1 (K), D6.1 (K), D7.1 (K), D8.1 (K), J1.1, J1.5, J3.2, J4.3, J5.3, J6.1, J6.3, J6.6, J7.5, J7.6, J8.3, J9.2, J10.2, J11.6 (VSS), J11.SH (SHIELD), J12.5, U1.2 (GND), U2.1 (GND), U2.40 (GND), U2.41 (GND), U3.2 (GND), U4.7 (A5), U4.8 (A6), U4.9 (A7), U4.10 (GND), U4.19 (CE), U5.1 (ADJ/GND)
unnamed: D1.2 (A), R6.1
unnamed: D2.2 (A), R7.1
unnamed: D3.2 (A), R5.2
unnamed: D4.2 (A), R8.1
unnamed: D5.2 (A), R4.2
unnamed: D6.2 (A), R3.2
unnamed: D7.2 (A), R2.2
unnamed: D8.2 (A), R1.2
unnamed: C11.1, C12.1, L1.2, U2.2 (3V3)
unnamed: R5.1, U4.18 (B0)
unnamed: R4.1, U4.17 (B1)
unnamed: R3.1, U4.16 (B2)
unnamed: R2.1, U4.15 (B3)
unnamed: R1.1, U4.14 (B4)

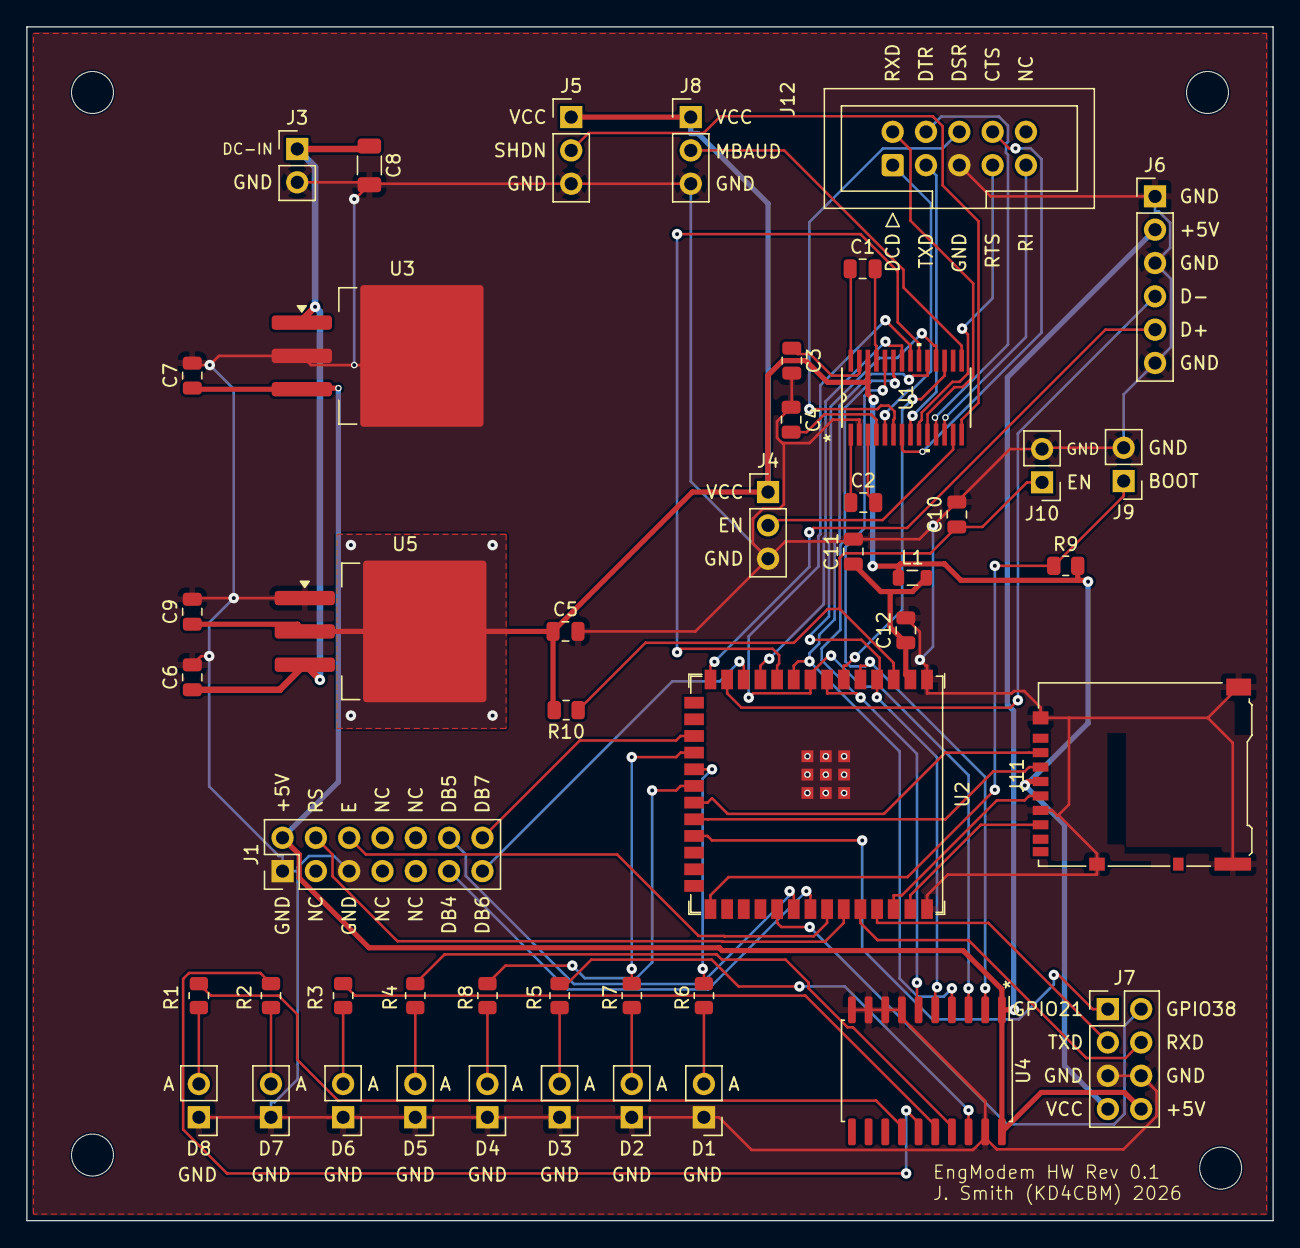
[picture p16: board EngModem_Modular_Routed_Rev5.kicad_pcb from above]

Board: 2 copper layers, 95.0 x 91.0 mm, 51 parts (0 on the bottom side), 64 nets.

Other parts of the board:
MH1_TL, MH2_TR, MH3_BL, MH4_BR: MountingHole_3.2mm_M3

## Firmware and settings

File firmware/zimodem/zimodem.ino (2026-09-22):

/*
   Copyright 2016-2026 Bo Zimmerman

   Licensed under the Apache License, Version 2.0 (the "License");
   you may not use this file except in compliance with the License.
   You may obtain a copy of the License at

     http://www.apache.org/licenses/LICENSE-2.0

   Unless required by applicable law or agreed to in writing, software
   distributed under the License is distributed on an "AS IS" BASIS,
   WITHOUT WARRANTIES OR CONDITIONS OF ANY KIND, either express or implied.
   See the License for the specific language governing permissions and
   limitations under the License. 
*/
//#define TCP_SND_BUF                     4 * TCP_MSS
#define ZIMODEM_VERSION "4.0.3"
const char compile_date[] = __DATE__ " " __TIME__;
#define DEFAULT_NO_DELAY true
#define null 0


#define INCLUDE_IRCC true
#define INCLUDE_SD_SHELL true  /* ESP32 only, requires SPI SD card interface */
#define INCLUDE_CBMMODEM true  // ESP32 only, 1650, 1660, 1670, and Pulse Dialing support
#define INCLUDE_PING true
#define INCLUDE_SSH true   // ESP32 only, adds SSH client
#define INCLUDE_HOSTCM true // requires sd shell
#define INCLUDE_FTP true
#define INCLUDE_COMET64 true // requires sd shell
#define INCLUDE_OTH_UPDATES true // comment out if you make incompatible firmware
#define INCLUDE_SLIP true
#define INCLUDE_PPP true
#define INCLUDE_VFD true  /* ESP32-S3 only, requires the direct-parallel VFD wiring in ESP32S3_PIN_MAP.md */
#define SUPPORT_LED_PINS true // this board has 3 direct-drive status LEDs wired (AA/HS/OH) - see ENGMODEM_MINI_BOARD below
//#define INCLUDE_CMDRX16 true // enable this if you are David or Kevin
//#define USE_DEVUPDATER true // only enable this if your name is Bo

// EngModem "Mini" custom PCB: reuses the ESP32-S3-16R8 DevKitC-1 pin map
// below (ARDUINO_ESP32S3_DEV block) since the wiring matches it exactly,
// but it is NOT that dev board - it has no onboard addressable RGB LED on
// GPIO38 (that pin is a general-purpose expansion header pin instead), and
// it has 3 direct-drive status LEDs on GPIO10/11/12 that the dev board
// doesn't have at all. Gates the two spots below where "any ESP32-S3-16R8
// DevKitC-1 build" and "this specific custom board" need different behavior.
#define ENGMODEM_MINI_BOARD true

// Figure out whether we are building for ESP8266 or ESP32
#if defined(ARDUINO_ESP32_DEV) || defined(ARDUINO_ARCH_ESP32)
# define ZIMODEM_ESP32
#elif defined(ARDUINO_ESP32S3_DEV) || defined(ARDUINO_ESP32C3_DEV)
# define ZIMODEM_ESP32
#elif defined(ESP32)
# define ZIMODEM_ESP32
#elif defined(ARDUINO_ESP320)
# define ZIMODEM_ESP32
#elif defined(ARDUINO_NANO32)
# define ZIMODEM_ESP32
#elif defined(ARDUINO_LoLin32)
# define ZIMODEM_ESP32
#elif defined(ARDUINO_ESPea32)
# define ZIMODEM_ESP32
#elif defined(ARDUINO_QUANTUM)
# define ZIMODEM_ESP32
#else
# define ZIMODEM_ESP8266
# undef INCLUDE_SSH
# undef INCLUDE_SD_SHELL
# undef INCLUDE_CBMMODEM
#endif

#if SUPPORT_LED_PINS
# if defined(ARDUINO_ESP32S3_DEV) && defined(ENGMODEM_MINI_BOARD)
    // EngModem Mini board's real wiring: 3 direct-drive status LEDs,
    // silkscreened AA/HS/OH (Hayes-style: auto-answer, high-speed, off-hook).
    // Reuses the existing AA/HS/WIFI framework's pin slot for OH - the
    // identifier is still DEFAULT_PIN_WIFI, but on this board it's driven
    // as a true off-hook signal (lit while any connection is open - telnet,
    // SSH, FTP, IRC, print - regardless of protocol), not WiFi association
    // status. See checkOpenConnections() for the actual drive logic.
#   define DEFAULT_PIN_AA GPIO_NUM_10
#   define DEFAULT_PIN_HS GPIO_NUM_11
#   define DEFAULT_PIN_WIFI GPIO_NUM_12
# elif defined(GPIO_NUM_0)
#   define DEFAULT_PIN_AA GPIO_NUM_35
#   define DEFAULT_PIN_HS GPIO_NUM_34
#   define DEFAULT_PIN_WIFI GPIO_NUM_26
# else
#   define DEFAULT_PIN_AA 35
#   define DEFAULT_PIN_HS 34
#   define DEFAULT_PIN_WIFI 26
# endif
# define DEFAULT_HS_BAUD 38400
# ifdef ENGMODEM_MINI_BOARD
   // On the EngModem Mini the AA/HS/OH LEDs are wired GPIO -> 330R -> LED anode, cathode -> GND,
   // so they light when the pin is driven HIGH. The dev-board defaults below are active-LOW
   // and left these three LEDs inverted (lit while idle, dark while "active").
#  define DEFAULT_AA_ACTIVE HIGH
#  define DEFAULT_AA_INACTIVE LOW
#  define DEFAULT_HS_ACTIVE HIGH
#  define DEFAULT_HS_INACTIVE LOW
#  define DEFAULT_WIFI_ACTIVE HIGH
#  define DEFAULT_WIFI_INACTIVE LOW
# else
#  define DEFAULT_AA_ACTIVE LOW
#  define DEFAULT_AA_INACTIVE HIGH
#  define DEFAULT_HS_ACTIVE LOW
#  define DEFAULT_HS_INACTIVE HIGH
#  define DEFAULT_WIFI_ACTIVE LOW
#  define DEFAULT_WIFI_INACTIVE HIGH
# endif
#endif

#define DEFAULT_BAUD_RATE 1200
#define DEFAULT_SERIAL_CONFIG SERIAL_8N1
#define RX_BUFFER_SIZE 4096
/*
 * Unused pins on WROOM32:
 * 2, 20, 21, 22.   36,39 (sensor)
 */

#ifdef ZIMODEM_ESP32
# define PIN_FACTORY_RESET GPIO_NUM_0
# define DEFAULT_FCT FCT_DISABLED
# if INCLUDE_CMDRX16                   /* Configuration for the Commander X16 I/O Card */
#  undef INCLUDE_SD_SHELL
#  undef DEFAULT_FCT
#  define DEFAULT_FCT FCT_RTSCTS
#  undef DEFAULT_BAUD_RATE
#  define DEFAULT_BAUD_RATE 115200
#  define DEFAULT_PIN_DCD GPIO_NUM_22
#  define DEFAULT_PIN_CTS GPIO_NUM_19
#  define DEFAULT_PIN_RTS GPIO_NUM_21
#  define DEFAULT_PIN_RI GPIO_NUM_18
#  define DEFAULT_PIN_DSR GPIO_NUM_23
#  define DEFAULT_PIN_DTR GPIO_NUM_25
//#  define DEFAULT_PIN_OPA 26
#  define DEFAULT_PIN_OPB GPIO_NUM_27
#  define DEFAULT_PIN_OTH GPIO_NUM_26 // stream/command mode flag
#  define DEFAULT_PIN_TXD GPIO_NUM_32
#  define DEFAULT_PIN_RXD GPIO_NUM_33
#  define DEFAULT_PIN_SND GPIO_NUM_4
# elif defined(ARDUINO_ESP32C3_DEV)   /* Configuration for the Esp32C3 4MB Dev Board */
#  undef INCLUDE_SD_SHELL
#  undef PIN_FACTORY_RESET
#  define DEFAULT_PIN_DCD GPIO_NUM_8
#  define DEFAULT_PIN_CTS GPIO_NUM_3 // espdev rts pin
#  define DEFAULT_PIN_RTS GPIO_NUM_2 // espdev cts pin
#  define DEFAULT_PIN_RI GPIO_NUM_1
#  define DEFAULT_PIN_DSR GPIO_NUM_4
#  define DEFAULT_PIN_SND GPIO_NUM_6
#  define DEFAULT_PIN_OTH GPIO_NUM_7 // pulse pin
#  define DEFAULT_PIN_DTR GPIO_NUM_5
# elif defined(ARDUINO_ESP32S3_DEV) /* Configuration for the Esp32S3-16R8 DevKitC-1 -
                                        pin map verified against Espressif's J1/J3
                                        header tables; see ESP32S3_PIN_MAP.md at the
                                        repo root for the full rationale. */
#  define DEFAULT_PIN_DCD GPIO_NUM_5
# ifdef ENGMODEM_MINI_BOARD
   // RTS/CTS are wired DCE-style on the EngModem Mini PCB: GPIO17 is fed by the
   // MAX3237's ROUT2 (the PC's RTS, from DB9 pin 7) and GPIO18 drives DIN3 (out to
   // the PC's CTS, DB9 pin 8). Zimodem's UART flow control needs CTS as an INPUT and
   // RTS as an OUTPUT, so on this board those roles sit on the opposite GPIOs from
   // the dev-board layout in the #else branch. Without this swap the firmware
   // drives GPIO17 (which ROUT2 also drives) and reads a floating GPIO18.
#  define DEFAULT_PIN_CTS GPIO_NUM_17 // input: PC's RTS via MAX3237 ROUT2
#  define DEFAULT_PIN_RTS GPIO_NUM_18 // output: to PC's CTS via MAX3237 DIN3
# else
#  define DEFAULT_PIN_CTS GPIO_NUM_18 // espdev rts pin
#  define DEFAULT_PIN_RTS GPIO_NUM_17 // espdev cts pin
# endif
#  define DEFAULT_PIN_RI GPIO_NUM_6
#  define DEFAULT_PIN_DSR GPIO_NUM_7  // moved from GPIO9 to close the gap in the J1 run
#  define DEFAULT_PIN_SND -1
#  define DEFAULT_PIN_OTH -1 // pulse pin
#  define DEFAULT_PIN_DTR GPIO_NUM_4
#  define DEFAULT_PIN_TXD GPIO_NUM_16
#  define DEFAULT_PIN_RXD GPIO_NUM_15
#  define DEFAULT_PIN_SD_CS   GPIO_NUM_13 // moved from GPIO14 - GPIO14 is now SD MOSI
#  define DEFAULT_PIN_SD_MOSI GPIO_NUM_14
#  define DEFAULT_PIN_SD_MISO GPIO_NUM_1
#  define DEFAULT_PIN_SD_SCK  GPIO_NUM_2
   // VFD driven directly over its 4-bit parallel bus - no I2C bridge.
   // R/W is hardwired to GND on the VFD board itself, so it's not an MCU pin.
#  define DEFAULT_PIN_VFD_RS  GPIO_NUM_42
#  define DEFAULT_PIN_VFD_E   GPIO_NUM_41
#  define DEFAULT_PIN_VFD_DB4 GPIO_NUM_40
#  define DEFAULT_PIN_VFD_DB5 GPIO_NUM_39
   // GPIO47/48 are NOT general-purpose on this N16R8 (octal PSRAM) module -
   // they're the SUBSPI differential clock pair used to reach the in-package
   // flash/PSRAM at its 1.8V domain, confirmed reserved in Espressif's own
   // docs. DB7 was there originally and caused a hard no-boot the moment it
   // was wired up; DB6 landed there in the last revision while fixing an
   // unrelated GPIO38/LED conflict, which was an equally bad landing spot
   // that just hadn't been wired up yet to fail visibly. Both now moved to
   // J1's GPIO8/GPIO9 (freed earlier when the VFD I2C bridge was removed) -
   // this means DB6/DB7 physically move to J1, separate from RS/E/DB4/DB5
   // on J3, since J3 has no remaining safe pins after this correction.
#  define DEFAULT_PIN_VFD_DB6 GPIO_NUM_8
#  define DEFAULT_PIN_VFD_DB7 GPIO_NUM_9
# else                                    /* Configuration for standard ESP32 4 & 8MB boards */
#  define DEFAULT_PIN_DCD GPIO_NUM_14
#  define DEFAULT_PIN_CTS GPIO_NUM_13
#  define DEFAULT_PIN_RTS GPIO_NUM_15 // unused?
#  define DEFAULT_PIN_RI GPIO_NUM_32
#  define DEFAULT_PIN_DSR GPIO_NUM_12
#  define DEFAULT_PIN_SND GPIO_NUM_25
#  define DEFAULT_PIN_OTH GPIO_NUM_4 // pulse pin
#  define DEFAULT_PIN_DTR GPIO_NUM_27
# endif
# ifndef DEFAULT_PIN_VFD_RS
#  undef INCLUDE_VFD  // only the ESP32-S3-16R8 DevKitC-1 pin block above defines VFD pins
# endif
# define debugPrintf DBSerial.printf
# define SerialConfig uint32_t
# define UART_CONFIG_MASK 0x8000000
# define UART_NB_BIT_MASK      0B00001100 | UART_CONFIG_MASK
# define UART_NB_BIT_5         0B00000000 | UART_CONFIG_MASK
# define UART_NB_BIT_6         0B00000100 | UART_CONFIG_MASK
# define UART_NB_BIT_7         0B00001000 | UART_CONFIG_MASK
# define UART_NB_BIT_8         0B00001100 | UART_CONFIG_MASK
# define UART_PARITY_MASK      0B00000011
# define UART_PARITY_NONE      0B00000000
# define UART_NB_STOP_BIT_MASK 0B00110000
# define UART_NB_STOP_BIT_0    0B00000000
# define UART_NB_STOP_BIT_1    0B00010000
# define UART_NB_STOP_BIT_15   0B00100000
# define UART_NB_STOP_BIT_2    0B00110000
# define preEOLN(...)
//# define preEOLN serial.prints
# define echoEOLN(...) serial.prints(EOLN)
//# define echoEOLN serial.write
//# define HARD_DCD_HIGH 1
//# define HARD_DCD_LOW 1
#else  // ESP-8266, e.g. ESP-01, ESP-12E
# define DEFAULT_PIN_DSR 13
# define DEFAULT_PIN_DTR 12
# define DEFAULT_PIN_RI 14
# define DEFAULT_PIN_RTS 4
# define DEFAULT_PIN_CTS 5 // is 0 for ESP-01
# define DEFAULT_PIN_DCD 2
# define DEFAULT_PIN_OTH -1 // pulse pin
# define DEFAULT_FCT FCT_DISABLED
# define debugPrintf doNothing //Serial.printf
# define preEOLN(...)
# define echoEOLN(...) serial.prints(EOLN)
#endif

# define DEFAULT_DCD_ACTIVE  LOW
# define DEFAULT_DCD_INACTIVE  HIGH
# define DEFAULT_CTS_ACTIVE  LOW
# define DEFAULT_CTS_INACTIVE  HIGH
# define DEFAULT_RTS_ACTIVE  LOW
# define DEFAULT_RTS_INACTIVE  HIGH
# define DEFAULT_RI_ACTIVE  LOW
# define DEFAULT_RI_INACTIVE  HIGH
# define DEFAULT_DSR_ACTIVE  LOW
# define DEFAULT_DSR_INACTIVE  HIGH
# define DEFAULT_DTR_ACTIVE  LOW
# define DEFAULT_DTR_INACTIVE  HIGH
# define DEFAULT_OTH_ACTIVE  LOW
# define DEFAULT_OTH_INACTIVE  HIGH

#define MAX_PIN_NO 50
#define INTERNAL_FLOW_CONTROL_DIV 380
#define DEFAULT_RECONNECT_DELAY 60000
#define MAX_RECONNECT_DELAY 1800000

class ZMode
{
  public:
    virtual void serialIncoming();
    virtual void loop();
};

#include "pet2asc.h"
#include "rt_clock.h"
#include "filelog.h"
#include "serout.h"
#include "connSettings.h"
#include "wificlientnode.h"
#include "stringstream.h"
#include "phonebook.h"
#include "wifiservernode.h"
#include "zstream.h"
#include "proto_http.h"
#include "proto_ftp.h"
#include "vfd.h"
#include "zconfigmode.h"
#include "zcommand.h"
#include "zprint.h"

#if INCLUDE_SD_SHELL
#  if INCLUDE_HOSTCM
#    include "zhostcmmode.h"
#  endif
#  if INCLUDE_FTP
#    include "zcomet64mode.h"
#  endif
#  include "proto_xmodem.h"
#  include "proto_zmodem.h"
#  include "proto_punter.h"
#  include "proto_kermit.h"
#  include "zbrowser.h"
#endif
#if INCLUDE_SLIP
#  include "zslipmode.h"
#endif
#if INCLUDE_PPP
#  include "zpppmode.h"
#endif
#if INCLUDE_IRCC
#  include "zircmode.h"
#endif

static WiFiClientNode *conns = null;
static WiFiServerNode *servs = null;
static PhoneBookEntry *phonebook = null;
static bool pinSupport[MAX_PIN_NO];
static int pinCache[MAX_PIN_NO];
static String termType = DEFAULT_TERMTYPE;
static String busyMsg = DEFAULT_BUSYMSG;
static bool debugUart = false;

static OpModes altOpMode = OPMODE_NONE;
static ZMode *currMode = null;
static ZStream streamMode;
static ZCommand commandMode;
static ZPrint printMode;
static ZConfig configMode;
static RealTimeClock zclock(0);
#if INCLUDE_SD_SHELL
#  if INCLUDE_HOSTCM
     static ZHostCMMode hostcmMode;
#  endif
#  if INCLUDE_FTP
     static ZComet64Mode comet64Mode;
#  endif
   static ZBrowser browseMode;
#endif
#if INCLUDE_SLIP
   static ZSLIPMode slipMode;
#endif
#if INCLUDE_PPP
   static ZPPPMode pppMode;
#endif
#if INCLUDE_IRCC
   static ZIRCMode ircMode;
#endif

enum BaudState
{
  BS_NORMAL,
  BS_SWITCH_TEMP_NEXT,
  BS_SWITCHED_TEMP,
  BS_SWITCH_NORMAL_NEXT
};

static String wifiSSI;
static String wifiPW;
static String hostname;
static IPAddress *staticIP = null;
static IPAddress *staticDNS = null;
static IPAddress *staticGW = null;
static IPAddress *staticSN = null;
static unsigned long lastConnectAttempt = 0;
static unsigned long nextReconnectDelay = 0; // zero means don't attempt reconnects
static SerialConfig serialConfig = DEFAULT_SERIAL_CONFIG;
static int baudRate=DEFAULT_BAUD_RATE;
// Exposed read-only for the VFD status display (vfd.ino) - reflects whether
// the SD shell is actually usable, decided once at startup by initSDShell()
// (zbrowser.ino), not a live-polled card presence check.
static bool sdShellAvailable = false;
static int calcDequeSize(int forBaudRate)
{
  // Unclamped, this grows past SER_BUFSIZE at high baud rates (e.g. 304 at
  // 115200 vs SER_BUFSIZE=127/128), making the "(SER_BUFSIZE -
  // availableForWrite()) < dequeSize" throttle in serialOutDeque() trivially
  // always-true -- i.e. a silent no-op -- for every baud rate this project
  // has ever offered above ~48260 baud. That let one serialOutDeque() call
  // drain the whole TX ring buffer in a single pass instead of trickling it,
  // which under real hardware RTS/CTS flow control (see the MAX3237/generic-
  // level-shifter bug report) queued far more data at once than the far end
  // could keep up with, producing exactly the delayed/misaligned multi-
  // response bursts observed in testing. Clamping keeps the throttle
  // meaningful at any baud rate.
  int size = 1+(forBaudRate/INTERNAL_FLOW_CONTROL_DIV);
  if(size > SER_BUFSIZE-1)
    size = SER_BUFSIZE-1;
  return size;
}
static int dequeSize=calcDequeSize(DEFAULT_BAUD_RATE);
static BaudState baudState = BS_NORMAL; 
static unsigned long resetPushTimer=0;
static int tempBaud = -1; // -1 do nothing
static unsigned int plussesInARow = 0;
static unsigned long lastInputTimeMs = 0;
static int dcdStatus = DEFAULT_DCD_INACTIVE;
static int pinDCD = DEFAULT_PIN_DCD;
static int pinCTS = DEFAULT_PIN_CTS;
static int pinRTS = DEFAULT_PIN_RTS;
static int pinDSR = DEFAULT_PIN_DSR;
static int pinDTR = DEFAULT_PIN_DTR;
static int pinOTH = DEFAULT_PIN_OTH;
static int pinRI = DEFAULT_PIN_RI;
static int dcdActive = DEFAULT_DCD_ACTIVE;
static int dcdInactive = DEFAULT_DCD_INACTIVE;
static int ctsActive = DEFAULT_CTS_ACTIVE;
static int ctsInactive = DEFAULT_CTS_INACTIVE;
static int rtsActive = DEFAULT_RTS_ACTIVE;
static int rtsInactive = DEFAULT_RTS_INACTIVE;
static int riActive = DEFAULT_RI_ACTIVE;
static int riInactive = DEFAULT_RI_INACTIVE;
static int dtrActive = DEFAULT_DTR_ACTIVE;
static int dtrInactive = DEFAULT_DTR_INACTIVE;
static int dsrActive = DEFAULT_DSR_ACTIVE;
static int dsrInactive = DEFAULT_DSR_INACTIVE;
static int othActive = DEFAULT_OTH_ACTIVE;
static int othInactive = DEFAULT_OTH_INACTIVE;

static int getDefaultCtsPin()
{
  return DEFAULT_PIN_CTS;
}

static void doNothing(const char* format, ...) 
{
}

static void s_pinWrite(uint8_t pinNo, uint8_t value)
{
  if(pinSupport[pinNo])
  {
    pinCache[pinNo] = value;
    digitalWrite(pinNo, value);
  }
}

static void setHostName(const char *hname)
{
#ifdef ZIMODEM_ESP32
  #ifdef TCPIP_ADAPTER_IF_STA
      tcpip_adapter_set_hostname(TCPIP_ADAPTER_IF_STA, hname);
  #else
      WiFi.setHostname(hname);
  #endif
#else
      WiFi.hostname(hname);
#endif
}

static void setNewStaticIPs(IPAddress *ip, IPAddress *dns, IPAddress *gateWay, IPAddress *subNet)
{
  if(staticIP != null)
    free(staticIP);
  staticIP = ip;
  if(staticDNS != null)
    free(staticDNS);
  staticDNS = dns;
  if(staticGW != null)
    free(staticGW);
  staticGW = gateWay;
  if(staticSN != null)
    free(staticSN);
  staticSN = subNet;
}

static bool connectWifi(const char* ssid, const char* password, IPAddress *ip, IPAddress *dns, IPAddress *gateWay, IPAddress *subNet)
{
  while(WiFi.status() == WL_CONNECTED)
  {
    WiFi.disconnect();
    delay(100);
    yield();
  }
#ifndef ZIMODEM_ESP32
  if(hostname.length() > 0)
    setHostName(hostname.c_str());
#endif
  WiFi.mode(WIFI_STA);
  if((ip != null)&&(gateWay != null)&&(dns != null)&&(subNet!=null))
  {
    if(!WiFi.config(*ip,*gateWay,*subNet,*dns))
      return false;
  }
  WiFi.begin(ssid, password);
#if defined(ARDUINO_MAKERGO_C3_SUPERMINI) || defined(ARDUINO_NOLOGO_ESP32C3_SUPER_MINI)
  WiFi.setTxPower(WIFI_POWER_8_5dBm);
#endif
  if(hostname.length() > 0)
    setHostName(hostname.c_str());
  bool amConnected = (WiFi.status() == WL_CONNECTED) && (strcmp(WiFi.localIP().toString().c_str(), "0.0.0.0")!=0);
  int WiFiCounter = 0;
  while ((!amConnected) && (WiFiCounter < 20))
  {
    WiFiCounter++;
    if(!amConnected)
      delay(500);
    amConnected = (WiFi.status() == WL_CONNECTED) && (strcmp(WiFi.localIP().toString().c_str(), "0.0.0.0")!=0);
  }
  lastConnectAttempt = millis();
  if(lastConnectAttempt == 0)  // it IS possible for millis() to be 0, but we need to ignore it.
    lastConnectAttempt = 1; // 0 is a special case, so skip it

  if(!amConnected)
  {
    nextReconnectDelay = 0; // assume no retry is desired.. let the caller set it up, as it could be bad PW
    WiFi.disconnect();
  }
  else
    nextReconnectDelay = DEFAULT_RECONNECT_DELAY; // if connected, we always want to try reconns in the future

#if SUPPORT_LED_PINS
# ifndef ENGMODEM_MINI_BOARD
  s_pinWrite(DEFAULT_PIN_WIFI,(WiFi.status() == WL_CONNECTED)?DEFAULT_WIFI_ACTIVE:DEFAULT_WIFI_INACTIVE);
# endif
  // On ENGMODEM_MINI_BOARD, DEFAULT_PIN_WIFI is the board's "OH" (off-hook)
  // LED, not a WiFi-association indicator - left untouched here and driven
  // instead by checkOpenConnections() based on actual open connections
  // (telnet/SSH/FTP/etc, not WiFi association). See that function.
#endif
  if(WiFi.status() == WL_CONNECTED)
    debugPrintf("Connected to %s with IP %s.\r\n",ssid,WiFi.localIP().toString().c_str());
  return (WiFi.status() == WL_CONNECTED);
}

static void checkBaudChange()
{
  switch(baudState)
  {
    case BS_SWITCH_TEMP_NEXT:
      changeBaudRate(tempBaud);
      baudState = BS_SWITCHED_TEMP;
      break;
    case BS_SWITCH_NORMAL_NEXT:
      changeBaudRate(baudRate);
      baudState = BS_NORMAL;
      break;
    default:
      break;
  }
}

static void changeBaudRate(int baudRate)
{
  flushSerial(); // blocking, but very very necessary
  delay(500); // give the client half a sec to catch up
  logPrintfln("Baud change to %d.",baudRate);
  dequeSize=calcDequeSize(baudRate);
  debugPrintf("Baud %d, Deque constant now: %d\r\n",baudRate,dequeSize);
#ifdef ZIMODEM_ESP32
  HWSerial.updateBaudRate(baudRate);
#else
  HWSerial.begin(baudRate, serialConfig);  //Change baud rate
#endif
#if SUPPORT_LED_PINS
  s_pinWrite(DEFAULT_PIN_HS,(baudRate>=DEFAULT_HS_BAUD)?DEFAULT_HS_ACTIVE:DEFAULT_HS_INACTIVE);
#endif  
}

static void changeSerialConfig(SerialConfig conf)
{
  flushSerial(); // blocking, but very very necessary
  delay(500); // give the client half a sec to catch up
  debugPrintf("Config changing to %dbps, %d.\r\n",baudRate,(int)conf);
  dequeSize=calcDequeSize(baudRate);
  debugPrintf("Deque constant now: %d\r\n",dequeSize);
# ifdef DEFAULT_PIN_RXD
    debugPrintf("Using BPS %d, RXD %d, TXD %d\r\n",baudRate,DEFAULT_PIN_RXD, DEFAULT_PIN_TXD);
    HWSerial.begin(baudRate, conf, DEFAULT_PIN_RXD, DEFAULT_PIN_TXD);
# else
    HWSerial.begin(baudRate, conf);  //Change baud rate
# endif
  debugPrintf("Config changed.\r\n");
}

static int checkOpenConnections()
{
  int num=WiFiClientNode::getNumOpenWiFiConnections();
  if(num == 0)
  {
    if((dcdStatus == dcdActive)
    &&(dcdStatus != dcdInactive))
    {
      dcdStatus = dcdInactive;
      s_pinWrite(pinDCD,dcdStatus);
      if(baudState == BS_SWITCHED_TEMP)
        baudState = BS_SWITCH_NORMAL_NEXT;
      if(currMode == &commandMode)
        clearSerialOutBuffer();
    }
#if SUPPORT_LED_PINS && defined(ENGMODEM_MINI_BOARD)
    // Off-hook LED: no open connections of any kind (telnet/SSH/FTP/IRC/print).
    s_pinWrite(DEFAULT_PIN_WIFI,DEFAULT_WIFI_INACTIVE);
#endif
  }
  else
  {
    if((dcdStatus == dcdInactive)
    &&(dcdStatus != dcdActive))
    {
      dcdStatus = dcdActive;
      s_pinWrite(pinDCD,dcdStatus);
      if((tempBaud > 0) && (baudState == BS_NORMAL))
        baudState = BS_SWITCH_TEMP_NEXT;
    }
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
void loop() 
{
  checkFactoryReset();
  checkReconnect();
  vfdLoop();
  if(HWSerial.available())
  {
    currMode->serialIncoming();
  }
  currMode->loop();
  zclock.tick();
}

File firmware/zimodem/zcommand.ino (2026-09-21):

/*
   Copyright 2016-2026 Bo Zimmerman

   Licensed under the Apache License, Version 2.0 (the "License");
   you may not use this file except in compliance with the License.
   You may obtain a copy of the License at

	   http://www.apache.org/licenses/LICENSE-2.0

   Unless required by applicable law or agreed to in writing, software
   distributed under the License is distributed on an "AS IS" BASIS,
   WITHOUT WARRANTIES OR CONDITIONS OF ANY KIND, either express or implied.
   See the License for the specific language governing permissions and
   limitations under the License.
*/
extern "C" void esp_schedule();
extern "C" void esp_yield();

#if INCLUDE_PING
#  include "proto_ping.h"
#endif

ZCommand::ZCommand()
{
  strcpy(CRLF,"\r\n");
  strcpy(LFCR,"\n\r");
  strcpy(LF,"\n");
  strcpy(CR,"\r");
  strcpy(ECS,"+++");
  freeCharArray(&tempMaskOuts);
  freeCharArray(&tempDelimiters);
  freeCharArray(&tempStateMachine);
  setCharArray(&delimiters,"");
  setCharArray(&maskOuts,"");
  setCharArray(&stateMachine,"");
  machineState = stateMachine;
}

static void parseHostInfo(uint8_t *vbuf, char **hostIp, int *port, char **username, char **password)
{
  char *at=strstr((char *)vbuf,"@");
  *hostIp = (char *)vbuf;
  if(at != null)
  {
    *at = 0;
    *hostIp = at+1;
    char *ucol = strstr((char *)vbuf,":");
    *username = (char *)vbuf;
    if(ucol != null)
    {
      *ucol = 0;
      *password = ucol + 1;
    }
  }
  char *colon=strstr(*hostIp,":");
  if(colon != null)
  {
    (*colon)=0;
    *port=atoi((char *)(++colon));
  }
}

static bool validateHostInfo(uint8_t *vbuf)
{
  String cmd = (char *)vbuf;
  int atDex=cmd.indexOf('@');
  int colonDex=cmd.indexOf(':');
  int lastColonDex=cmd.lastIndexOf(':');
  bool fail = cmd.indexOf(',') >= 0;
  if(atDex >=0)
  {
    colonDex=cmd.indexOf(':',atDex+1);
    fail = cmd.indexOf(',') >= atDex;
  }
  fail = fail || (colonDex <= 0) || (colonDex == cmd.length()-1);
  fail = fail || (colonDex != cmd.lastIndexOf(':'));
  if(!fail)
  {
    for(int i=colonDex+1;i<cmd.length();i++)
    {
      if(strchr("0123456789",cmd[i]) == 0)
      {
        fail=true;
        break;
      }
    }
  }
  return !fail;
}

void ZCommand::reset()
{
  doResetCommand(true);
  if(altOpMode == OPMODE_NONE)
    showInitMessage();
}

byte ZCommand::CRC8(const byte *data, byte len) 
{
  byte crc = 0x00;
  //logPrint("CRC8: ");
  int c=0;
  while (len--) 
  {
    byte extract = *data++;
    /* save for later debugging
    if(logFileOpen)
    {
        logFile.print(TOHEX(extract));
        if((++c)>20)
        {
          logFile.print("\r\ncrc8: ");
          c=0;
        }
        else
          logFile.print(" ");
    }
    */
    for (byte tempI = 8; tempI; tempI--) 
    {
      byte sum = (crc ^ extract) & 0x01;
      crc >>= 1;
      if (sum) {
        crc ^= 0x8C;
      }
      extract >>= 1;
    }
  }
  logPrintf("\r\nFinal CRC8: %s\r\n",TOHEX(crc));
  return crc;
}

void ZCommand::setConfigDefaults()
{
  altOpMode = OPMODE_NONE;
  doEcho=true;
  busyMode=false;
  autoStreamMode=false; // should prob have been true all along, ats0 takes care of this.
  telnetSupport=true;
  preserveListeners=false;
  ringCounter=1;
  streamMode.setHangupType(HANGUP_NONE);
  serial.setFlowControlType(DEFAULT_FCT);
  serial.setXON(true);
  packetXOn = true;
# if INCLUDE_CMDRX16
    packetXOn = false;
# endif
  serial.setPetsciiMode(false);
  binType=BTYPE_NORMAL;
  serialDelayMs=0;
  dcdActive=DEFAULT_DCD_ACTIVE;
  dcdInactive=DEFAULT_DCD_INACTIVE;
# ifdef HARD_DCD_HIGH
  dcdInactive=DEFAULT_DCD_ACTIVE;
# elif defined(HARD_DCD_LOW)
  dcdActive=DEFAULT_DCD_INACTIVE;
# endif 
  ctsActive=DEFAULT_CTS_ACTIVE;
  ctsInactive=DEFAULT_CTS_INACTIVE;
  rtsActive=DEFAULT_RTS_ACTIVE;
  rtsInactive=DEFAULT_RTS_INACTIVE;
  riActive = DEFAULT_RTS_ACTIVE;
  riInactive = DEFAULT_RTS_INACTIVE;
  dtrActive = DEFAULT_RTS_ACTIVE;
  dtrInactive = DEFAULT_RTS_INACTIVE;
  dsrActive = DEFAULT_RTS_ACTIVE;
  dsrInactive = DEFAULT_RTS_INACTIVE;
  othActive = DEFAULT_OTH_ACTIVE;
  othInactive = DEFAULT_OTH_INACTIVE;
  pinDCD = DEFAULT_PIN_DCD;
  pinCTS = DEFAULT_PIN_CTS;
  pinRTS = DEFAULT_PIN_RTS;
  pinDTR = DEFAULT_PIN_DTR;
  pinOTH = DEFAULT_PIN_OTH;
  pinDSR = DEFAULT_PIN_DSR;
  pinRI = DEFAULT_PIN_RI;
  dcdStatus = dcdInactive;
  if(pinSupport[pinRTS])
    pinMode(pinRTS,OUTPUT);
  if(pinSupport[pinCTS])
    pinMode(pinCTS,INPUT);
  if(pinSupport[pinDCD])
    pinMode(pinDCD,OUTPUT);
  if(pinSupport[pinDTR])
    pinMode(pinDTR,INPUT);
  if(pinSupport[pinOTH])
    pinMode(pinOTH,INPUT);
  if(pinSupport[pinDSR])
    pinMode(pinDSR,OUTPUT);
  if(pinSupport[pinRI])
    pinMode(pinRI,OUTPUT);
  s_pinWrite(pinRTS,rtsActive);
  s_pinWrite(pinDCD,dcdStatus);
  s_pinWrite(pinDSR,dsrActive);
  s_pinWrite(pinRI,riInactive);
  suppressResponses=false;
  numericResponses=false;
  longResponses=true;
  packetSize=127;
  strcpy(CRLF,"\r\n");
  strcpy(LFCR,"\n\r");
  strcpy(LF,"\n");
  strcpy(CR,"\r");
  EC='+';
  strcpy(ECS,"+++");
  BS=8;
  EOLN = CRLF;
  tempBaud = -1;
  freeCharArray(&tempMaskOuts);
  freeCharArray(&tempDelimiters);
  freeCharArray(&tempStateMachine);
  setCharArray(&delimiters,"");
  setCharArray(&stateMachine,"");
  machineState = stateMachine;
  termType = DEFAULT_TERMTYPE;
  busyMsg = DEFAULT_BUSYMSG;
#if SUPPORT_LED_PINS
  if(pinSupport[DEFAULT_PIN_AA])
  {
    pinMode(DEFAULT_PIN_AA,OUTPUT);
    digitalWrite(DEFAULT_PIN_AA, DEFAULT_AA_INACTIVE);
  }
  if(pinSupport[DEFAULT_PIN_WIFI])
  {
    pinMode(DEFAULT_PIN_WIFI,OUTPUT);
    digitalWrite(DEFAULT_PIN_WIFI, DEFAULT_WIFI_INACTIVE);
  }
  if(pinSupport[DEFAULT_PIN_HS])
  {
    pinMode(DEFAULT_PIN_HS,OUTPUT);
    digitalWrite(DEFAULT_PIN_HS, DEFAULT_HS_INACTIVE);
  }
#endif
}

char lc(char c)
{
  if((c>=65) && (c<=90))
    return c+32;
  if((c>=193) && (c<=218))
    return c-96;
  return c;
}

void ZCommand::connectionArgs(WiFiClientNode *c)
{
  setCharArray(&(c->delimiters),tempDelimiters);
  setCharArray(&(c->maskOuts),tempMaskOuts);
  setCharArray(&(c->stateMachine),tempStateMachine);
  freeCharArray(&tempDelimiters);
  freeCharArray(&tempMaskOuts);
  freeCharArray(&tempStateMachine);
  c->machineState = c->stateMachine;
}

ZResult ZCommand::doResetCommand(bool resetOpMode)
{
  while(conns != null)
  {
    WiFiClientNode *c=conns;
    delete c;
  }
  current = null;
  nextConn = null;
  WiFiServerNode::DestroyAllServers();
  OpModes oldMode = altOpMode;
  setConfigDefaults();
  String argv[CFG_LAST+1];
  parseConfigOptions(argv);
  eon=0;
  serial.setXON(true);
  packetXOn = true;
# if INCLUDE_CMDRX16
    packetXOn = false;
# endif
  serial.setPetsciiMode(false);
  serialDelayMs=0;
  binType=BTYPE_NORMAL;
  serial.setFlowControlType(DEFAULT_FCT);
  if(!resetOpMode)
    argv[CFG_ALTOPMODE] = String(oldMode);
   setOptionsFromSavedConfig(argv);
  memset(nbuf,0,MAX_COMMAND_SIZE);
  busyMode=false;
  return ZOK;
}
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

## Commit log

2026-09-03 Initial upload: EngModem Mini KiCad project (Rev4)
    Preliminary hardware, not yet fabricated or bench-tested. See README
    for disclaimer, verification status, and revision history.
    Runs Bo Zimmerman's Zimodem via the Zimodem-VFD fork.
    [EngModem_Modular_Routed_Rev4.kicad_pcb, EngModem_Modular_Routed_Rev4.kicad_sch]
2026-09-03 Replace copper/silk plots with 3D board renders
    Front/back isometric 3D renders (kicad-cli pcb render, high quality)
    instead of flat F.Cu/B.Cu+silk SVG plots.
2026-09-03 Add manufacturing outputs: Gerbers + JLCPCB BOM
    Gerber/Excellon drill export for Rev4, plus a JLCPCB-oriented SMD BOM
    with LCSC part numbers verified against LCSC's own listings (ICs,
    regulators, ESP32 module, microSD socket, inductor), and a full BOM
    covering the through-hole connectors/headers/LED positions for
    hand-assembly. No CPL yet - Gerbers+BOM cover bare-board fab and
    hand assembly; full JLCPCB PCBA needs a placement file added later.
    [BOM_PCBA_JLCPCB.csv, BOM_full.csv]
2026-09-03 Add CPL for full JLCPCB PCBA ordering
    SMD-only placement file (Designator/Mid X/Mid Y/Layer/Rotation),
    generated from the PCB's real component coordinates. Gerbers + BOM +
    CPL together now cover a full JLCPCB assembly order. README flags
    that rotation should still be spot-checked in JLCPCB's own assembly
    preview before ordering - their library match can use a different
    0deg reference than KiCad's footprint does.
    [CPL_SMD.csv]
2026-09-04 Exclude U3/U5 from PCBA, add verified hand-solder replacements
    JLCPCB's placement preview surfaced a real footprint mismatch on both
    regulators (originally spec'd parts don't reliably match this board's
    3-lead D2PAK/TO-263-3 footprint - confirmed against LCSC listings and,
    for U5, ST's own datasheet showing an ambiguous 2-lead/3-lead order
    code). Removed both from BOM_PCBA_JLCPCB.csv and CPL_SMD.csv.
    BOM_full.csv now carries verified drop-in replacements to hand-solder
    instead, confirmed against each manufacturer's own datasheet (not
    distributor listings): onsemi MC7805CD2TR4G for U3, TI
    LM1086CSX-3.3/NOPB for U5 - both exact pin/tab matches for this
    board's footprint and schematic, sourced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
    [BOM_PCBA_JLCPCB.csv, BOM_full.csv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]
2026-09-04 Add PIN_MAP.md and CHANGES.md, documenting U3/U5 substitution
    New hardware-side docs mirroring the firmware repo's convention:
    PIN_MAP.md covers external connectors (DE-9, VFD header, microSD) and
    power regulation, cross-referencing the firmware repo's GPIO-level
    PIN_MAP.md rather than duplicating it. CHANGES.md is a proper
    changelog expanding on the README's revision-history table, with full
    detail on the U3/U5 regulator substitution and the manufacturing
    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
2026-09-04 Rev5: U2 via stitching/keepout, plus enclosure panel jigs
    Hardware: replaces Rev4 with Rev5 (9 through vias + mirrored bottom
    pads under U2's ground-pad cluster for bottom-side hand-solder access,
    keepout zone, full rip/reroute). Manufacturing outputs (Gerbers, BOM,
    CPL) updated to match; board renders regenerated.
    New: enclosure/ - 3D-printable drill and router-template jigs for the
    Hammond 1455U2201BK front (VFD window, LEDs, mounting holes) and rear
    (DB9 draft) panels, with their own preliminary-hardware disclaimer.
    Neither the board nor the jigs have been built/fitted yet - see each
    README for current verification status.
    [1455U2201_REAL_bezel.stl, 1455U2201_REAL_end_panel.stl, BOM_PCBA_JLCPCB.csv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]
2026-09-08 Sync enclosure: rear panel jigs (USB-C/switches/SMA), layout renders, LED labels
    Replaces the old DB9-only rear panel jigs with the combined set covering
    DB9, USB-C, boot/reset, power switch/jack, and the external antenna
    connector - positions/clearances checked against the real internal
    floor rail extracted from Hammond's own STEP file. Adds the dimensioned
    front/rear panel layout renders and LED_LABELS.md (the 8 LED functions
    traced through the schematic, plus the F-Engrave/V-bit plan for the
    2-letter panel labels). enclosure/README.md and the top-level README
    updated to match - this brings the repo in line with local work that
    had only been shared as files up to now.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
    [rear_panel_drill_guide.stl, rear_panel_drill_guide_2_offset.stl, rear_panel_drill_guide_db9.stl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]
2026-09-21 Add qualified firmware (firmware-v4-rev1) with binaries and QA scripts
    Adds firmware/: the Zimodem-VFD fork specialised for this board
    (ENGMODEM_MINI_BOARD), the exact binaries flashed during hardware
    qualification with SHA-256 checksums, and the Python QA scripts used.
    Fixes made to the firmware while qualifying Rev5 (details in
    firmware/CHANGES.md):
    - v2: RTS/CTS pin roles were reversed for this PCB's DCE wiring; saved
    config no longer moves the RTS/CTS pins; boot diagnostic line.
    - v3: DTR input (GPIO4) was never configured; RTS pin left deasserted
    after leaving RTS/CTS mode.
    - v4: serial-to-TCP bytes were sent one per segment, stalling bursts;
    now coalesced.
    Documentation correct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
2026-09-21 Add hardware qualification, builder docs and errata for the built Rev5 board
    - docs/QUALIFICATION.md: bench qualification results by firmware revision,
    defects found, and an explicit list of what was not tested.
    - docs/BRING_UP.md: builder's guide (jumpers, first power, flashing,
    cabling, checks, troubleshooting).
    - docs/J12_CABLE_GUIDE.md: J12 is AT/Everex order; DTK/Intel cables fail.
    - docs/ERRATA.md: known issues and suggestions for a future revision.
    - README: replace the "not fabricated" disclaimer with a qualified-status
    section; correct the design-stage "18/18" cross-check claim (it did not
    check signal direction); point at firmware/ and docs/.
    - CHANGES/PIN_MAP: fix links to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
    [BOM_full.csv]
2026-09-21 Add .gitattributes so SHA256SUMS.txt stays LF on Windows checkouts
    On Windows with core.autocrlf=true, checking out firmware/bin/SHA256SUMS.txt
    converted it to CRLF, so 'sha256sum -c' failed with "No such file"
    (the filenames ended in a carriage return). The file stored on GitHub was
    already LF; only Windows checkouts were affected.
    - firmware/bin/SHA256SUMS.txt: text eol=lf
    - *.bin: binary (never line-ending converted)
    Verified: a fresh checkout now has 0 CR bytes and all four checksums pass;
    git add --renormalize changes no other file.
2026-09-22 Firmware v6b-rev1: VFD resync init, AA/HS/OH LED polarity, applied RX buffer
    Updates firmware/ from firmware-v4-rev1 to firmware-v6b-rev1 (locked, qualified on the
    built Rev5 unit). Source changes (ENGMODEM_MINI_BOARD only):
    - vfd.ino: resync-first init, 50 us wait after every instruction, re-init about once a
    second during the splash window (older init scrambled the display after about half of
    ESP32 restarts; 0 of ~40 with this).
    - zimodem.ino: AA/HS/OH active levels HIGH (they were inverted); setRxBufferSize() now
    called BEFORE begin() - the core rejects it afterwards, so the UART buffer had always
    been the 256-byte default (also true of v4-rev1).
    - zstream.h/.ino: stream loop han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
    [qa_common.py, qa_losscurve.py, qa_pace_noecho.py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]
2026-09-22 Docs: LED inversion, VFD and receive-buffer errata, v6b re-qualification, LED position test
    - ERRATA: E8 rewritten (VFD scrambled after resets, fixed in v5), new E11 (most front-panel
    LEDs read inverted; check LED order at assembly; proposed inverting-U4 fix, explicitly not
    yet built or verified) and E12 (receive buffer was 256 bytes; fixed in v6b; flow-off limit).
    - QUALIFICATION: new defects 6-9 and a section 5 re-qualification on v6b-rev1, including a
    native COM1 versus USB adapter comparison and what is still unverified.
    - BRING_UP: corrected LED guidance (the old text wrongly implied OH/CD light while connected);
    idle panel and expected behaviour on Rev5 as built.
    - README/CHANG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
    [led_position_test.ino]
2026-09-22 ERRATA E11: add PCB/schematic proof the LED position swap isn't a board defect
    The existing wording ("fitted in swapped positions", "at assembly", "on the tested
    unit") already scoped the position 3/4 mixup to this one hand-assembled unit, not the
    board design - but it never stated the supporting evidence. Adds it explicitly: the
    Rev5 KiCad PCB's eight LED footprints sit at a uniform 5.5 mm pitch in exact D8-to-D1
    order, and each designator's net traces straight through to the signal its position
    implies, with no gaps or reversals. So the swap was an assembly-time LED insertion
    mistake (wrong part in the D5/D6 holes), not a layout fault.
    No other content changed; the distinct, genuinely boa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
2026-09-22 Publish firmware-v7-rev1: SSH term-type fix, document virgin-boot RTS stall
    wifisshclient.ino passed the literal string "vanilla" to
    libssh2_channel_request_pty() instead of the AT&S41-configured term type,
    so SSH sessions never honoured it (Telnet's own TERMTYPE negotiation was
    unaffected). Fixed and verified against a local test SSH server logging
    the pty-req TERM value it receives.
    Full regression re-run turned up a second, pre-existing issue: on a
    genuinely fresh boot, with flow control off (default) and the PC's RTS
    line low, the modem never answers until AT&K3 is issued once - not a
    brief delay, no response at all within 20+ seconds tested. Reproduced
    identically on firmware-v4-rev1 a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
    [wifisshclient.ino]
2026-09-22 ERRATA E13: note the fresh-boot RTS stall also reproduces on native COM1
    Re-ran the exact same qa_freshboot_rts.py check through the PC's native
    16550 UART (COM1) instead of the USB-FTDI adapter (COM15) - identical
    result (fast RTS-high control, 6s timeout on RTS-low/virgin-boot, clean
    recovery after AT&K3/AT&K0). Rules out the USB-serial interface as the
    cause; the bug is on the modem board's side either way.
2026-09-23 Remove the fresh-boot RTS-stall narrative; replace with a generic tip
    The apparent virgin-boot RTS/CTS stall (previously documented as ERRATA
    E13, qualification defect #10, and a dedicated regression script) turned
    out not to be a real, reproducible firmware/hardware defect: after a
    full esptool erase-flash and reflash, 11/11 fresh-boot tests passed with
    no failures, on the same firmware. The most likely explanation is a
    transient/rework-related condition (a full chip erase clears far more
    than an app-image-only reflash ever does) rather than a genuine defect
    worth documenting as a known issue.
    Removed: ERRATA E13, qualification defect #10 and section 6's RTS-stall
    content, the "known limit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
2026-09-24 Document recommended baud rate: 230400 where supported, else 115200
    Measured connected-mode throughput is flat from 230400 to 921600, so higher
    rates add little. 115200 is the universal floor; 230400 is the fastest
    guaranteed rate on UARTs that accept custom rates above 115200.
2026-09-29 LED test: confirm U4 (CD74HCT640) polarity fix, steady 5s per LED
    U4_INVERTING is now set to 1 - the ESP32-S3-WROOM-1U/74HCT245->CD74HCT640
    swap has been done on the physical board (a pad was pulled during
    desoldering and repaired at the trace/pad level). Switches the sketch from
    a 3s blink (needed to tell "driven" from "stuck" during the position-order
    test) to a steady 5s on/off per LED, matching how this run is actually
    being used: confirming polarity, not position. Adds the PCB designator
    (D8..D1) to the VFD readout alongside the 1-8 position number.
    TR and RD are still MAX3237-driven inputs, unaffected by the U4 swap, and
    still shown as live pin level rather than driven.
    Co-Authored-B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
    [led_position_test.ino]
2026-09-30 Confirm U4 fix on hardware; update BOM and all docs (ERRATA E11 fixed)
    Hardware confirmation: U4 hand-swapped from the originally-placed
    non-inverting 74HCT245 to a pin-compatible inverting TI CD74HCT640M,
    verified via the updated led_position_test tool (also switched to a
    3-second steady-on interval per LED, from the earlier 5s). MR, SD and CD
    now light correctly.
    Also updates the sketch/tool docs, ERRATA E11 (marked fixed, with the
    LCSC C1548168 stock finding - 0 direct stock, ~3000 via Other Suppliers,
    9-18 business day lead as of 2026-09-29), QUALIFICATION.md's defect #8,
    both top-level READMEs, firmware/PIN_MAP.md, firmware/CHANGES.md,
    enclosure/LED_LABELS.md, and the manufacturing BOM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
    [BOM_PCBA_JLCPCB.csv, BOM_full.csv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]
2026-09-30 Update the schematic: U4 symbol/value to CD74HCT640M
    Adds a CD74HCT640M symbol to the RetroWiFiModem library (a sibling of the
    existing 74HCT245 derived symbol, both extend the same base 74LS245A
    graphic - the two parts are pin/pinout-identical, only the buffer
    direction differs) and repoints U4's schematic instance at it, updating
    both the live lib_id and the schematic's embedded lib_symbols cache.
    Validated before committing: ERC produces the identical 32 violations
    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
    [EngModem_Modular_Routed_Rev5.kicad_sch]
2026-09-30 Add .gitignore for local build/pycache artifacts
    Nothing was ever committed accidentally; this just keeps
    tools/led_position_test's local build/ output and the QA scripts'
    __pycache__ out of git status going forward.
